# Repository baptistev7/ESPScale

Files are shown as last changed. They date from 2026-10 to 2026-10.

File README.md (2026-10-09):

# ESP Scale — balance connectée pour silo à granulés

Une balance sur batterie qui pèse un **silo à granulés** posé sur 4 pieds, affiche
le stock sur un **écran e-paper** et le publie en **MQTT** pour **Home
Assistant** (stock, consommation, coût des remplissages). Elle dort presque tout
le temps : deux mesures par jour, calées sur l'aspiration de la chaudière.

| Écran principal | Hors de sa base (recharge) | Portail de réglages |
|---|---|---|
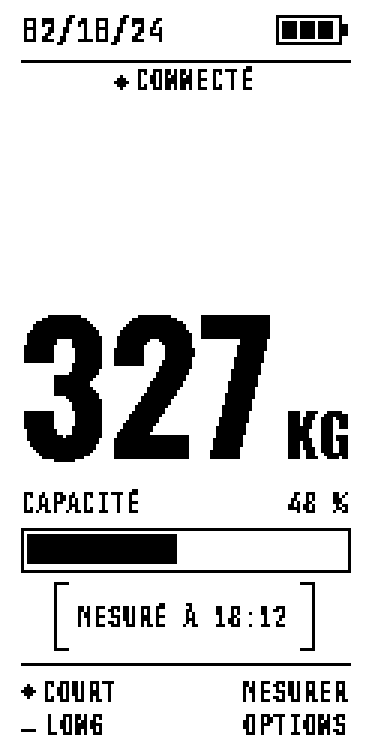
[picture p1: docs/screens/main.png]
Écran principal
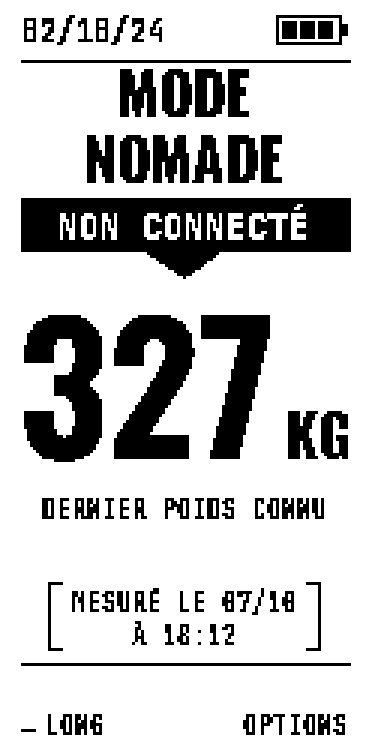
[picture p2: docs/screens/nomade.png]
Mode nomade
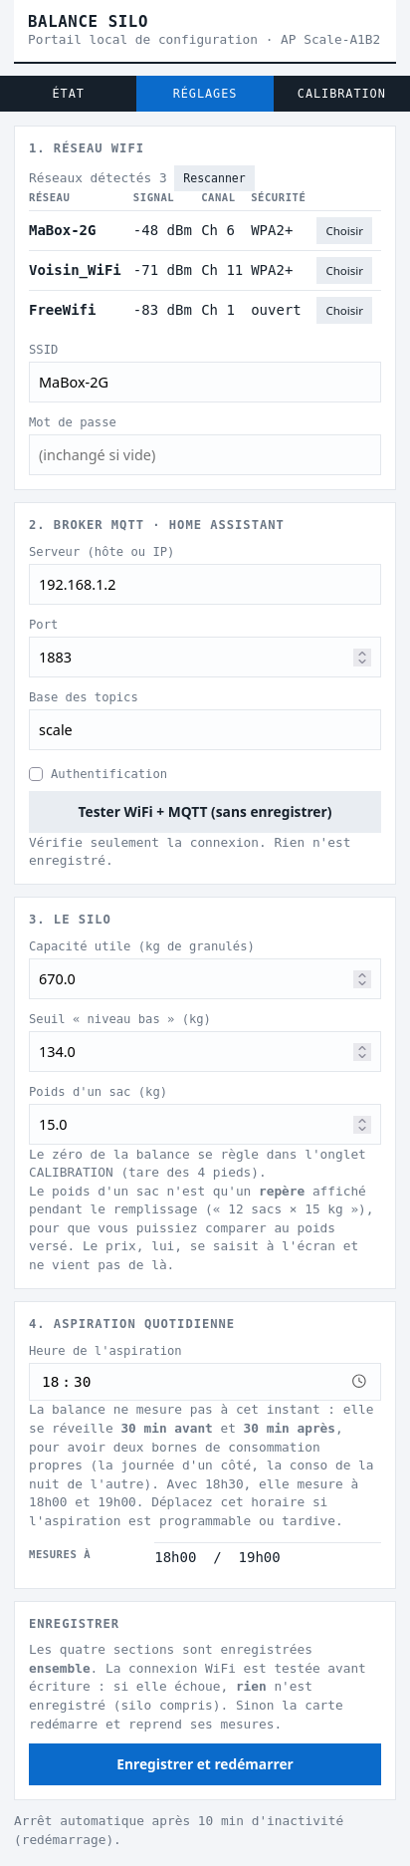
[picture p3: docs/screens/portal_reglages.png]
Portail web, onglet RÉGLAGES
|  |  |  |

**Version 1.0.1** — documentation en ligne : **<https://baptistev7.github.io/ESPScale/>**

## Ce qu'elle fait

- **Pèse le silo** avec 4 pieds (16 cellules de 50 kg, un HX711 par pied) et
  n'accepte une mesure que si **les 4 pieds répondent**.
- **Mesure 30 min avant et 30 min après l'aspiration** quotidienne (horaire
  réglable) pour séparer la consommation de la nuit des remplissages de la
  journée.
- **Publie en MQTT** seulement ce qui compte : les **baisses** (consommation) et
  les **remplissages** — jamais une dérive de capteur.
- **Guide le remplissage** sur place : nombre de sacs, prix, confirmation par
  appui maintenu ; Home Assistant valorise le stock en €.
- **Se recharge hors de sa base** : on retire le boîtier, on le branche en USB ;
  il le détecte, affiche la charge et revient tout seul à la normale une fois
  reposé.
- **Se règle sans recompiler** depuis un portail web embarqué (WiFi, MQTT,
  silo, calibration).

## Ce qu'il faut

- une carte **LilyGO T5 V2.4** 2.13" (ESP32 + écran e-paper intégré) ;
- **16 cellules de charge 50 kg** et **4 modules HX711** ;
- une **batterie LiPo** 1S, un connecteur **pogo**, deux résistances (1 MΩ et
  10 kΩ) ;
- le boîtier et la base imprimés en 3D (`case/v1/`) ;
- un broker **MQTT** et, idéalement, **Home Assistant**.

Détail : **[docs/MATERIEL.md](docs/MATERIEL.md)**.

## Démarrage

1. **Assembler et câbler** — pieds, base, boîtier, et les trois petites
   modifications de la carte : [MATERIEL.md](docs/MATERIEL.md).
2. **Flasher le firmware** (USB) avec [PlatformIO](https://platformio.org/) :

   ```bash
   ~/.platformio/penv/bin/pio run --target upload
   ```

   Pour une autre carte que celle du projet, mettre son identifiant de port dans
   `platformio.ini` (voir [CONFIGURATION.md](docs/CONFIGURATION.md#compiler-et-flasher)).
3. **Régler WiFi, MQTT et silo** — au premier démarrage, la balance ouvre un
   **portail web** : rejoindre le WiFi `Scale-XXXX` avec le mot de passe affiché
   à l'écran, puis `http://192.168.4.1` : [CONFIGURATION.md](docs/CONFIGURATION.md#le-portail-web).
4. **Calibrer les pieds** — onglet CALIBRATION du portail :
   [CALIBRATION.md](docs/CALIBRATION.md).
5. **Brancher Home Assistant** — packages prêts à l'emploi dans `ha/` :
   [MQTT-HOME-ASSISTANT.md](docs/MQTT-HOME-ASSISTANT.md).

Ensuite, au quotidien : **[le guide utilisateur](docs/GUIDE-UTILISATEUR.md)**.

## Documentation

Toute la documentation est publiée sur **<https://baptistev7.github.io/ESPScale/>**
(sources dans `docs/`).

| Document | Pour qui / pour quoi |
|---|---|
| [GUIDE-UTILISATEUR.md](docs/GUIDE-UTILISATEUR.md) | **Utiliser la balance** : écrans, bouton, remplissage, recharge |
| [MATERIEL.md](docs/MATERIEL.md) | Matériel, câblage, modifications de la carte, boîtier |
| [CONFIGURATION.md](docs/CONFIGURATION.md) | Flasher, portail web, réglages compilés (`config.hpp`) |
| [CALIBRATION.md](docs/CALIBRATION.md) | Calibrer les pieds, limites de la mesure, batterie |
| [MQTT-HOME-ASSISTANT.md](docs/MQTT-HOME-ASSISTANT.md) | Sujets MQTT, règles de publication, intégration Home Assistant |
| [FONCTIONNEMENT.md](docs/FONCTIONNEMENT.md) | Ce que fait le firmware : cycle, bouton, remplissage, mode nomade, écrans |
| [CONSOMMATION.md](docs/CONSOMMATION.md) | Mesures de consommation (PPK2), autonomie estimée, graphiques, diagnostics de veille |
| [DEPANNAGE.md](docs/DEPANNAGE.md) | Problèmes connus et leurs correctifs |
| [SPEC-ecrans.md](docs/SPEC-ecrans.md) | Spécification détaillée des écrans et transitions (développeurs) |
| [CHANGELOG.md](CHANGELOG.md) | Historique des versions |

## État du projet

- ✅ Firmware complet : mesure, publication, remplissage, mode nomade, portail,
  écrans (rafraîchissement partiel quand rien d'important ne change).
- ✅ Consommation mesurée au PPK2 : veille **33 µA** sur la base, **29 µA** hors
  base ; cycle de mesure **0,03 à 0,12 mAh**. Autonomie estimée **10 à 26 mois**
  sur une LiPo de 2000 mAh (autodécharge comprise) :
  [CONSOMMATION.md](docs/CONSOMMATION.md#autonomie).

## Structure du projet

```
ESPScale/
├── src/, include/        # Firmware (PlatformIO, Arduino ESP32)
│   ├── app.cpp           #   cycle de mesure, bouton, remplissage, mode nomade
│   ├── display.cpp       #   tous les écrans e-paper
│   ├── power.cpp         #   sommeil, réveils (ext0/ext1/ULP), batterie
│   ├── sensors.cpp       #   HX711
│   ├── mqtt.cpp, wifi.cpp, time.cpp
│   ├── webconfig.cpp     #   portail web
│   ├── settings.cpp      #   réglages en NVS
│   ├── scheduler.cpp     #   heures de réveil
│   ├── config.hpp        #   réglages compilés
│   └── pins.hpp          #   broches (source de vérité)
├── ha/                   # Packages Home Assistant + dashboard (voir ha/README_install.md)
├── case/v1/              # CAO du boîtier et de la base (PrusaSlicer)
├── docs/                 # Documentation (site GitHub Pages), captures, maquettes UI
├── tools/
│   ├── preview_charte.py # rendu pixel des écrans → docs/screens/
│   ├── portal_preview/   # captures du portail web → docs/screens/
│   ├── render_screens.py # primitives de rendu (fontes de la carte)
│   ├── consommation_graphs.py # graphiques de docs/CONSOMMATION.md
│   └── sleep_floor/      # diagnostic du plancher de veille
├── platformio.ini
├── AGENTS.md             # notes pour les outils de développement
└── CHANGELOG.md
```

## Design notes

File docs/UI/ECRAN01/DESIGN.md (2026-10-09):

---
name: Électronique Métrologique 122x250
colors:
  surface: '#faf9f5'
  surface-dim: '#dadad6'
  surface-bright: '#faf9f5'
  surface-container-lowest: '#ffffff'
  surface-container-low: '#f4f4f0'
  surface-container: '#eeeeea'
  surface-container-high: '#e8e8e4'
  surface-container-highest: '#e2e3df'
  on-surface: '#1a1c1a'
  on-surface-variant: '#4c4546'
  inverse-surface: '#2f312e'
  inverse-on-surface: '#f1f1ed'
  outline: '#7e7576'
  outline-variant: '#cfc4c5'
  surface-tint: '#5e5e5e'
  primary: '#000000'
  on-primary: '#ffffff'
  primary-container: '#1b1b1b'
  on-primary-container: '#848484'
  inverse-primary: '#c6c6c6'
  secondary: '#5e5e5e'
  on-secondary: '#ffffff'
  secondary-container: '#e2e2e2'
  on-secondary-container: '#646464'
  tertiary: '#000000'
  on-tertiary: '#ffffff'
  tertiary-container: '#1b1b1b'
  on-tertiary-container: '#848484'
  error: '#ba1a1a'
  on-error: '#ffffff'
  error-container: '#ffdad6'
  on-error-container: '#93000a'
  primary-fixed: '#e2e2e2'
  primary-fixed-dim: '#c6c6c6'
  on-primary-fixed: '#1b1b1b'
  on-primary-fixed-variant: '#474747'
  secondary-fixed: '#e2e2e2'
  secondary-fixed-dim: '#c6c6c6'
  on-secondary-fixed: '#1b1b1b'
  on-secondary-fixed-variant: '#474747'
  tertiary-fixed: '#e2e2e2'
  tertiary-fixed-dim: '#c6c6c6'
  on-tertiary-fixed: '#1b1b1b'
  on-tertiary-fixed-variant: '#474747'
  background: '#faf9f5'
  on-background: '#1a1c1a'
  surface-variant: '#e2e3df'
typography:
  headline-lg:
    fontFamily: JetBrains Mono
    fontSize: 28px
    fontWeight: '800'
    lineHeight: 28px
    letterSpacing: -0.5px
  headline-md:
    fontFamily: JetBrains Mono
    fontSize: 18px
    fontWeight: '700'
    lineHeight: 20px
    letterSpacing: 0px
  headline-sm:
    fontFamily: JetBrains Mono
    fontSize: 13px
    fontWeight: '700'
    lineHeight: 14px
    letterSpacing: 0.5px
  body-lg:
    fontFamily: JetBrains Mono
    fontSize: 11px
    fontWeight: '600'
    lineHeight: 13px
    letterSpacing: 0px
  body-md:
    fontFamily: JetBrains Mono
    fontSize: 10px
    fontWeight: '500'
    lineHeight: 12px
    letterSpacing: 0px
  body-sm:
    fontFamily: JetBrains Mono
    fontSize: 9px
    fontWeight: '500'
    lineHeight: 11px
    letterSpacing: 0px
  label-lg:
    fontFamily: JetBrains Mono
    fontSize: 9px
    fontWeight: '700'
    lineHeight: 10px
    letterSpacing: 0.75px
  label-md:
    fontFamily: JetBrains Mono
    fontSize: 8px
    fontWeight: '700'
    lineHeight: 9px
    letterSpacing: 0.5px
  label-sm:
    fontFamily: JetBrains Mono
    fontSize: 7px
    fontWeight: '700'
    lineHeight: 8px
    letterSpacing: 0.5px
spacing:
  gutter: 4px
  margin: 2px
  space-xs: 2px
  space-sm: 4px
  space-md: 6px
  space-lg: 8px
  space-xl: 12px
---

## Brand & Style

This design system defines an ultra-specialized, mission-critical interface engineered for the TTGO T5 ESP32 2.13-inch vertical electronic paper display (native resolution: 122 × 250 pixels). The system adopts an unyielding Industrial-Brutalist & Metrological aesthetic rooted in precision European instrumentation, rugged laboratory apparatus, and specialized field diagnostics.

The target audience comprises technical field operators, metrology technicians, and environmental monitoring specialists working in outdoor or harsh indoor environments where ambient glare, low refresh cycles, and zero-power bistable rendering dictate UI rules. The emotional response is one of total operational certainty: raw, calculated, indestructible, and unmistakably functional.

All visual grammar prioritizes 1-bit raster legibility. Anti-aliasing, intermediate greys, dropshadows, blurs, and soft radius curves are strictly forbidden within the digital viewport. Hierarchy is established exclusively through black-and-white field inversion, solid 1px and 2px dividing rules, high-density typographic weight shifts, and rigid coordinate plotting. Surrounding the display, the hardware casing balances this severe 1-bit digital viewport with a purposeful, matte industrial enclosure featuring softly radiused mechanical tooling.

## Colors

The system uses an uncompromising two-state color architecture formulated specifically for micro-encapsulated electrophoretic displays (e-ink / e-paper):

- **Display Field (Papier)**: `#f4f4f0` — Off-white, slightly warm electrophoretic substrate base. Simulates natural uncharged particle states while reducing harsh full-spectrum glare.
- **Active Ink (Encre)**: `#000000` — Deep, pure carbon black. Used for all glyphs, vector lines, borders, active bitmap glyphs, and inverted selection regions.
- **Hardware Enclosure (Boîtier)**: `#e2e3de` — Structural ABS matte chassis framing the active panel.
- **Hardware Highlight**: `#f9f9f7` — Beveled bezel boundary and tactile surface sheen.

Color variations, simulated half-tones, and CSS opacity filters below 100% are banned. To express hierarchy or active states, surfaces invert completely: `#000000` becomes the background slab and `#f4f4f0` becomes the cutout glyph/icon color. Dithering (Bayer 2×2 or checkerboard 1-bit stippling) is permitted solely for passive progress bars or inactive scale registers.

## Typography

Typography is locked to `JetBrains Mono` to guarantee monospaced predictability, tight horizontal metrics, wide apertures, and unmistakable glyph distinction on low-pixel budgets. 

Rules of composition:
- **Language**: French technical nomenclature. Headers and status designations are displayed in full uppercase (`ÉTAT`, `MESURE`, `RÉSEAU`, `BATTERIE`, `HISTORIQUE`). Diacritical marks must remain crisp; where vertical clearance is limited to 8px, abbreviated upper-case tokens may be used (`CONF.`, `PARAM.`, `TEMP.`).
- **Numerical Dominance**: The primary readout (`headline-lg`, 28px/800 weight) dominates the viewport center, allowing immediate glanceability from a 1.5-meter distance.
- **Labels & Micro-data**: Fixed-pitch mono labels enforce strict vertical alignment of decimals and units (`V`, `mA`, `hPa`, `°C`, `ppm`).
- **Rendering fidelity**: Always render with font-smoothing disabled or crisp pixel hinting to avoid partial-alpha grey fringing along curved stems.

## Layout & Spacing

The canvas is rigidly locked to an exact physical frame of **122 pixels wide by 250 pixels tall**. No responsive resizing or dynamic reflow is allowed. Every interface element is positioned using integer coordinates on this pixel grid.

### Vertical Zoning (250px Total Budget)
1. **Header Zone (`Y: 0 → 15`, height: 16px)**:
   - Full-bleed inverted solid black banner (`#000000`).
   - Displays station identifier, connection icon/status, and battery voltage indicator in `#f4f4f0`.
2. **Subheader / Mode Strip (`Y: 16 → 27`, height: 12px)**:
   - Categorical label and measurement mode in uppercase (`label-md`). Bottom border: 1px solid black.
3. **Primary Metric Hero (`Y: 28 → 95`, height: 68px)**:
   - Dedicated readout chamber. Hosts large values (28px weight), units of measure, and delta variance indicator.
4. **Secondary Data Matrix (`Y: 96 → 165`, height: 70px)**:
   - Two-column or three-row grid partitioned by 1px solid horizontal and vertical rules. Displays auxiliary telemetry (e.g., `MIN`, `MAX`, `MOY`).
5. **Graphic Register / Sparkline (`Y: 166 → 217`, height: 52px)**:
   - 1-bit point or stepped bar array representing historical metrics or status checklists.
6. **Interaction Bar / Footer (`Y: 218 → 249`, height: 32px)**:
   - Fixed tactile prompt zone. Top border: 2px solid black. Instructs the user on single-button navigation.

Margins are set strictly to 2px inner padding to avoid active e-paper gate lines at the physical panel edge. Gutters between dual data columns are fixed at 4px.

## Elevation & Depth

True physical depth does not exist on a bistable 1-bit display. Elevation and visual prominence are achieved exclusively through structural zoning, high-contrast borders, and polarity inversion:

- **Surface Level 0 (Base Display Surface)**: Raw electrophoretic paper `#f4f4f0`. All default metrics and data grids sit directly on this level.
- **Surface Level 1 (Framed Containers)**: Bounded regions enclosed with a continuous 1px solid `#000000` rule. Used for secondary cells and data grouping.
- **Surface Level 2 (Selected / Inverted Blocks)**: Full solid `#000000` background fill with cut-out `#f4f4f0` text and icons. Used for active modal focus, urgent warnings, or currently targeted menu rows.
- **No Drop Shadows, No Blurs, No Gradients**: Any gradient results in uncontrolled physical e-ink ghosting and edge flutter. Transitions between states must be binary and abrupt.

## Shapes

The digital coordinate space enforces absolute zero-radius geometry (`roundedness: 0`). 
- Every screen-drawn box, tag, progress track, list container, and inverted field terminates in strict 90-degree squared corners.
- Circular or diagonal geometries are accepted solely for native measurement glyphs (such as degree signs `°`, battery tip caps, or circular target indicators).

### Physical Enclosure Harmony
While the digital screen is relentlessly sharp and unyielding, the enclosing plastic chassis uses subtle mechanical radii (`3mm` to `4mm` on exterior casing corners) to provide pocketability and structural impact resistance. This juxtaposition emphasizes the precision glass instrument framed safely within a durable protective tool.

## Components

### 1. Navigation & Interaction Footer (Single-Button Grammar)
Because the TTGO T5 features only one physical hardware button, all interactions are mapped to two fundamental inputs:
- **Court (`●`)**: Short press (< 400ms). Used for cycle, increment, step forward (`SUIVANT`).
- **Long (`—`)**: Long press / hold (> 1000ms). Used for confirmation, entry, reset (`VALIDER` / `ENTRER`).

The footer component is a permanent 32px-high block anchored at the bottom edge (`Y: 218–249`):
- **Divider**: Top edge bounded by a solid 2px black stroke.
- **Content**: Split horizontally or vertically into clear command directives:
  - Top row: `[●] DÉFILER`
  - Bottom row: `[—] CONFIRMER`
- **Active execution**: During long press detection, a 2px horizontal solid black line fills from left to right across the bottom 3px of the screen to provide physical hold feedback.

### 2. Header Status Strip
- **Height**: 16px. Solid `#000000` fill.
- **Left**: Device state identifier (e.g., `TTGO-METR01` or `CH01`).
- **Center**: Acquisition status (`ACQ`, `PAUSE`, `ERREUR`).
- **Right**: 1-bit battery glyph (12×7px outline with interior segmented charge fill) accompanied by percentage text in 8px bold mono (`94%`).

### 3. Metric Value Display (Hero Unit)
- **Container**: 118px wide × 48px high.
- **Primary Value**: Large numerals (28px) aligned left or center-left.
- **Unit Badge**: Affixed to the upper-right of the integer (`V`, `hPa`, `PPM`, `°C`) in 10px bold text.
- **Trend Indicator**: Compact 7×7px 1-bit direction arrows (`▲`, `▼`, `■`) marking delta relative to preceding cycle.

### 4. Menus & Selection Lists
- **Row Height**: 16px per option.
- **Standard Row**: `#f4f4f0` background, `#000000` text, prefixed with empty bracket marker `[ ]`.
- **Selected Row**: Inverted `#000000` background slab extending full width (118px), text knocked out in `#f4f4f0`, prefixed with solid bracket marker `[X]` or filled square `[■]`.

### 5. Progress & Level Gauges
- **Dimensions**: 118px wide × 8px high.
- **Frame**: 1px solid black bounding rectangle.
- **Fill**: Solid black fill for linear progress. Segmented scales use 2px vertical dividers every 10% increment.
- **Dither Variant**: A 50% 1-bit checkerboard fill designates safe operating threshold limits or non-critical zones.

### 6. Hardware Enclosure Frame & Physical Button Indicator
- **Enclosure Dimension**: Visual representation of the hardware frame around the 122×250 viewport.
- **Frame Width**: Minimum 8px border on sides, 12px at top, 24px at bottom.
- **Material Tone**: Matte industrial pale gray/beige (`#e2e3de`).
- **Tactile Switch Cue**: Centered 6px below the display's bottom edge sits an engraved circular button icon (`Ø 10px`) debossed with an etched concentric circle and labeled `FUNC` or `SÉLEC`.

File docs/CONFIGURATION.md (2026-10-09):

---
title: Configuration
nav_order: 4
---

# Configuration

Comment compiler et flasher le firmware, puis tout régler **sans recompiler**
depuis le portail web embarqué. Les réglages « de développeur » restent dans
[`include/config.hpp`](https://github.com/baptistev7/ESPScale/blob/main/include/config.hpp).

## Sommaire

1. [Compiler et flasher](#compiler-et-flasher)
2. [Le portail web](#le-portail-web)
3. [`config.hpp` — réglages compilés](#confighpp--réglages-compilés)

## Compiler et flasher

Prérequis : [PlatformIO](https://platformio.org/) (extension VS Code ou CLI).

```bash
~/.platformio/penv/bin/pio run                    # compiler
~/.platformio/penv/bin/pio run --target upload    # flasher (carte en USB)
~/.platformio/penv/bin/pio device monitor         # logs série (115200 bauds)
```

> Utiliser le `pio` de l'environnement PlatformIO (`~/.platformio/penv/bin/`) :
> celui de certaines distributions est cassé.

**Port série** : [`platformio.ini`](https://github.com/baptistev7/ESPScale/blob/main/platformio.ini) désigne la carte par son
**identifiant stable** (`/dev/serial/by-id/usb-1a86_USB_Single_Serial_…`), pas
par `/dev/ttyACM0` — le numéro change selon l'ordre de branchement (un PPK2 de
mesure, par exemple, prend `ACM0`). **Pour une autre carte**, remplacer cet
identifiant par le sien :

```bash
ls /dev/serial/by-id/
```

Aucun réglage réseau n'est dans le code : une carte fraîchement flashée démarre
dans le portail.

## Le portail web

### Y entrer

- **Carte neuve / sans configuration** : elle démarre **directement dans le
  portail** (elle n'aurait aucun réseau où publier). Si on le ferme sans
  enregistrer, elle **se met en veille** (écran « CARTE EN VEILLE ») ; un appui
  sur le bouton rouvre le portail.
- **Sur demande** : **appui long** sur l'écran principal → menu `OPTIONS` →
  `PORTAIL RÉGLAGES` → **maintenir le bouton 2,5 s** sur l'écran de
  confirmation.

L'écran affiche alors **« PORTAIL ACTIF »** avec tout ce qu'il faut pour s'y
connecter :

| Carte configurée | Carte sans configuration |
|---|---|
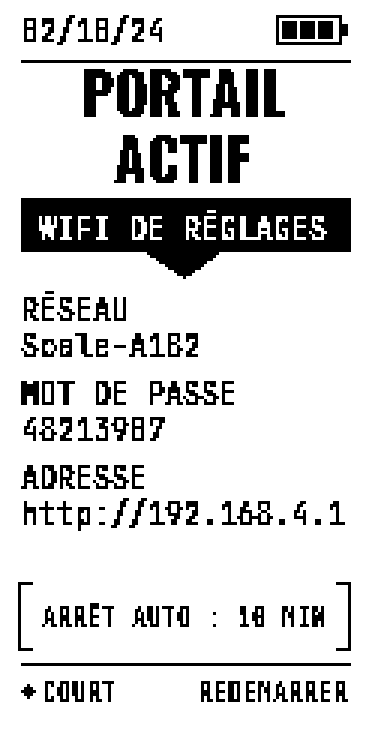
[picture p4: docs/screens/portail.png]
Écran PORTAIL ACTIF
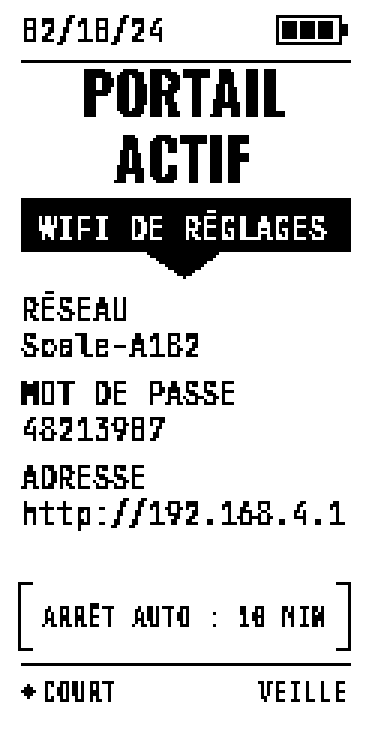
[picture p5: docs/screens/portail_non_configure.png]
Écran PORTAIL ACTIF, pied VEILLE
|  |  |

1. Rejoindre le WiFi **`Scale-XXXX`** avec le **mot de passe à 8 chiffres**
   affiché (tiré à chaque ouverture : il faut être devant la balance).
2. Ouvrir **`http://192.168.4.1`**.

Le portail **se ferme seul après 10 min** sans activité (`PORTAL_TIMEOUT_MIN`),
ou par un **appui court** (`● COURT REDEMARRER`) : la carte redémarre. Sans
configuration enregistrée, elle se met en veille à la place.

### Les 3 onglets

| ÉTAT | RÉGLAGES | CALIBRATION |
|---|---|---|
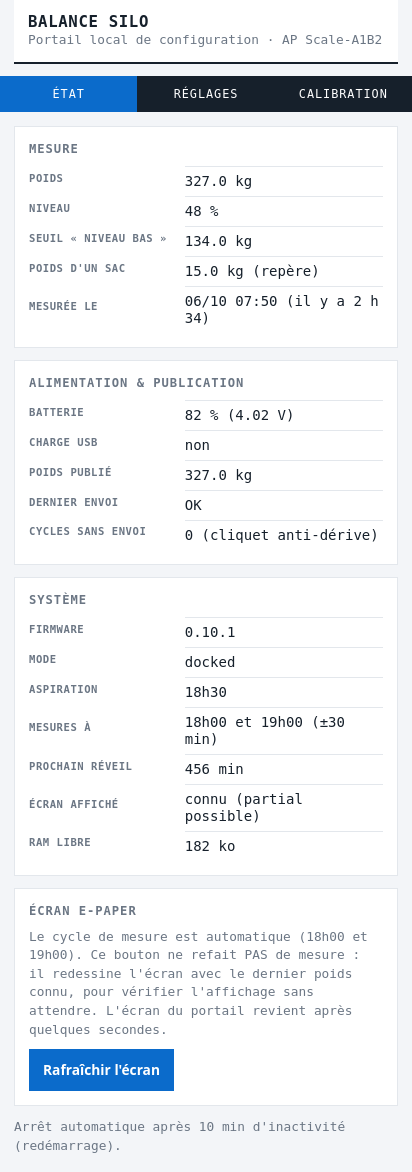
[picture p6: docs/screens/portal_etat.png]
Portail, onglet ÉTAT
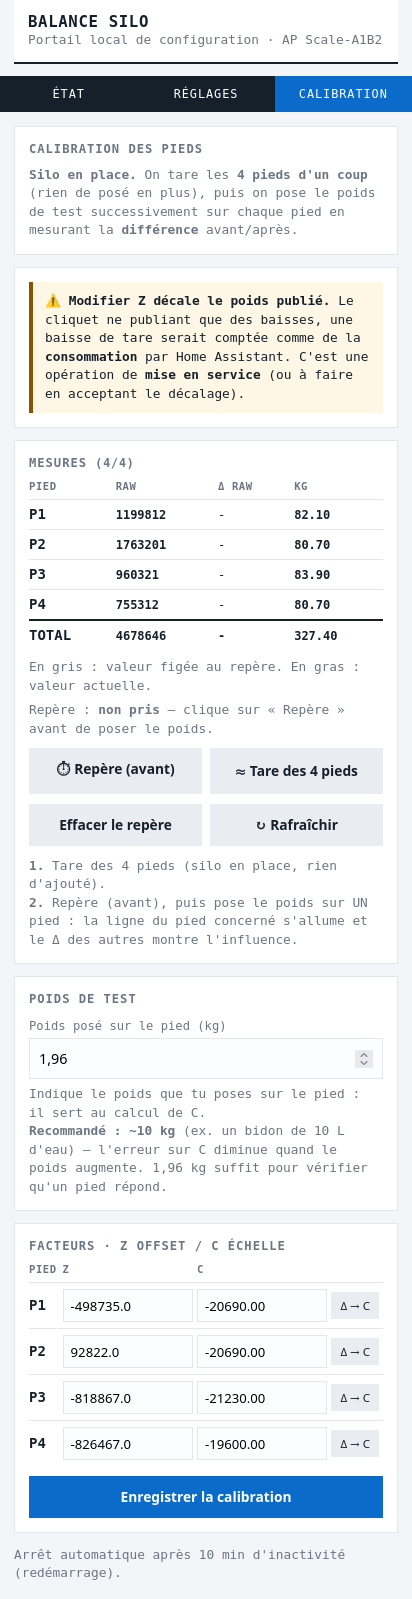
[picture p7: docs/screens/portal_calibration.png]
Portail, onglet CALIBRATION
|  | Portail, onglet RÉGLAGES |  |

**1. ÉTAT** — ce que la carte sait maintenant : poids, niveau en %, seuil
« niveau bas », dernière mesure, batterie, dernier envoi MQTT, mode, prochain
réveil, RAM libre. Une valeur inconnue s'affiche `--`. Le bouton **Rafraîchir
l'écran** redessine l'e-paper avec le dernier poids mesuré (ce n'est **pas** une
nouvelle mesure) ; l'écran du portail revient seul après ~8 s.

**2. RÉGLAGES** — un seul formulaire, un seul bouton **« Enregistrer et
redémarrer »** :

- **Réseau WiFi** : liste des réseaux visibles (« Choisir » recopie le SSID),
  ou saisie manuelle pour un réseau masqué. La connexion est **testée avant
  d'écrire** : si elle échoue, rien n'est enregistré.
- **Broker MQTT** : serveur (**hôte seul**, ex. `192.168.1.2`), port, base des
  topics, authentification optionnelle. Le tableau des sujets publiés est
  affiché. **« Tester WiFi + MQTT »** vérifie le réseau et le broker sans rien
  enregistrer.
- **Aspiration quotidienne** : l'heure à laquelle la chaudière aspire. La
  balance mesure **30 min avant et 30 min après** (défaut 18h30 → mesures à
  18h00 et 19h00) pour séparer la conso de la nuit des remplissages de la
  journée.
- **Le silo** : capacité utile, seuil « niveau bas » et poids d'un sac, en kg.

Les mots de passe enregistrés ne sont **jamais** renvoyés dans la page : un
champ laissé vide veut dire « inchangé ». Les actions destructrices demandent
confirmation.

**3. CALIBRATION** — calibration des 4 pieds, voir
[CALIBRATION.md](CALIBRATION.md).

> Les captures sont générées depuis le vrai code du portail :
> `tools/portal_preview/render.sh` compile `src/webconfig.cpp` sur PC et capture
> chaque onglet (à relancer après toute modification du portail).

### Détails techniques

- Tout est stocké en **NVS** (`settings.cpp`) ; la calibration a ses propres
  clés, indépendantes du WiFi.
- Le geste qui ouvre le portail est absorbé avant d'écouter le bouton (sinon le
  relâchement fermerait aussitôt le portail).
- `webConfigRun()` ne rend jamais la main : « sortir » du portail, c'est
  redémarrer — d'où le libellé `REDEMARRER`.

## `config.hpp` — réglages compilés

Ce qui n'est pas dans le portail. Les valeurs à jour font foi dans
[`include/config.hpp`](https://github.com/baptistev7/ESPScale/blob/main/include/config.hpp).

### Réseau et MQTT

```cpp
#define FW_VERSION "…"                    // publié sur <base>/version
constexpr uint16_t MQTT_PORT = 1883;      // défaut du formulaire
#define MQTT_TOPIC_BASE_DEFAULT "scale"   // défaut du formulaire
#define MQTT_SEND_DELTA_KG 1.0f           // publie si baisse >= 1 kg
#define MQTT_BATTERY_DELTA_PCT 5          // ... ou si |Δbatterie| >= 5 %
#define MQTT_HEARTBEAT_CYCLES 8           // ... ou tous les 8 cycles
#define WIFI_CONNECT_TIMEOUT_SEC 15
```

### Matériel

```cpp
#define USE_DOCK_WAKE_DOUT 1    // réveil dédock/redock par DOUT — exige la 1 MΩ
#define USE_CHRG_ULP 1          // réveil de charge par l'ULP en mode nomade
#define USE_EPD_PWR_CUTOFF 1    // coupure écran par GPIO 12 (V2.4)
#define BATTERY_VOLTAGE_RATIO 2.0833f
#define BATTERY_SHUTDOWN_THRESHOLD_V 3.3f
#define BATTERY_EMERGENCY_THRESHOLD_V 3.2f
#define TANK_FULL_KG 670.0
#define BAG_KG 15               // défaut du poids d'un sac
```

`USE_CHRG_ULP` se surcharge à la compilation pour une mesure comparative :
`PLATFORMIO_BUILD_FLAGS="-DUSE_CHRG_ULP=0" pio run`.

### Capteurs

Facteurs d'étalonnage par défaut (`Z_FACTOR_1..4`, `C_FACTOR_1..4`) — remplacés
par ceux du portail dès qu'une calibration est enregistrée. Lecture :
`SENSOR_READ_ATTEMPTS`, `SENSOR_READ_DELAY_MS`, `SENSOR_READY_TIMEOUT_MS`.

### Réveils (`scheduler.hpp`)

| Constante | Rôle |
|---|---|
| `kWakeOffsetMin = 30` | mesures 30 min avant / après l'aspiration |
| `kNomadeDayStartMin = 2` | mode nomade : réveil à 00:02 (nouvelle date) |
| `kNomadeChargePollSec = 300` | mode nomade en charge : réveil toutes les 5 min |
| `kBatteryUsableMah`, `kNomadeSleepCurrentUa` | estimation du « quart de batterie » (réveil de secours) |

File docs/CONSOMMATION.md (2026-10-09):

---
title: Consommation
nav_order: 7
---

# Consommation — T5 V2.4

Ce document rassemble **les mesures de consommation** de la balance, **la
méthode** pour les refaire, et **ce qu'elles ont appris** sur la carte LilyGO
T5 V2.4. Tout ce qui est écrit « mesuré » l'a été au PPK2 ; tout le reste est
marqué comme estimation ou « à mesurer ».

## Sommaire

1. [En bref](#en-bref)
2. [Banc de mesure](#banc-de-mesure)
3. [Mesures](#mesures)
4. [Ce que la carte consomme en sommeil — et pourquoi](#ce-que-la-carte-consomme-en-sommeil--et-pourquoi)
5. [Mesures sur la base (dock)](#mesures-sur-la-base-dock)
6. [Autonomie](#autonomie)

## En bref

- **Le plancher de la carte est de 27 µA**, pas 192 µA : les 192 µA mesurés
  jusqu'ici venaient de broches laissées dans leur état de démarrage
  (pull-ups internes actives), pas de la carte elle-même.
- **Une broche tenue haute vers le réseau `VCC_IO` coupé coûte des centaines
  de µA** : c'est le cas de **GPIO 14** (SCK du HX711 n°3, aussi CLK du lecteur
  SD avec sa pull-up 10 kΩ) — **+190 à +480 µA** selon le reste de la
  configuration.
- **GPIO 19 tenue basse** : +87 µA (cause non identifiée) ; haute : 0. Elle
  remplace GPIO 14 comme SCK du pied 3.
- **L'ULP, RTC_PERIPH, ext0** : aucun coût mesurable.
- **Firmware corrigé, veille nomade : 29,1 µA** (386 µA avant) — à 2 µA du
  plancher. La SCK du pied 3 passe de GPIO 14 à **GPIO 19** pour que la veille
  **sur la base** en profite aussi (à mesurer).

- **Sur la base (mesuré, 8 oct. 2026)** : veille **33 µA** ; cycle de mesure
  **120 à 140 mC** sans publication, **315 à 420 mC** avec ; démarrage à froid
  500 à 710 mC. Autonomie estimée : **~10 mois (pessimiste) à ~26 mois
  (optimiste)**, dominée par la veille et l'autodécharge de la LiPo.

## Banc de mesure

| Élément | Rôle |
|---|---|
| **Nordic PPK2** en **mode source, 4,0 V** | remplace la batterie (connecteur batterie de la carte) et mesure le courant à 100 kHz |
| **USB de la carte débranché** | sinon c'est l'USB qui alimente la carte, pas le PPK2 |
| Script Python ([`ppk2-api`](https://pypi.org/project/ppk2-api/)) | pilote le PPK2, découpe éveils / sommeil, écrit un CSV moyenné à la ms |

Le script de mesure (`ppk2-api`, boucle d'échantillonnage à 100 kHz, découpe des
éveils au-dessus de 5 mA) n'est **pas conservé dans ce dépôt**. Les phases
détaillées plus bas (capteurs, WiFi + NTP, affichage, MQTT) ont été découpées
avec un **firmware de banc** qui émettait des repères sur GPIO 13, lus par
l'entrée **D0** du PPK2, avec une veille raccourcie à 15 s. Déroulé : flasher le
firmware à mesurer (USB branché), **débrancher l'USB**, puis lancer la mesure
avec démarrage à froid (coupure puis remise sous tension du PPK2).

> Le PPK2 apparaît en `/dev/ttyACM0`/`ACM1` et décale la carte en `ACM2` :
> c'est pourquoi `platformio.ini` désigne la carte par son **identifiant
> stable** (`/dev/serial/by-id/…`), jamais par `ttyACMx`.

## Mesures

Conditions communes : PPK2 4,0 V, USB débranché, boîtier **hors de la base**
(aucun HX711 alimenté), fil CHRG sur GPIO 34 + pull-up 10 kΩ en place,
pull-down 1 MΩ sur le DOUT du pied 1 en place.

### Firmware 0.12.0 (veille nomade)

| Mesure | Résultat |
|---|---|
| Cycle de démarrage → mode nomade (capteurs 2,1 s, WiFi + NTP, WiFi + MQTT, écran complet) | **13,6 s**, 51 mA moyen, pic 617 mA, **694 mC ≈ 0,19 mAh** |
| Veille nomade, **ULP armé** (CHRG + DOUT) | **386,5 µA** |
| Veille nomade, **sans ULP** (ext0 sur DOUT) | **386,5 µA** — l'ULP ne coûte rien |
| **Veille nomade, firmware corrigé** (ULP armé, GPIO 14 relâchée, GPIO 19 sans pull) | **29,1 µA** |
| Cycle démarrage → nomade, firmware corrigé | 14,0 s, 703 mC (inchangé) |

### Sketch minimal (écran coupé, timer seul)

| Mesure | Résultat |
|---|---|
| Réveil (démarrage + mise en sommeil) | 73 ms, 48 mA moyen, 3,5 mC |
| Sommeil | **193 µA** |

Même matériel que ci-dessus : le fil CHRG, la pull-up de GPIO 34 et la
pull-down 1 MΩ ne coûtent rien hors USB. **L'écart 193 → 386 µA vient donc du
firmware.**

### Diagnostic n°1 — quelle broche du firmware coûte ?

Sommeil de 20 s par étape, chaque étape ajoute un réglage de la veille du
firmware au sketch minimal :

| Étape | Ajout | Sommeil |
|---|---|---|
| 0 | minimal | **193 µA** |
| 1 | + **GPIO 14 tenue haute** (SCK n°3) | **463 µA** (+270) |
| 2 | + SCK 32, 27, 21 tenues hautes | 463 µA |
| 3 | + RTC_PERIPH alimenté + ext0 sur DOUT | 463 µA |
| 4 | + pull-downs du balayage (2, 13, 15, 19) | 386 µA |
| 5 | + lignes de l'écran tenues basses (5, 16, 17, 18, 23) | 673 µA |

### Diagnostic n°2 — plancher de la carte

Projet [`tools/sleep_floor/`](https://github.com/baptistev7/ESPScale/tree/main/tools/sleep_floor/) (indépendant du firmware).
Sommeil de 20 s par étape :

| Étape | Configuration | Sommeil |
|---|---|---|
| 0 | minimal : écran coupé (GPIO 12 bas), timer seul | **192,8 µA** |
| 1 | + domaines optionnels forcés OFF (RTC_PERIPH, RTC_FAST_MEM, XTAL, RTC8M, VDD_SDIO) | 192,2 µA |
| 2 | + broches libres¹ reconfigurées en entrée **avec pull-down** | **27,1 µA** |
| 3 | + broches libres¹ reconfigurées en entrée **sans pull** | **27,1 µA** |
| 4 | + **GPIO 19 tenue basse** | 114 µA (+87) |
| 5 | + UART (1, 3) en entrée sans pull | 114 µA |
| 6 | + isolation des GPIO par l'IDF | 114 µA |

¹ 2, 4, 5, 13, 14, 15, 16, 17, 18, 21, 22, 23, 25, 26, 27, 32, 33 — ni 0 (BOOT),
ni 12 (coupure écran), ni 34-39 (entrées seules).

## Mesures sur la base (dock)

Conditions : PPK2 4,0 V, USB débranché, boîtier **posé sur la base** (4 HX711
alimentés puis en power-down), WiFi + broker joignables, firmware 0.12.1 (avant le partial de l'écran principal) +
repères de banc. Tous ces chiffres sont **mesurés** sauf mention.

### Veille

| Mesure | Résultat |
|---|---|
| Veille sur la base (3 runs de 60 s + 1 de 100 s) | **32,9 à 33,2 µA** |

L'estimation précédente était 31 µA + modules : les 4 HX711 en power-down
coûtent ~2 µA au total (écart de deux chiffres, non mesuré séparément).

### Démarrage à froid (heure invalide : NTP complet, affichage complet, MQTT)

3 runs, puis 1 run du second banc :

| Phase | Durée | Courant moyen | Charge |
|---|---|---|---|
| Capteurs | 0,71 s | 54,9 mA | 38,7 mC |
| WiFi + NTP | 3,5 à 7,6 s | 70 à 76 mA | 262 à 535 mC |
| Affichage complet | 1,52 s | 64 à 70 mA | 98 à 106 mC |
| MQTT | 0,06 à 0,08 s | 130 mA | 8 à 10 mC |
| Fin de cycle | 0,12 s | 39 mA | 4,5 mC |
| **Cycle complet** | 7,1 à 10,5 s | 67 à 70 mA | **499 / 523 / 583 / 707 mC** |

Le WiFi + NTP pèse 65 à 75 % de la charge et sa durée varie du simple au
double d'un essai à l'autre : c'est la source de dispersion.

Trace du courant sur 100 s

### Réveils timer (heure valide, cycle planifié)

Réveils toutes les 15 s sur le banc, un cycle sur deux avec publication :

| Cycle | Durée | Charge | Détail |
|---|---|---|---|
| Sans publication, affichage partiel | 2,16 s | **120 mC** | affichage 1,22 s / 71 mC |
| Sans publication, affichage 1,5 s | 2,46 s | **139 mC** | affichage 1,52 s / 89 mC |
| Sans publication, **affichage évité** (même minute) | 0,96 s | **50 mC** | cas du banc seulement, voir ci-dessous |
| Avec publication, affichage partiel | 5,89 s | **421 mC** | WiFi + NTP 3,65 s / 279 mC ; affichage 1,22 s / 82 mC |
| Avec publication, affichage évité | 4,47 s | **315 mC** | WiFi + NTP 3,55 s / 261 mC |

Charge par cycle

- Le partial coûte 1,2 s et 70 à 82 mC contre 1,5 s et ~100 mC en complet :
  **~20 à 25 mC gagnés par cycle**, soit moins de 0,01 mAh/jour.
- « Affichage évité » n'arrive sur le banc que parce que deux cycles tombent dans
  la même minute. En usage réel (cycles espacés de ~12 h), l'heure de mesure
  change toujours : il y aura **toujours au moins un partial**.
- Le réveil de 00:02 en dock (partial de la date seule) est **validé sur la
  carte** (minuit simulé, partial de l'en-tête) mais sa **consommation n'est pas
  mesurée**. Estimation : ~80 à 100 mC (démarrage + partial, sans capteurs ni
  réseau).
- Non déterminé : l'affichage de 1,52 s du second cycle était-il un partial avec
  réécriture de l'ancienne image, ou un complet.

## Autonomie

Mode **sur la base** uniquement (2 réveils de mesure par jour, plus le réveil de
00:02 pour la date). Le nomade (29 µA, poll de charge) n'est pas compté. Les
boutons (mesure à la demande, menu, remplissage) ne le sont pas non plus.

### Hypothèses

| | Optimiste | Pessimiste | Origine |
|---|---|---|---|
| Veille | 33 µA | 40 µA (marge) | mesuré / marge |
| Cycle sans publication | 120 mC | 139 mC | mesuré |
| Cycle avec publication | 385 mC | 707 mC | 315 + partial 71 (calculé) / pire mesuré |
| Publications par jour | 0,25 (heartbeat tous les 4 jours) | 2 (chaque cycle, conso ≥ 1 kg) | hypothèse d'usage |
| Réveil de 00:02 | 80 mC | 100 mC | estimé, non mesuré |
| Capacité nominale | 2000 mAh | 2000 mAh | `MATERIEL.md` |
| Capacité utilisable | 90 % (1800 mAh) | 70 % (1400 mAh) | hypothèse : coupure à 3,3 V, vieillissement |
| Autodécharge LiPo | 2 %/mois (1,33 mAh/jour) | 5 %/mois (3,33 mAh/jour) | **valeurs génériques, non mesurées** |

### Consommation par jour

| | Optimiste | Pessimiste |
|---|---|---|
| Veille | 0,79 mAh | 0,96 mAh |
| Cycles de mesure + réveil de 00:02 | 0,11 mAh (386 mC) | 0,42 mAh (1 514 mC) |
| **Total (hors autodécharge)** | **0,90 mAh/jour** | **1,38 mAh/jour** |
| Autodécharge | 1,33 mAh/jour | 3,33 mAh/jour |
| **Total avec autodécharge** | **2,23 mAh/jour** | **4,71 mAh/jour** |

Consommation par jour

### Autonomie

Autonomie estimée

| | Optimiste | Pessimiste |
|---|---|---|
| Sans autodécharge | 2 000 jours (~5,5 ans) | 1 014 jours (~2,8 ans) |
| **Avec autodécharge** | **~806 jours (~26 mois)** | **~297 jours (~10 mois)** |

- **La veille domine** (60 à 70 % de la consommation de la carte) et
  l'**autodécharge de la batterie est supérieure à tout le reste**. Les
  économies de cycle (partial d'affichage : <0,01 mAh/jour) ne changent presque
  rien à l'autonomie.
- Le levier qui compte : la **veille** (33 µA = 0,79 mAh/jour), puis le nombre de
  publications avec WiFi (2 à 5 fois le coût d'un cycle sans publication).
- Le chiffre pessimiste dépend surtout de deux hypothèses **non mesurées** :
  l'autodécharge et la capacité utilisable. Les deux se mesurent avec une batterie
  réelle laissée au repos.

## Ce que la carte consomme en sommeil — et pourquoi

### Le réseau `VCC_IO`

Sur la T5 V2.4, le régulateur **U6** (rail `VCC_IO`) est coupé par **GPIO 12**
pour éteindre l'écran. D'après le schéma (V2.3, partie alimentation identique
hors GPIO 12), ce rail alimente aussi :

- l'**écran** e-paper ;
- les **pull-ups 10 kΩ du lecteur micro-SD**, sur GPIO **2, 13, 14, 15**.

Rail coupé, ces résistances deviennent des **pull-downs 10 kΩ vers un rail à
0 V**. Deux conséquences mesurées :

- **une broche tenue HAUTE** sur ce réseau réalimente le rail à travers la
  10 kΩ, et le rail à demi alimenté débite à son tour dans tout ce qui y est
  relié : **GPIO 14 haute = +190 à +480 µA** ;
- **une pull-up interne active** sur ces broches (état de démarrage de
  certaines pads) débite de la même façon — c'est l'essentiel des
  **193 → 27 µA** gagnés en reconfigurant les broches libres. *Les broches
  précises n'ont pas été isolées une à une.*

C'est aussi pourquoi **CHRG ne fonctionne pas sur GPIO 13 ou 15** (ligne lue
basse en permanence) et a été placé sur **GPIO 34** avec une pull-up externe
vers **+3V3** (le 3,3 V de l'ESP, pas `VCC_IO`).

### GPIO 19

Diagnostic n°3, au plancher (broches libres sans pull), GPIO 19 seule modifiée :

| GPIO 19 en sommeil | Sommeil |
|---|---|
| non touchée | 27,6 µA |
| **tenue haute** | **27,6 µA** |
| tenue basse | 114,7 µA (+87) |
| pull-down | 27,6 µA |
| pull-up | 27,6 µA |

Seul l'état bas coûte (cause non identifiée : aucune LED visible sur la carte).
Une SCK de HX711 est haute pendant tout le sommeil : GPIO 19 accueille donc la
SCK du pied 3 à la place de GPIO 14.

### Ce qui ne coûte rien (mesuré)

- le coprocesseur **ULP** (lit CHRG + DOUT toutes les ~400 ms) ;
- **RTC_PERIPH** maintenu (ext0 ou ULP) ;
- les domaines optionnels (`esp_sleep_pd_config`) ;
- les SCK **32, 27, 21** tenues hautes (hors base) ;
- le fil **CHRG** + pull-up 10 kΩ sur GPIO 34, et la pull-down **1 MΩ** du
  DOUT (hors USB, boîtier hors base).

## Estimation sur la base

Veille **sur la base** (état le plus courant), à partir des mesures ci-dessus :

| Poste | Valeur | Source |
|---|---|---|
| Carte, broches bien configurées | 27 µA | mesuré |
| Pull-down 1 MΩ, DOUT haute (boîtier posé) | 3,3 µA | calculé |
| ext0 / RTC_PERIPH | ~0 | mesuré |
| 4 HX711 en power-down | < 1 µA chacun (fiche technique) ; **modules non mesurés** | à mesurer |
| SCK du pied 3 tenue haute, **sur GPIO 19** | 0 (sur GPIO 14 : +190 à +480 µA) | mesuré |

**Estimation : ~31 µA + modules HX711** — **mesuré ensuite : 33 µA** (voir
[Mesures sur la base](#mesures-sur-la-base-dock)).

## Historique

### T5 V2.3.1 (mesures périmées)

Conservées pour comparaison ; **ne s'appliquent plus** à la carte actuelle.

| Phase (V2.3.1) | Durée | Courant moyen | Charge |
|---|---|---|---|
| Capteurs (init + lecture 4×HX711) | 1,152 s | 59,2 mA | 68,2 mC |
| Affichage (un rendu e-paper) † | ~1,40 s | ~52 mA | ~73 mC |
| WiFi/MQTT (connexion + NTP + publication) † | 1,732 s | ~94 mA | 163,2 mC |
| Cycle sans changement | 2,549 s | 55,4 mA | 141,2 mC |
| Cycle complet | 4,281 s | 71,1 mA | 304,5 mC |
| Deep sleep (base branchée) | 5,196 s | 231,4 µA | 1,20 mC |

† Déduits des deux cycles. Autonomie V2.3.1 calculée : ~5,7 mAh/jour, ~10 mois.

### Notes

- **T5 V2.3.1** (carte précédente) : mesures périmées pour la V2.4.
- **V2.4, avant ce document** : « 192 µA, plancher de la carte » — **faux** :
  c'était le plancher d'un firmware qui laissait les broches dans leur état de
  démarrage.

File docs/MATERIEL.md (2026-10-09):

---
title: Matériel
nav_order: 3
---

# Matériel

Ce qu'il faut, comment le câbler, et les quelques modifications à faire sur la
carte. Les broches font foi dans [`include/pins.hpp`](https://github.com/baptistev7/ESPScale/blob/main/include/pins.hpp).

## Sommaire

1. [Vue d'ensemble](#vue-densemble)
2. [Liste du matériel](#liste-du-matériel)
3. [La carte LilyGO T5 V2.4](#la-carte-lilygo-t5-v24)
4. [Câblage](#câblage)
5. [Modifications de la carte](#modifications-de-la-carte)
6. [Boîtier et base](#boîtier-et-base)
7. [Historique — T5 V2.3.1](#historique--t5-v231)

## Vue d'ensemble

```
            ┌──────────── silo à granulés (ne bouge jamais) ────────────┐
            │                                                            │
   pied 1 ──┤ 4 cellules 50 kg → HX711 ┐                                 │
   pied 2 ──┤ 4 cellules 50 kg → HX711 ├── BASE ── pogo ══ pogo ── BOÎTIER (ESP32 + écran + batterie)
   pied 3 ──┤ 4 cellules 50 kg → HX711 │                 ↑
   pied 4 ──┤ 4 cellules 50 kg → HX711 ┘                 └ « dédock » = retirer le boîtier
```

- **La base** porte les 4 pieds (cellules + HX711) et une moitié du connecteur
  **pogo**. Elle reste sous le silo.
- **Le boîtier** contient la carte, l'écran, la batterie et l'autre moitié du
  pogo. On le **retire de sa base** pour le recharger en USB ou intervenir : c'est
  le **dédock**, un geste normal et récurrent (le firmware passe alors en **mode
  nomade**, voir [FONCTIONNEMENT.md](FONCTIONNEMENT.md#mode-nomade-hors-de-la-base)).

## Liste du matériel

| Élément | Quantité | Remarque |
|---|---|---|
| LilyGO **T5 V2.4** 2.13" (ESP32 + e-paper DEPG0213BN) | 1 | la V2.3.1 marche mais demande d'autres modifs (voir [Historique](#historique--t5-v231)) |
| Cellules de charge **50 kg** | 16 | 4 par pied |
| Module **HX711** | 4 | un par pied |
| Batterie LiPo 1S (connecteur 2 broches 1,25 mm) | 1 | 2000 mAh utilisés pour les calculs |
| Connecteur **pogo** (paire) | 1 | relie boîtier et base |
| Résistance **1 MΩ** | 1 | réveil au retrait / à la remise sur la base |
| Résistance **10 kΩ** | 1 | pull-up de la détection de charge |
| Fil fin | — | ligne CHRG |
| Boîtier + base imprimés | 1 | [`case/v1/`](https://github.com/baptistev7/ESPScale/tree/main/case/v1/) |

## La carte LilyGO T5 V2.4

- **ESP32-D0WDQ6**, micro-USB, puce USB-série **CH9102** : la carte apparaît en
  `/dev/ttyACM*` (pas `ttyUSB*`).
- **Écran** DEPG0213BN (contrôleur SSD1680, 122 × 250 utiles), piloté par le
  driver `EpdPanel` (GDEY0213B74 + LUT partielle du 213_BN).
- **Charge batterie** : TP4054 + régulateur, pas d'IP5306 (aucun registre I2C
  d'état de charge).
- **Nouveauté de la V2.4** : **GPIO 12 coupe l'alimentation de l'écran**
  (régulateur U6, rail `VCC_IO`). LilyGO ne publie que le schéma de la V2.3 ; la
  V2.4 n'en diffère que par cette coupure (et le correctif de reset qui va avec).

### Le piège du rail `VCC_IO`

Le rail `VCC_IO`, coupé avec l'écran, alimente **aussi les pull-ups 10 kΩ du
lecteur micro-SD** (inutilisé), sur **GPIO 2, 13, 14, 15**. Rail coupé, ces
résistances tirent ces broches **vers 0 V** :

- une broche **tenue haute** sur ce réseau le réalimente et consomme
  (**GPIO 14 = +190 à +480 µA**, mesuré) ;
- une entrée sur ce réseau **lit 0** quand l'écran est éteint — ces broches ne
  conviennent pas pour lire un signal (c'est pour ça que CHRG est sur GPIO 34).

Détail et mesures : [CONSOMMATION.md](CONSOMMATION.md#le-réseau-vcc_io).

**GPIO 19** consomme +87 µA si elle est tenue **basse** en sommeil (cause non
identifiée, aucune LED visible) ; haute, en pull-up ou en pull-down : rien
(mesuré). Elle porte la SCK du pied 3, haute pendant tout le sommeil.

### Broches utilisées

| Fonction | GPIO |
|---|---|
| Écran : CS / DC / RST / BUSY / SCK / MOSI | 5 / 17 / 16 / 4 / 18 / 23 |
| Écran : coupure d'alimentation (`EPD_PWR_EN`, haut = alimenté) | 12 |
| Bouton (Button 1, entrée seule, pull-up de la carte) | 39 |
| Batterie (pont diviseur de la carte) | 35 |
| **CHRG** du TP4054 (+ pull-up externe 10 kΩ) | **34** |
| HX711 pied 1 : DOUT / SCK | 25 / 32 |
| HX711 pied 2 : DOUT / SCK | 22 / 21 |
| HX711 pied 3 : DOUT / SCK | 33 / **19** (pas 14, voir plus haut) |
| HX711 pied 4 : DOUT / SCK | 26 / 27 |
| À ne pas utiliser | 0 (BOOT), 2/13/14/15 (réseau `VCC_IO`) |

## Câblage

### HX711 → carte (à travers le pogo)

| HX711 | Carte |
|---|---|
| VCC | 3,3 V (fil **rouge**, commun aux 4 modules) |
| GND | GND (fil **noir**, commun) |
| DOUT | GPIO DOUT du pied (tableau ci-dessus) |
| SCK | GPIO SCK du pied |

Le numéro de pied est celui de `pins.hpp` / `config.hpp` (`Z_FACTOR_1`…) et de
l'écran INFORMATIONS (`Pied 1` … `Pied 4`). Pour savoir quel pied est où :
appuyer sur un coin du silo et regarder quelle ligne monte (OPTIONS →
INFORMATIONS, page 2).

> ⏳ Mapping repris de la V2.3.1, **à revalider sur la base** avec la V2.4.

### Écran

Intégré à la carte (connecteur FPC), rien à câbler.

### Batterie

Connecteur batterie de la carte. Le pont diviseur intégré (GPIO 35) mesure la
tension ; son ratio (`BATTERY_VOLTAGE_RATIO`) se calibre au multimètre (voir
[CALIBRATION.md](CALIBRATION.md#batterie)).

## Modifications de la carte

Trois petites modifications, toutes **côté boîtier** :

### 1. Détection de charge — fil CHRG → GPIO 34 + pull-up 10 kΩ

- Souder un fil sur la broche **CHRG du TP4054** (U11, patte 1 ; drain ouvert,
  tirée à 0 V pendant la charge) et le relier à **GPIO 34**.
- Souder une **10 kΩ entre GPIO 34 et +3V3** (le 3,3 V de l'ESP, **pas**
  `VCC_IO`).
- Coût : ~0 sur batterie (CHRG est ouverte hors charge), 0,33 mA pendant la
  charge, payés par l'USB.
- Sert à afficher l'**éclair** de charge et à **réveiller la carte** quand on
  branche / débranche l'USB en mode nomade (coprocesseur ULP).

> Pas GPIO 13 / 15 (réseau `VCC_IO`, lues à 0 écran éteint), ni GPIO 19 (ne peut
> pas réveiller la carte).

### 2. Réveil au dédock / redock — 1 MΩ sur le DOUT du pied 1

- Souder une **1 MΩ entre GPIO 25 (DOUT du pied 1) et GND**, **côté boîtier**
  (avant le pogo, sinon elle part avec la base).
- Principe : un HX711 alimenté et en veille (SCK tenue haute) **tient DOUT à 1**.
  Boîtier retiré, plus rien ne pilote la ligne : la 1 MΩ la ramène à **0**. La
  carte se réveille sur ce changement — dans un sens comme dans l'autre.
- Coût : 3,3 µA boîtier posé, 0 retiré.
- Activé par `USE_DOCK_WAKE_DOUT = 1` (`config.hpp`). **Sans la résistance, le
  laisser à 0** : une ligne flottante réveillerait la carte en boucle.

### 3. SCK du pied 3 sur GPIO 19 (pas 14)

La SCK d'un HX711 reste **haute pendant tout le sommeil** (c'est ce qui le garde
éteint). Sur GPIO 14, elle réalimentait `VCC_IO` par la pull-up 10 kΩ du lecteur
SD : **+190 à +480 µA**. Sur **GPIO 19**, tenue haute ne coûte rien (mesuré).
Déplacer le fil SCK du pied 3 de GPIO 14 vers GPIO 19, côté boîtier.

> Alternative non retenue : garder GPIO 14 et dessouder sa pull-up 10 kΩ du
> lecteur SD.

## Boîtier et base

Fichiers CAO dans [`case/v1/`](https://github.com/baptistev7/ESPScale/tree/main/case/v1/) : boîtier vertical + base (dock),
connexion pogo, fixation du connecteur, ailettes.

| Fichier | Contenu |
|---|---|
| `PelletScale.3mf` | projet PrusaSlicer complet (objets `Main`, `BackMain`, `Support`, `BackSupport`) |
| `Main.3mf` / `BackMain.3mf` | boîtier, face avant / dos |
| `Support.3mf` / `BackSupport.3mf` | base, dessus / dos |

Les maillages se modifient par script Python (`trimesh` + `manifold3d`).

## Historique — T5 V2.3.1

Carte précédente ; ces modifications **ne sont pas** à refaire sur la V2.4.

1. **Pull-ups 100 kΩ RST/CS → 3V3** (pattes 10 et 12 du FPC) : sans coupure
   d'alimentation de l'écran, CS/RST flottaient en sommeil et le SSD1680 sortait
   d'hibernation (veille 750 → 250 µA). Inutile sur la V2.4.
2. **Fil CHRG → GPIO 19** : fonctionnait, mais GPIO 19 ne peut pas réveiller la
   carte (broche non RTC).
3. Couper l'alimentation de l'écran demandait de souder sous l'écran collé :
   c'est ce que la V2.4 apporte d'origine (GPIO 12).

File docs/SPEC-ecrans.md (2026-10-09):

---
title: Spécification des écrans
nav_order: 10
---

# SPEC — Écrans e-paper et transitions

**Statut** : spécification de l'interface embarquée (dalle 122 × 250, 1 bit).
**Périmètre** : quels écrans existent, ce qui les déclenche, quels gestes ils
acceptent, comment ils se rafraîchissent. **Sources de vérité** : `src/app.cpp`
(déclencheurs, FSM de remplissage, menu `OPTIONS`, confirmation du portail),
`src/display.cpp` (rendu), `src/scheduler.cpp` (sommeils), `src/power.cpp`
(reveils armés), `src/webconfig.cpp` (portail), `src/settings.cpp` (droit d'accès
au portail), `enum DisplayScreen` (`include/state.hpp`).

**Aucun écran n'est plus rendu dans l'ancien style** (polices Adafruit
FreeMono, silo ÖkoFEN vectoriel) : tout passe par les composants de la charte
(`docs/UI/BASE-DESIGN.md`). L'écran « capteurs KO » et l'écran texte « TEST »
ont été supprimés.

**Registre** : les énoncés en **DOIT** sont des règles ; **DEVRAIT** une
recommandation admettant une exception ; **PEUT** une option. Chaque énoncé
non normatif décrit le firmware **tel qu'il est** — ce qui n'est pas câblé est
signalé 🔜, ce qui est câblé autrement que l'écran ne l'annonce est signalé ⚠️.

**Charte UI** : ✅ migré (`docs/UI/ECRANnn`) · 🎨 ancien style · 🔜 à faire.
**Charte de rendu** : `docs/UI/BASE-DESIGN.md` (grille, polices, composants).

| Écran (`DisplayScreen`) | Rendu | Charte |
|---|---|---|
| `MAIN` | principal (poids + jauge) ; variante `CAPTEUR(S) HS` (dernier poids stable) | ✅ `ECRAN01`/`02` |
| `DEDOCK` | MODE NOMADE (dernier poids connu) | ✅ `ECRAN17` |
| `OPTIONS` | menu 4 entrées (dont `FERMER`) — **3 entrées hors base** | ✅ `ECRAN03` / `ECRAN22` |
| `INFORMATIONS` | 2 pages : état général / répartition | ✅ `ECRAN18`/`19` |
| `PORTAL_CONFIRM` | confirmation de démarrage du portail | ✅ `ECRAN07` |
| `CONFIG` | portail actif | ✅ `ECRAN04` |
| `UNCONFIGURED` | « CARTE EN VEILLE » — carte sans configuration, en veille | ✅ (pas de maquette) |
| `REFILL_LIVE` | parcours — étape 1/3, poids versé en direct | ✅ `ECRAN11` |
| `REFILL_BAGS` | parcours — étape 2/3, nombre de sacs | ✅ `ECRAN12` |
| `REFILL_PRICE` | parcours — étape 3/3, prix du sac par digits | ✅ `ECRAN13` |
| `REFILL_CONFIRM` | parcours — « TERMINER ? », le maintien enregistre | ✅ `ECRAN14` |
| `REFILL_FIX` | parcours — « CORRIGER ? » (court sur `REFILL_CONFIRM`) | ✅ (pas de maquette) |
| `REFILL_SAVED` | parcours — « ENREGISTRÉ » (récap, 1 min) | ✅ `ECRAN15` |

---

## 0. Carte des transitions

```
   ┌─────────┐  court : mesure à la demande      ┌───────────────┐
   │  MAIN   │──────────────────────────────────▶│ cycle de mesure│──▶ MAIN / DEDOCK /
   │ poids + │  long : ouvre le menu              │  (pub MQTT si Δ)│
   │ jauge   │──────────────┐                     └───────────────┘
   └────▲────┘              ▼                            ▲
        │            ┌───────────────┐                   │
        │            │   OPTIONS     │ 4 entrées :        │
        │            │ REMPLISSAGE   │                    │
        │            │ PORTAIL RÉGL. │──▶ PORTAL_CONFIRM ──maintien 2,5 s──▶ CONFIG
        │            │ INFORMATIONS  │──▶ INFORMATIONS p1 → p2              (redémarre)
        │            │ FERMER        │──▶ MAIN (dernier poids connu, sans remesure)
        │            └───────┬───────┘        puis deep sleep
        │                    │ court = ligne suivante (partial) · long = choisir
        │
        │   REMPLISSAGE (choix dans le menu) — le prix se saisit APRÈS le versement :
        │
        │   ┌─────────────────┐   ● court   ┌──────────────┐   long VALIDER  ┌──────────────┐
        └──▶│ REFILL_LIVE     │────────────▶│ REFILL_BAGS  │───────────────▶│ REFILL_PRICE │
            │ poids en direct │             │ ● +1 sac     │                │ ● +1 digit   │
            │ (sonde 3 s)     │             └──────────────┘                └──────┬───────┘
            └─────────────────┘                                                  │ mesuré « après »
                                                                                  ▼
                            ┌──────────────────────┐   maintien 2,5 s   ┌────────────────────┐
                            │ REFILL_CONFIRM       │───────────────────▶│ REFILL_SAVED       │
                            │ « TERMINER ? »       │◀───────────────────│ « ENREGISTRÉ »     │
                            │ barre de maintien     │                    │ récap, 1 min       │
                            └──┬───────────▲───────┘                    └─────────┬──────────┘
                     ● court   │           │ RETOUR / correction faite          │ ● court
                               ▼           │ (re-mesure « après »)              │ (ou long)
                            ┌──────────────┴───────┐                            ▼
                            │ REFILL_FIX           │ NOMBRE DE SACS ─▶ REFILL_BAGS (depuis 0)
                            │ « CORRIGER ? »       │ PRIX DU SAC ───▶ REFILL_PRICE
                            │ ● suivant · — choisir│ ANNULER ───────▶ abandon
                            └──────────────────────┘
                     tenue interrompue sur REFILL_CONFIRM : la barre se vide, rien d'autre
                     timeout 10 min (CONFIRM ou FIX) ─▶ abandon (DOCKED + cycle normal)
                     fin de REFILL_SAVED ─▶ MAIN (poids déjà mesuré) puis deep sleep

   Déplacement du boîtier (0/4) pendant le parcours :
     mesure « avant » faite ─▶ DEDOCK + refill_pending = BEFORE_MEASURE ─▶ (redock) ▶ REFILL_LIVE
     mesure « après » faite ─▶ DEDOCK + refill_pending = AFTER_MEASURE  ─▶ (redock) ▶ REFILL_CONFIRM
     (timeout 1 h sans redock → abandon, retour DOCKED)

   DEDOCK (nomade) : court = inerte (le redock se voit par DOUT ou au poll complet)
                     long  = OPTIONS

   Carte SANS configuration :
     démarrage / bouton ─▶ CONFIG ─(court, ou arrêt auto sans enregistrement)─▶
     UNCONFIGURED « CARTE EN VEILLE » + deep sleep 24 h (contrôle batterie seul,
     sans redessin) ; ● court (réveil) ─▶ CONFIG

   ------- hors cycle de publication -------
   CONFIG ──« Tester WiFi + MQTT »──▶ le verdict revient dans la PAGE WEB
           (l'e-paper n'affiche rien pendant le test, ~15-20 s)
```

## 1. Entrées — ce qui décide de l'écran au réveil

**Règle** — un réveil MUST produire exactement un écran, choisi par la cause de
réveil puis par le mode courant. `appRun()` (`src/app.cpp`) :

```
appRun()
 ├─ réseau OU broker non enregistré :
 │    ├─ TIMER ───────────────────────────────────▶ veille (UNCONFIGURED déjà affiché, rien n'est redessiné)
 │    └─ autre réveil ────────────────────────────▶ CONFIG (portail)
 │           └─ sortie sans enregistrement ─────────▶ UNCONFIGURED « CARTE EN VEILLE » + veille 24 h
 ├─ TIMER (créneaux ±30 min autour de l'aspiration, nomade 00:02 / 5 min en charge) ┐
 ├─ COLD_BOOT (reset / power-on) ─────────────────┼──▶ appRunScheduledCycle()
 ├─ GPIO ext0 (ligne DOUT = dédock/redock) ────────┘
 └─ GPIO bouton ───────────────────────────────────▶ appHandleExternalWake()
```

**Règle** — le portail de configuration **DOIT** être atteignable par **deux et
seules** entrées :
1. **au démarrage**, si le réseau **ou** le broker MQTT n'est pas enregistré en
   NVS (`settingsHasStored()` — les deux clés sont exigées). Tout autre réglage
   absent (calibration des pieds, base des topics, identifiants) **DOIT** rester
   à sa valeur par défaut et **NE DOIT PAS** déclencher le portail : une carte
   calibrée pour rien mais connectée est opérationnelle ;
2. **sur demande**, depuis `OPTIONS` → « PORTAIL RÉGLAGES », après la page de
   confirmation (cf. §5).

Le bouton GPIO 39 maintenu au cold boot **NE DOIT PAS** ouvrir le portail : cet
accès était une troisième entrée, non annoncée à l'écran, qui levait un point
d'accès sans le dire.

**Règle** — `MAIN` **NE DOIT PAS** être une session interactive : l'écran
principal **DOIT** toujours finir en deep sleep. Un réveil au bouton donne donc
exactement deux lectures, et **elles sont celles que le pied annonce** :

| Appui au réveil | Effet |
|---|---|
| **court** | mesure à la demande → `appRunScheduledCycle()` (mesure + `MAIN` + publication si Δ) puis sommeil |
| **long** (≥ 1 s) | ouvre `OPTIONS` (`appOptionsMenu`) |

**Règle** — le lancement d'un remplissage **NE DOIT PAS** être attaché à un appui
long sur `MAIN` : il part de l'entrée `REMPLISSAGE` du menu. Un geste unique ne
doit pas enchaîner une saisie de prix puis un enregistrement ; le menu rend chaque
étape explicite et réversible.

`appHandleExternalWake()` selon le **mode courant** (`ScaleMode`) :

| Mode | Appui **court** (●) | Appui **long** (—) |
|---|---|---|
| `DOCKED` / `DEGRADED` | mesure à la demande → `appRunScheduledCycle` | `OPTIONS` (`appOptionsMenu`) |
| `REFILL_POURING` | reprise : on rejoue la phase « versement » depuis le début (`refillPourAndSave`) — c'est l'endroit où l'utilisateur se trouve | idem |
| `REFILL_PRICING` | reprise de la saisie du prix (`refillStepPrice` → mesure « après » → E14) | idem |
| `DEDOCKED` | — (inerte : le redock se voit par la ligne DOUT ou au poll complet) | **`OPTIONS`** : le menu |

La reprise par le bouton n'existe que par sécurité (reset / watchdog au milieu du
parcours) : la granularité de reprise est le **mode**, donc `REFILL_POURING`
reprend au début du versement (étapes 1 et 2 partagent ce mode) et
`REFILL_PRICING` reprend exactement sur la saisie du prix (chiffres et nombre de
sacs sont en RAM RTC).

**Règle** — `DEDOCKED` couvre les deux cas 0/4 (dédock confirmé *et* panne
capteur) : les deux affichent l'écran nomade. Une panne partielle (1-3/4) est `DEGRADED` →
`MAIN` en variante `CAPTEUR(S) HS`.

---

## 2. Sorties — sommeil et réveils armés

**Règle** — toute session interactive **DOIT** se terminer par `goToSleep()`,
qui arme le(s) réveil(s) correspondant(s) au mode courant. `goToSleepFor(sec)`
est la même chose avec une durée imposée.

**Règle** — en veille nomade, le redock réveille la carte par la ligne DOUT :
le timer ne sert qu'à tenir l'écran à jour. Hors charge, elle dort jusqu'à
**00:02** (ou le quart de batterie estimé, `kNomadeQuarterSec` ≈ 94 j, s'il
tombe avant) ; **en charge**, toutes les **5 min** (`kNomadeChargePollSec`) ;
horloge invalide, toutes les heures. Tant que la date affichée est celle du
jour, un réveil est un poll **léger** (la charge seule) ; quand elle a changé
(réveil de 00:02), c'est le poll **complet** (capteurs, garde batterie, synchro
NTP si > 24 h, écran redessiné). Un réveil qui **DOIT** mesurer — redock,
démarrage — **NE DOIT PAS** être traité comme un poll léger
(`appRunScheduledCycle(force_full)`).

| Mode | Sommeil | Réveil(s) armé(s) | Timer |
|---|---|---|---|
| `DOCKED` | prochain créneau = **aspiration ±30 min** (aspiration réglable dans le portail, défaut 18h30 → 18h00 et 19h00 ; +15 s de compensation de dérive RTC ; 12 h si l'heure RTC est invalide) | ext1 bouton + **ext0 DOUT sur LOW** (dédock) | oui |
| `DEGRADED` | idem `DOCKED` | ext1 bouton **seul** | oui |
| `DEDOCKED` — **poll léger** | en charge **5 min**, sinon jusqu'à **00:02** — CHARGE seule (ADC + partial de la zone d'en-tête si les segments ou l'éclair ont changé). Ni HX711, ni publication. Aussi sur appui court | ext1 bouton + **ULP** (`USE_CHRG_ULP`) : DOUT haute = redock, CHRG ≠ éclair affiché pendant 1 s = charge (sans ULP : ext0 DOUT sur HIGH) | oui |
| `DEDOCKED` — **poll complet** | le réveil de **00:02** (date changée) — capteurs, garde batterie, NTP si > 24 h, écran redessiné | idem | oui |
| carte **non configurée** | **24 h** (`kUnconfiguredSleepSec`, 1 semaine sous 3,3 V) — contrôle batterie seul. Écran `UNCONFIGURED` dessiné **une fois** à l'entrée en veille (`appUnconfiguredSleep`), jamais redessiné par les réveils timer | ext1 bouton (→ portail) | oui |
| `REFILL_POURING` / `REFILL_PRICING` | — : le parcours se fait carte **éveillée**, il ne dort jamais dans ce mode | — | — |

Contraintes :
- `DEGRADED` **NE DOIT PAS** armer ext0 : un pied HS peut tenir la ligne DOUT
  basse → réveil en boucle garanti. Le dédock sera vu au cycle suivant.
- Le timer de secours **DOIT** toujours être armé : une carte qui ne dort que sur
  le bouton peut rester muette indéfiniment.
- ext0 **DOIT** être armé sur le niveau **opposé** à l'état courant, sinon le
  niveau déjà actif provoquerait un réveil immédiat en boucle.
- En veille nomade, l'ULP **remplace** ext0 (l'IDF refuse les deux ensemble) et
  attend pour CHRG l'**éclair affiché** : un écart au moment du sommeil réveille
  la carte, qui se corrige. Hors nomade, l'ULP **DOIT** être arrêté (il l'est à
  chaque réveil, `disarmNomadeUlpWakeup()`).
- Urgences batterie, mesurées au réveil avant toute mesure : `< 3,3 V` → cycle
  **sauté** (aucun écran, l'image précédente reste), sommeil = prochain
  créneau ; `< 3,2 V` → **24 h** ; 3ᵉ réveil consécutif en urgence → **1 semaine**
  (`kCriticalSleepSec`).

---

## 3. Cycle planifié — `appRunScheduledCycle()`

**Règles**, dans cet ordre :

1. **Remplissage interrompu** — trouver le mode `REFILL_POURING` /
   `REFILL_PRICING` au réveil veut dire qu'un reset (watchdog, chute de tension)
   a coupé le parcours, puisqu'il ne dort jamais dans ce mode. Le cycle **DOIT**
   le traiter en **abandon** (`refillAbandon()`) : rien n'est publié par le
   parcours, retour `DOCKED`, cycle normal (refill sauvage si versement).
2. **Batterie** — sous `BATTERY_SHUTDOWN_THRESHOLD_V` (3,3 V) le cycle **DOIT**
   être sauté **sans redessiner d'écran** ; l'image précédente reste.
3. **Mesure 4/4** — l'écran est **DOIT** être :
   - `DEDOCK` (MODE NOMADE) si 0/4 : « 0 capteur » veut dire « hors base » ;
   - `MAIN` avec `-1` si 1-3/4 (dégradé) : bandeau `CAPTEUR(S) HS` (gabarit du
     niveau bas, le bandeau HS prime sur `NIVEAU BAS`), état `● KO`, **dernier
     poids stable** (`last_measure_kg`, RAM RTC) avec sa jauge, daté en zone
     secondaire (`DERNIÈRE MESURE` / `STABLE À hh:mm` si du jour, sinon
     `STABLE LE jj/mm`, `STABLE (SANS HEURE)` sans horodatage) — jamais une
     mesure actuelle ; sans aucune mesure : héros `--` et `AUCUNE MESURE` ;
   - `MAIN` (poids + jauge) si la mesure est valide, zone secondaire
     `MESURÉ À hh:mm` (`MESURE STABLE` sans heure valide). Si poids arrondi,
     jauge, bandeau, batterie et éclair sont ceux déjà affichés, l'écran **NE
     DOIT PAS** faire de full : partial plein cadre (date de l'en-tête et heure de
     mesure), ou rien si elles n'ont pas changé non plus. Un retour d'erreur
     annoncée (`announced_error != DOCKED`, ex. redock) **DOIT** publier l'état
     (`error=off`, `quality`) même si le poids n'a pas bougé.
4. **Reprise** — un `refill_pending` (refill interrompu par un dédock) **DOIT**
   reprendre au bon endroit : `BEFORE_MEASURE` → re-mesure « avant » puis
   `REFILL_LIVE` ; `AFTER_MEASURE` → re-mesure « après » puis `REFILL_CONFIRM`
   (rien n'ayant encore été publié). Au-delà de **1 h** sans redock, le flag
   **DOIT** être effacé (abandon propre).
5. **Deep sleep** — durée et réveils selon §2.

**Règle** — l'en-tête **DOIT** porter une date **valide** sur tous les écrans. Le
RTC interne dérive de plusieurs % (oscillateur RC, pas de quartz 32 kHz) et il est
**perdu à chaque coupure d'alimentation** : sans synchro NTP on afficherait
`--/--/--` (arrêt à froid) ou une date fausse de plusieurs dizaines de minutes par
jour. L'heure **DOIT** donc être récupérée sur TOUS les chemins qui dessinent un
écran, y compris ceux qui n'ouvrent pas de session réseau pour publier :

| Chemin | Récupération de l'horloge |
|---|---|
| session réseau déjà ouverte (publication) | `publishBegin()` → `timeInit()` (inchangé) |
| **veille nomade** (transition) | `appSyncClockIfStale()` avant de dessiner l'écran nomade |
| **veille nomade** (poll léger, toutes les heures si l'heure est invalide) | réessai si l'heure est encore invalide, puis **redessin** de l'écran |
| **veille nomade** (poll complet de 00:02) | `appSyncClockIfStale()` (recale la dérive RTC), puis **redessin** : nouvelle date |
| cycle **sans** publication (palier gelé) | `appSyncClockIfStale()` avant `displayShowMain` |

`appSyncClockIfStale()` n'ouvre une session **que** si l'heure est invalide ou
vieille de plus de **24 h** (drapeau `g_ntp_last_sync` en RAM RTC) : le cas
courant ne coûte donc aucun réveil réseau, y compris sur les polls de charge.

**Règle** — l'en-tête **DOIT** montrer l'état de **charge** (éclair à gauche du
bloc batterie) sur **tous** les écrans : c'est le seul signe qui distingue « sur
USB » d'une simple batterie descendante, et l'en-tête est le seul composant
partagé par tous les écrans. Tout ce que l'en-tête dessine à droite du `x = 72`
**DOIT** tenir dans la fenêtre de partial 48 × 19 (éclair 78..87, batterie
92..115) : c'est la seule zone d'en-tête qui bouge, partagée par `MAIN` et par
l'écran nomade. Maquette de référence : `ECRAN21` (variante en charge de
l'écran principal), rendu pixel dans `docs/screens/main_charge.png` (`tools/preview_charte.py --docs`).

**Règle** — un état d'erreur **déjà annoncé** (`announced_error`) **NE DOIT PAS**
redessiner l'écran : en `DEDOCKED` le cycle **PEUT** ne rafraîchir que l'icône
batterie (`displayShowNomadeBattery`, partial zoné) si le % ou la charge a
changé ; en `DEGRADED` il **NE DOIT** rien redessiner du tout.

---

## 4. Parcours de remplissage (6 écrans)

```
   OPTIONS ── REMPLISSAGE ──▶ refillStart
        ├─ garde batterie (3,3 V) ─────────────────────────▶ abandon
        └─ refillPourAndSave()
             ├─ mesure « avant »  ─▶ REFILL_LIVE   (sonde 3 s, partial si ≥ 0,5 kg)
             │      dédock ─▶ DEDOCK + refill_pending = BEFORE_MEASURE (reprise au redock)
             │      ● court ─▶ REFILL_BAGS
             │      long ─ inerte (rien à faire d'autre)
             ├─ REFILL_BAGS    ● court = +1 sac (partial) · long = valider
             │      dédock ─▶ DEDOCK + refill_pending = BEFORE_MEASURE
             ├─ REFILL_PRICE   ● court = +1 digit (partial) · long = digit suivant
             │      long sur le dernier = valider
             │      timeout 10 min ─▶ abandon
             ├─ refillMeasureAfterAndConfirm()   mesure « après », delta
             │      dédock ─▶ DEDOCK + refill_pending = AFTER_MEASURE
             │      delta < 0 ─▶ abandon · capteurs 1-3/4 ─▶ dégradé
             └─ REFILL_CONFIRM  maintien 2,5 s (récap recalculé à chaque passage)
                    ├─ complet ─▶ publication (poids + palier + event) ─▶ REFILL_SAVED
                    │                 └─ ● court (ou long, alias) / 1 min ─▶ MAIN + sommeil
                    ├─ tenue interrompue ─▶ la barre se vide, REFILL_CONFIRM reste
                    ├─ ● court ─▶ REFILL_FIX « CORRIGER ? » (rien n'est publié)
                    │     ├─ NOMBRE DE SACS ─▶ REFILL_BAGS (depuis 0) ─┐
                    │     ├─ PRIX DU SAC ─▶ REFILL_PRICE (1er chiffre) ─┤
                    │     │       mesure « après » ─▶ REFILL_CONFIRM ◀──┘ (nouveau maintien)
                    │     ├─ ANNULER ─▶ abandon (refill sauvage s'il y a eu versement)
                    │     ├─ RETOUR ─▶ REFILL_CONFIRM
                    │     └─ timeout 10 min ─▶ abandon
                    └─ timeout 10 min ─▶ abandon

  abandon = refillAbandon() : rien n'est publié par le parcours, retour DOCKED
            puis cycle de mesure normal → refill sauvage si hausse ≥ ~1 sac
```

**Règle** — les six écrans **DOIVENT** être enchaînés sans deep sleep (une seule
session interactive) ; les gestes sont captés par l'ISR timer, donc rien n'est
perdu pendant un refresh ou le WiFi.

**Règle** — le prix **DOIT** être saisi **après** le versement, pas avant : le
prix se retient mieux que le poids, mais exiger un bouton tenu pendant tout le
versement n'est pas acceptable. Le parcours est donc `poids → sacs → prix →
validation`.

### 4.1 Les 3 étapes ✅

Les étapes partagent le **même squelette** (`drawRefillStepBody()` =
`drawRefillHero()` + `drawProgressBar()`), seule la donnée change :

| # | Héros | Contexte (sous le héros) | Bandeau | Pied |
|---|---|---|---|---|
| 1/3 | poids ajouté + `KG` | `Total : … kg` / `Niveau : … %` | `EN COURS` | `● COURT SUIVANT` (seule action) |
| 2/3 | nombre de sacs | `Théorie : N kg` (nb × `BAG_KG`) | `NOMBRE DE SACS` | `● COURT + 1 SAC` / `— LONG VALIDER` |
| 3/3 | prix saisi **par digits**, une case sur le digit courant | `Total : … €` (sacs × prix) | `PRIX PAR SAC` | `● COURT PLUS` / `— LONG SUIVANT` (`VALIDER` sur le dernier) |

**Règles** communes aux 3 étapes :
- le squelette **DOIT** être celui de `drawRefillStepBody()` : titre `REMPLISSAGE`
  (45), bandeau + pointe (66 → 92), héros (152), contexte (176 / 190), barre
  d'avancement en zone secondaire (10 cases, `(step × 10) / 3` pleines → 3 / 6 /
  10) avec le compteur `n/3`, pied. **Ni sous-titre d'étape, ni étiquette au-dessus
  du héros** : le bandeau nomme l'étape et le héros se lit avec son contexte ;
- la barre d'avancement **DOIT** être identique sur les 3 écrans (mêmes 10 cases,
  même cadre, même position, même compteur `n/3`) : elle est le **seul**
  indicateur d'étape, donc seul le nombre de cases pleines change ;
- toute modification d'une étape **DOIT** passer par le corps commun, sinon les
  trois écrans dérivent l'un de l'autre ;
- les gestes **DOIVENT** être rafraîchis en partial zoné sur la fenêtre
  120 × 122 px (y 94 → 215) : le poids, le nombre de sacs et le prix changent
  pendant la saisie, un full par pas serait inutilisable ;
- le signe `€` **DOIT** être rendu par les polices : il est stocké dans le slot
  `0x100` (juste au-dessus de Latin-1) et `U+20AC` est replié sur ce slot par le
  décodeur UTF-8 (`utf8Next`). Un `last` à `0x20AC` aurait exigé 8237 entrées de
  glyphe (49 ko de flash) pour un seul caractère.

**Règles** de l'étape 1 :
- le poids ajouté **DOIT** être l'élément le plus gros et le plus noir de l'écran ;
- le suivi **DOIT** être un partial zoné (`displayShowRefillLiveUpdate`, zone
  120 × 122 px, y 94 → 215) : le poids revient en vingtaines de kilos, un full par
  lecture (~1,3 s) serait inutilisable ;
- l'app **DOIT** sonder le capteur **toutes les 3 s** et ne rafraîchir que si le
  poids a bougé d'au moins **0,5 kg** (`kLiveEpsKg`) : le poids n'a aucun geste
  pour se rafraîchir (le court avance, le long est inerte), donc sans sondage un
  écran « en direct » ne bougerait pas ; à l'inverse un partial par lecture serait
  du gaspillage (un partial coûte ~856 ms) ;
- le héros reste sans « + » : `+185` ferait 110 px en `OswaldBold30` pour 110 px
  utiles — l'unité ne tiendrait plus à côté, alors que `185 KG` (109 px) garde le
  format de héros commun à tous les écrans. Le « + » se lit dans le contexte
  (`Total : … kg` juste en dessous) ;
- `Total` et `Niveau` **DOIVENT** être empilés sous le héros, comme le contexte des
  étapes 2 et 3.

**Règles** propres :
- étape 2 — le poids **théorique** (`nb × BAG_KG`) **DOIT** suivre sous le héros :
  c'est le repère que le poids réellement versé viendra confirmer ;
- étape 3 — le prix est saisi **par digits** comme sur l'ancien écran de prix :
  `● COURT` = +1 sur le digit courant, `— LONG` = digit suivant, et validation sur
  le dernier (le helper affiche alors `VALIDER`). Une **case entoure le digit en
  cours** ; les trois cases ne tiennent pas à la taille du héros (3 × 34 px +
  virgule + 2 px de cadre de chaque côté = 122 px, la largeur de la dalle), donc
  une seule case, comme sur l'ancien écran ;
- étape 3 — le coût total (`sacs × prix`) **DOIT** être affiché sous le héros, avec
  le signe `€`.

### 4.2 « TERMINER ? » — `REFILL_CONFIRM` ✅

Dernier écran **avant** l'enregistrement. Il met en regard ce qui va être sauvé :
le poids **réellement** ajouté, le nombre de sacs, le coût.

| Élément | Contenu |
|---|---|
| titre | `TERMINER ?` |
| bandeau | `VÉRIFIER` |
| étiquette | `Ajout réel` (`JbmXb4`, y 101 — l'encre 95..103 laisse 2 px sous la pointe du bandeau et 1 px au-dessus du héros) |
| héros | `185 KG` (comme les étapes, sans `+`) |
| contexte | `15 sacs × 15 kg` puis `Coût : 103,50 €` |
| zone secondaire | **barre de maintien** (10 cases, 1 case / 10 %, partial zoné) |
| pied | `● COURT CORRIGER` / `— LONG SAUVER` |

**Règles** :
- l'enregistrement **DOIT** exiger une **tenue** (`kHoldConfirmMs`, 2,5 s, la même
  durée que la confirmation du portail) : une déclaration ne doit pas se perdre sur
  un appui appuyé par erreur ;
- un appui court (relâché avant `kHoldTapMaxMs`, 0,4 s) **DOIT** ouvrir
  « CORRIGER ? » (`REFILL_FIX`) **sans rien publier** ; une tenue interrompue
  **NE DOIT RIEN** faire d'autre que vider la barre (l'écran reste) ; le timeout
  (10 min) **DOIT** abandonner. Règle commune à toutes les barres de maintien
  (`waitHoldGesture()`), portail compris : la barre ne se dessine qu'après 0,4 s,
  ce qui sépare le tap de la tenue sans ambiguïté ;
- la barre de maintien **DOIT** être la même que celle du portail (même dessin,
  même fenêtre 104 × 22) : `drawHoldProgress()` est le helper commun.

### 4.3 « CORRIGER ? » — `REFILL_FIX` ✅

Ouvert par un **appui court** sur `REFILL_CONFIRM`. Rien n'est publié.

| Élément | Contenu |
|---|---|
| titre | `CORRIGER ?` (`OswaldBold10`, y 45, comme `OPTIONS`) |
| lignes | `NOMBRE DE SACS` · `PRIX DU SAC` · `ANNULER` · `RETOUR` — géométrie du menu `OPTIONS` (`menuRowY`), `RETOUR` décalé de 8 px comme `FERMER` |
| sélection | barre noire pleine largeur, texte blanc ; curseur initial sur `NOMBRE DE SACS` |
| zone secondaire | `ANNULER : ENVOI` / `SAUVAGE, SANS PRIX` |
| pied | `● COURT SUIVANT` / `— LONG CHOISIR` |

**Règles** :
- `NOMBRE DE SACS` **DOIT** remettre le compte à **0** (le bouton ne sait que
  +1 : un compte trop haut ne se corrigerait pas autrement), garder le prix,
  publier `refill/state = pouring`, puis enchaîner mesure « après » → E14 ;
- `PRIX DU SAC` **DOIT** reprendre la saisie au 1ᵉʳ chiffre, puis mesure
  « après » → E14 ;
- `ANNULER` **DOIT** abandonner (`refillAbandon`) : le parcours ne publie rien,
  le cycle normal publie le versement en refill sauvage ;
- `RETOUR` **DOIT** réafficher E14 sans rien changer ;
- 10 min sans geste → abandon ;
- le geste qui a quitté E14 **NE DOIT PAS** déplacer ni choisir (file vidée).

### 4.4 « ENREGISTRÉ » — `REFILL_SAVED` ✅

| Élément | Contenu |
|---|---|
| titre | `ENREGISTRÉ` |
| bandeau | `REMPLISSAGE SAUVÉ` (en `JbmXb5` : 102 px ; en `JbmXb6` il ferait 119 px et déborderait du bandeau de 110 px) |
| étiquette | `Ajout réel` |
| héros | `185 KG` |
| zone secondaire | `15 sacs · 103,50 €` puis `0,56 €/kg · 462 kg` (`JbmXb4` : en `JbmXb5` les crochets sortiraient des marges) |
| pied | `● COURT PRINCIPAL` (une seule ligne) |

**Règles** :
- l'écran **DOIT** rester **1 minute** (`kSavedDwellMs`) puis rejoindre `MAIN`
  avec le poids **déjà mesuré** — **sans remesure ni publication** : le poids vient
  d'être mesuré et publié ;
- le retour anticipé **DOIT** être possible par `● COURT` ; l'appui long **PEUT**
  en être un alias (annoncé une seule fois pour ne pas surcharger le pied) ;
- le récap **NE DOIT PAS** comporter plus de deux lignes : la zone secondaire ne
  permet pas davantage, et 4 lignes ne tiendraient pas non plus sous le héros ;
- le prix au kilo affiché est `coût total / poids ajouté` (le coût par kilo
  **versé**, pas celui du stock).

### 4.5 Règles du parcours (dédock, timeouts, publication)

- Un dédock pendant le parcours **DOIT** mettre la FSM en attente
  (`refill_pending`), afficher le MODE NOMADE et reprendre au redock ; timeout
  d'attente **1 h**.
- Saisie, versement et validation : **10 min** d'inactivité (`kRefillSessionTimeoutMs`)
  → abandon : retour `DOCKED` et cycle de mesure normal (refill sauvage si une
  hausse ≥ ~1 sac est mesurée). Un prix saisi mais non confirmé **NE DOIT
  JAMAIS** être publié.
- Le coût affiché est `nb de sacs × prix du sac` ; le poids mesuré n'est qu'une
  vérification (un sac peut peser plus ou moins que `BAG_KG`).

---

## 5. Portail de configuration

### 5.1 Confirmation de démarrage — `PORTAL_CONFIRM`

**Règle** — une action lançant le point d'accès du portail **NE DOIT PAS** être
validée par un appui court : elle **DOIT** exiger un appui **maintenu**, et
l'écran **DOIT** le dire (`MAINTENIR`) et le **montrer** (barre de maintien).

| Geste / état | Effet |
|---|---|
| appui **court** | **quitte** — aucun lancement, l'appelant redessine son écran |
| **tenue 2,5 s** (`kHoldConfirmMs`) | la barre se remplit (10 cases, 1 case / 10 %, partial zoné) puis `webConfigRun()` — la page suivante est le portail |
| relâché avant la fin (après 0,4 s) | **rien** : la barre se vide, l'écran reste (on peut retenter) |
| 30 s sans appui (`kPortalConfirmTimeoutMs`) | abandon |

Rendu : titre `PORTAIL WIFI`, bandeau `RÉGLAGES LOCAUX`, question centrée sur
4 lignes, mot `MAINTENIR`, barre de maintien en zone secondaire, pied
`● COURT QUITTER` / `— LONG LANCER`. Le pied **NE DOIT PAS** porter
`MAINTENIR` (55 px en `JbmXb4` pour 116 px utiles) : l'instruction est portée
par le mot centré.

`kHoldConfirmMs` est **partagé** avec `REFILL_CONFIRM` (§4.2) : les deux écrans
sont des « je valide en tenant », la durée doit donc être la même des deux côtés.

### 5.2 Le portail — `webConfigRun()` (`CONFIG`)

- **Règle** — le portail **NE DOIT PAS** revenir à la normale sans
  **redémarrage** : « Enregistrer » (test WiFi réussi → `settingsSave`) et
  l'arrêt auto (10 min d'inactivité) **DOIVENT** tous deux finir par
  `ESP.restart()`.
- **Règle** — « Tester WiFi + MQTT » **NE DOIT PAS** redessiner l'e-paper : le
  verdict est renvoyé dans la page web, que l'utilisateur est en train de lire
  (le portail est figé ~15-20 s, l'écran ne changerait rien pour lui). L'ancien
  écran texte `TEST` (FreeMono, 10 car./ligne, sans en-tête ni pied) est
  **supprimé**.
- Si le test WiFi d'enregistrement échoue : rien n'est enregistré, le portail reste
  joignable et **l'e-paper ne doit pas être redessiné** (seule la page web est
  renvoyée).
- Le pied est **câblé** : `● COURT REDEMARRER` sur une carte configurée,
  `● COURT VEILLE` sans configuration (l'appui long est accepté, non annoncé).
- **Règle** — sans configuration enregistrée, la sortie (appui ou arrêt auto)
  **NE DOIT PAS** redémarrer (le portail se relancerait indéfiniment, AP
  allumé) : la carte **DOIT** afficher `UNCONFIGURED` puis dormir (§5.3).

### 5.3 Carte en veille sans configuration — `UNCONFIGURED`

| Élément | Contenu |
|---|---|
| titre | `CARTE` / `EN VEILLE` (`OswaldBold10`, y 38 / 60) |
| bandeau | `NON CONFIGURÉ` (`JbmXb6`, position sous titre) |
| corps | `AUCUN WI-FI` / `NI BROKER MQTT` / `ENREGISTRÉ` (`JbmXb5`, centré) |
| zone secondaire | `LE RÉVEIL OUVRE` / `LE PORTAIL WEB` |
| pied | `● COURT RÉVEIL` (une ligne) |

**Règles** : dessiné **une seule fois** (FULL) à l'entrée en veille ; un réveil
timer (contrôle batterie) **NE DOIT PAS** le redessiner (l'e-paper le garde) ;
tout appui réveille la carte et rouvre le portail.

---

## 6. Rafraîchissement (full / partial)

**Règles** :
- Le rafraîchissement **DOIT** être FULL par défaut ; le partial **DOIT** rester
  réservé au retour visuel d'un geste (une zone change, le reste est déjà juste).
- Un FULL forcé **DOIT** tous les 20 partials consécutifs (`kFullRefreshEveryN`,
  anti-ghosting) ; `canPartial()` **DOIT** être faux si l'écran affiché n'est pas
  celui attendu, si le cache est perdu, ou si la dalle n'a pas été réinitialisée
  depuis le réveil.
- Toute zone partial **DOIT** être effacée avant redessin (une barre qui se vide,
  une inversion de texte ou une case qui disparaît laisserait du noir fantôme),
  et ses **x / w DOIVENT** être des multiples de 8 (adressage du SSD1680).

| Écran | Rafraîchissement |
|---|---|
| `MAIN` | **FULL** systématique · partial zoné jauge (120 × 31, y 162) et zone d'en-tête (32 × 19, éclair + batterie) — banc 🔜 |
| `DEDOCK` (nomade) | FULL ; partial zoné de la **zone d'en-tête** (32 × 19, x 88 → 119 : éclair de charge + batterie 3 segments) si le même écran est affiché — c'est la seule zone qui bouge en veille |
| `OPTIONS` | FULL au 1ᵉʳ affichage ; partial zoné (120 px, les 2 lignes concernées) au déplacement de la barre — banc 🔜 |
| `REFILL_LIVE` / `REFILL_BAGS` / `REFILL_PRICE` | FULL au 1ᵉʳ affichage ; **partial zoné du corps de l'étape** (120 × 122, y 94 → 215 : héros, contexte, barre) — chaque variation |
| `REFILL_CONFIRM` | FULL ; partial zoné de la barre de maintien (104 × 22, zone secondaire) à chaque case franchie |
| `PORTAL_CONFIRM` | FULL ; partial zoné de la barre (même fenêtre, helper commun `drawHoldProgress`) |
| `REFILL_FIX` | FULL au 1ᵉʳ affichage ; partial zoné (120 px, les 2 lignes concernées) au déplacement de la barre — même mécanique qu'`OPTIONS` |
| `REFILL_SAVED` / `CONFIG` / `INFORMATIONS` | FULL |
| `UNCONFIGURED` | FULL, une seule fois par entrée en veille |

⚠️ Sur T5 **V2.4** (`USE_EPD_PWR_CUTOFF = 1`) l'alimentation écran est coupée au
sommeil : la RAM de trame ne survit pas → le **premier draw de chaque réveil est
FULL**. Les partials ne s'appliquent donc qu'**au sein d'une même session**
(gestes rapprochés), jamais entre deux réveils.

---

## 7. Effets de bord par transition

**Règle** — toute transition **DOIT** être idempotente côté RAM RTC et ne
**DOIT** publier sur MQTT que ce qui est juste : le palier de poids est la
référence unique pour Home Assistant. Sujets : `scale/value`, `scale/battery`,
`scale/error/on-off`, `scale/quality` (retain) ; `scale/refill/state` (retain),
`scale/refill/event` (sans retain).

| Transition | MQTT | RAM RTC |
|---|---|---|
| → `MAIN` (4/4, palier déplacé) | `value`, `battery`, `error=off`, `quality` (`n/4 ok`) | `last_weight_kg`, `last_battery_pct`, `skip_count=0` |
| → `MAIN` (4/4, palier gelé : hausse < 1 sac) | **rien** | `skip_count++` |
| → `MAIN` `-1` (1-3/4, 1ʳᵉ fois) | `error=on`, `quality` (`n/4 degraded`) | `announced_error = DEGRADED` ; l'écran lit `last_measure_kg` / `last_measure_at` (non modifiés) |
| → `MAIN` `-1` (dégradé stationnaire) | rien | rien (l'image reste) |
| → `DEDOCK` (transition) | `error=on`, `quality` (`0/4`, mode `dedock`) | `announced_error = DEDOCKED` |
| → `DEDOCK` (stationnaire) | rien | partial de la zone d'en-tête si `%` ou charge changé |
| → `REFILL_LIVE` | `refill/state = pouring` | mode `REFILL_POURING`, `refill_before_kg`, `refill_pending = NONE`, `refill_started_at`, `price_digits = {4,0,5}` (défaut **4,05 €**), `refill_bag_count = 0` |
| → `REFILL_BAGS` / `REFILL_LIVE` (refresh) | rien | `refill_bag_count` |
| → `REFILL_PRICE` | `refill/state = pricing` | mode `REFILL_PRICING` |
| → `REFILL_CONFIRM` | **rien** (aucun publish avant le maintien) | `refill_delta_kg` |
| maintien complété → `REFILL_SAVED` | `value`+`battery`+`error=off`+`quality`, puis `refill/state = saved` et `refill/event` (`added_kg`, `bag_price_eur`, `bag_count`) | `commitRefillPalier` : le palier passe **immédiatement** au poids « après » (sinon le cycle suivant re-détecte la hausse → 2ᵉ event → double comptage €) |
| appui court → `REFILL_FIX` | **rien** | chiffres et nombre de sacs conservés |
| maintien relâché avant la fin | **rien** (la barre se vide) | — |
| `REFILL_FIX` → `NOMBRE DE SACS` | `refill/state = pouring` | `refill_bag_count = 0`, mode `REFILL_POURING` |
| `REFILL_FIX` → `ANNULER` | rien par le parcours (abandon : refill sauvage par le cycle normal) | retour `DOCKED` |
| abandon du parcours (timeouts, delta < 0) | rien par le parcours ; le cycle normal enchaîné publie une hausse ≥ ~1 sac en refill sauvage (`bag_count = 0`) | retour `DOCKED` |
| dédock pendant le parcours | **rien** : le chemin appelle `displayShowNomade` directement, sans publish offline | `refill_pending` + mode `DEDOCKED` |
| reprise au redock | rien | `refill_pending = NONE` |
| → `MAIN` en fin de parcours | rien (poids déjà publié, pas de remesure) | mode `DOCKED` |

**Règle** — `refill/state` décrit la **phase du parcours** (`pouring`, `pricing`,
`saved`), **pas** la position physique du boîtier : pendant tout le parcours le
silo est hors de sa base. L'état physique reste porté par `quality.mode`
(`docked` / `dedocked` / `pouring` / `pricing`), et c'est au cycle suivant qu'il
reprend sa valeur réelle. Un `refill/state = docked` **DOIT** être proscrit :
c'était un vestige de l'ancien parcours et cela annonçait un dépôt qui n'a pas eu
lieu.

**Règle** — la session réseau **DOIT** être ouverte **avant** le rendu des écrans
qui portent l'heure (`publishBegin`), et le MQTT **DOIT** être envoyé **après**
le dessin : l'écran ne doit pas attendre la publication. L'inverse vaut pour
`refill/state` : il **DOIT** être publié **avant** le rendu de l'étape concernée
(le bloc est bloquant : WiFi + MQTT, plusieurs secondes si le broker est
injoignable).

---

## 8. Transitions sans redessin (« impasses »)

Cas où le firmware **dort sans changer l'image** — utile pour savoir ce qui reste
affiché après un réveil.

| Cas | Écran qui reste | Effet |
|---|---|---|
| `vbat < 3,3 V` au réveil | image précédente | cycle sauté (ni Wi-Fi, ni publish) → prochain créneau |
| `vbat < 3,2 V` (urgence) | image précédente | 24 h ; 3ᵉ réveil → 1 semaine — un poll léger sous le seuil d'urgence bascule sur le cycle complet |
| veille nomade, segments ou USB changés (poll léger) | `DEDOCK` | partial de la zone d'en-tête (éclair + batterie) — RAM de trame reconstruite au réveil |
| `announced_error == DEGRADED` | `MAIN` `-1` | aucun redessin, **pas même la batterie** |
| `announced_error == DEDOCKED` | `DEDOCK` | partial de la zone d'en-tête (éclair + batterie) seulement si `%` ou charge a changé |
| réveil en mode remplissage (reset en plein parcours) | `REFILL_LIVE` / `REFILL_BAGS` / `REFILL_PRICE` | abandon : cycle normal → `MAIN` |
| refill refusé (batterie trop basse) | `MAIN` | rien de dessiné |
| timeout versement / comptage (10 min) | `REFILL_LIVE` / `REFILL_BAGS` | abandon : cycle normal → `MAIN` |
| timeout saisie du prix (10 min) | `REFILL_PRICE` | abandon : cycle normal → `MAIN` |
| delta < 0 à la validation | `REFILL_CONFIRM` | abandon : cycle normal → `MAIN` |
| appui court sur `REFILL_CONFIRM` | `REFILL_CONFIRM` | « CORRIGER ? », aucun refill publié |
| maintien relâché avant la fin (`REFILL_CONFIRM`, `PORTAL_CONFIRM`) | même écran | la barre se vide, rien d'autre |
| `ANNULER` ou timeout (10 min) sur `REFILL_FIX` | `REFILL_FIX` | abandon : cycle normal → `MAIN` |
| timeout sur `REFILL_CONFIRM` (10 min) | `REFILL_CONFIRM` | abandon : cycle normal → `MAIN` |
| dedock + `refill_pending` > 1 h | `DEDOCK` | flag effacé, abandon propre |
| `PORTAL_CONFIRM` : appui court / timeout | `PORTAL_CONFIRM` | abandon, l'appelant redessine |
| timeout d'inactivité du menu | `OPTIONS` | équivalent de `FERMER` : `MAIN` (dernier poids connu) puis sommeil |
| réveil timer d'une carte non configurée | `UNCONFIGURED` | contrôle batterie, aucun redessin, 24 h |

---

## 9. Gestes annoncés (pied) vs gestes câblés

**Règle** — le pied **DOIT** annoncer exactement les gestes que l'écran accepte,
et **NE DOIT** jamais annoncer un geste inerte. Un écart est un défaut, pas un
choix d'ergonomie.

**Règle** — le pied **NE DOIT PAS** porter de deux-points de séparation : le nom
du bouton reste à gauche (`● COURT` / `— LONG`, ancré sur `kMarginL`), la valeur —
l'action — est alignée à droite sur `kMarginR` (116). C'est cet alignement qui
fait la colonne, pas un séparateur.

**Règle** — un écran dont l'unique geste est un appui long **DOIT** réduire son
pied à la ligne unique du bas (`drawFooterLongOnly`), et un écran dont l'unique
geste est un appui court **DOIT** utiliser `drawFooterOne()`.

| Écran | Pied dessiné | ● Court | — Long |
|---|---|---|---|
| `MAIN` | `● COURT MESURER` / `— LONG OPTIONS` | ✅ cycle complet (+ publish si Δ) | ✅ ouvre `OPTIONS` |
| `DEDOCK` (nomade) | `— LONG OPTIONS` | ❌ inerte (non annoncé, se rendort) | ✅ ouvre `OPTIONS` |
| `OPTIONS` | `● COURT SUIVANT` / `— LONG CHOISIR` | ✅ ligne suivante (partial) | ✅ l'entrée est validée |
| `INFORMATIONS` p1 / p2 | `● COURT AUTRE PAGE` / `— LONG RETOUR` | ✅ bascule p1 ↔ p2 | ✅ retour au menu |
| `PORTAL_CONFIRM` | `● COURT QUITTER` / `— LONG LANCER` | ✅ abandon | ✅ **tenue 2,5 s** → portail |
| `CONFIG` (portail actif) | `● COURT REDEMARRER` (configurée) / `● COURT VEILLE` (sans configuration) | ✅ redémarrage / veille | — (accepté comme le court, non annoncé) |
| `UNCONFIGURED` (carte en veille, sans config) | `● COURT RÉVEIL` (1 ligne) | ✅ réveil → portail | ✅ idem (non annoncé) |
| `REFILL_LIVE` | `● COURT SUIVANT` (1 ligne) | ✅ étape 2/3 | — (inerte) |
| `REFILL_BAGS` | `● COURT + 1 SAC` / `— LONG VALIDER` | ✅ +1 sac (partial) | ✅ étape 3/3 |
| `REFILL_PRICE` | `● COURT PLUS` / `— LONG SUIVANT` (`VALIDER` sur le dernier) | ✅ +1 sur le digit (partial) | ✅ digit suivant / validation |
| `REFILL_CONFIRM` | `● COURT CORRIGER` / `— LONG SAUVER` | ✅ ouvre `REFILL_FIX` | ✅ **tenue 2,5 s** → enregistrement |
| `REFILL_FIX` | `● COURT SUIVANT` / `— LONG CHOISIR` | ✅ ligne suivante (partial) | ✅ sacs / prix / annuler / retour |
| `REFILL_SAVED` | `● COURT PRINCIPAL` (1 ligne) | ✅ écran principal (alias : le long aussi) | — (alias) |

---

## 10. Récapitulatif écran → déclencheur

| Vers l'écran | Depuis / déclencheur |
|---|---|
| `CONFIG` | démarrage sans réseau **ou** broker enregistré ; `PORTAL_CONFIRM` tenu 2,5 s ; appui bouton sur `UNCONFIGURED` |
| `UNCONFIGURED` | sortie du portail (appui ou arrêt auto) sans configuration enregistrée |
| `TEST` | `CONFIG` : « Tester WiFi + MQTT » |
| `MAIN` | cycle planifié (mesure OK, ou 1-3/4 → variante `CAPTEUR(S) HS`) ; fin de `REFILL_SAVED` ; `FERMER` du menu ; retour du re-test du dock |
| `DEDOCK` (nomade) | cycle/réveil : 0/4 **avec** signal de dédock ; dédock pendant le parcours |
| `OPTIONS` | appui long au réveil depuis `DOCKED`/`DEGRADED` |
| `REFILL_LIVE` | `OPTIONS` → `REMPLISSAGE` ; reprise après dédock (`BEFORE_MEASURE`) ; réveil en mode `REFILL_POURING` |
| `REFILL_BAGS` | `● COURT` sur l'étape 1 ; `NOMBRE DE SACS` sur `REFILL_FIX` |
| `REFILL_PRICE` | `— LONG` sur l'étape 2 ; `PRIX DU SAC` sur `REFILL_FIX` ; réveil en mode `REFILL_PRICING` |
| `REFILL_FIX` | appui court sur `REFILL_CONFIRM` |
| `REFILL_CONFIRM` | `— LONG` (validation) sur l'étape 3 ; reprise après dédock (`AFTER_MEASURE`) ; correction terminée ou `RETOUR` sur `REFILL_FIX` |
| `REFILL_SAVED` | maintien de 2,5 s sur `REFILL_CONFIRM` |
| `INFORMATIONS` | entrée `INFORMATIONS` du menu |
| `PORTAL_CONFIRM` | entrée `PORTAIL RÉGLAGES` du menu |

---

## 11. Menu `OPTIONS`

`displayShowOptions()` est câblé (`appOptionsMenu`) et **atteignable** : c'est la
seule voie vers le portail sur un appareil configuré (le cold boot + bouton
n'ouvre plus le portail, cf. §1).

### 11.1 Arbitrage d'entrée — tranché : (a)

Le pied de `MAIN` annonce `— LONG OPTIONS` ; l'appui long ouvre donc le menu, et
le remplissage ne se lance plus que par l'entrée `REMPLISSAGE`. Conséquence
assumée : le remplissage demande **deux gestes** au lieu d'un (menu → entrée 0),
ce qui est le prix de l'explicitation — un appui long unique ne doit plus
enchaîner une saisie de prix puis un enregistrement.

### 11.2 Entrées du menu

**Règle** — le menu fait **TOUJOURS 4 lignes** (base 96, pas 24, `FERMER` à +8),
quelle que soit la situation : l'espacement ne doit pas changer d'un écran à
l'autre, sinon « l'entrée manquante » se lit comme un oubli.

**Règle** — une entrée **impossible dans le mode courant** est **INACTIVE, pas
absente** : elle reste à sa place, sur un **contour 1 px tramé à 25 %** (le
tramage EST le gris sur une dalle 1 bit) au lieu de la barre pleine — le libellé
reste sur fond blanc, donc lisible. Et le **curseur la saute** : « choisir »
agit donc toujours, et l'utilisateur voit de quoi il a sauté. Un simple tramé
sans contour rendait les majuscules illisibles (vérifié au rendu hors matériel) ;
un contour sans tramage se confondait avec une simple sélection.

**Règle** — à l'ouverture, le curseur **DOIT** se poser sur la première ligne
**jouable** (`menuFirstEnabledRow()`) : hors base ce n'est pas `REMPLISSAGE`.
Sinon le menu s'ouvre sur une ligne qui n'est pas sélectionnable — donc sans
barre de sélection, et à deux appuis de la première entrée possible.

| Entrée | Posé sur la base | Hors base |
|---|---|---|
| `REMPLISSAGE` | ✅ sélectionnable → `REFILL_LIVE` | 🚫 **inactive** (tramée, curseur par-dessus) — le silo n'est pas sur sa balance et l'étape 1 commence par une mesure |
| `PORTAIL RÉGLAGES` | ✅ `PORTAL_CONFIRM` → `CONFIG` | ✅ idem |
| `INFORMATIONS` | ✅ les 2 pages | ✅ idem |
| `FERMER` | ✅ écran principal (dernier poids connu) | ✅ écran nomade |

`FERMER` **DOIT** rendre à l'écran du **mode courant**, pas toujours à l'écran
principal : hors base, afficher une jauge de silo et « CONNECTÉ » serait un
mensonge.

| Entrée | Cible | Détail |
|---|---|---|
| `REMPLISSAGE` | `REFILL_LIVE` | `refillStart()` : garde batterie, puis tout le parcours |
| `PORTAIL RÉGLAGES` | `PORTAL_CONFIRM` → `CONFIG` | `appPortalConfirm()` ; si l'utilisateur renonce, le menu est redessiné |
| `INFORMATIONS` | `INFORMATIONS` p1 → p2 | `appShowInformations()` : valeurs réelles (session réseau ouverte, 4 pieds lus), `● COURT AUTRE PAGE` = bascule p1 ↔ p2, `— LONG RETOUR` = menu |
| `FERMER` | écran du mode → deep sleep | **sans remesure** : `MAIN` avec le dernier poids connu si le boîtier est posé, sinon l'écran nomade (aucune mesure n'est possible hors base) |

`FERMER` est **séparé** des trois autres par 8 px (`kMenuLastDY`) : ce n'est pas
une 4ᵉ fonctionnalité, c'est la sortie du menu — et le menu **doit** avoir une
issue explicite, sinon on n'en sort qu'en choisissant une action.

**Règle** — `FERMER` et le timeout d'inactivité (1 min, non annoncé au pied :
le pied annonce les gestes, pas l'absence d'attention) **DOIVENT** produire le
même effet : `MAIN` avec le dernier poids connu, puis deep sleep.

### 11.3 Gestes

- `OPTIONS` : `● COURT` = ligne suivante (la barre bouge → partial zoné, une ligne
  par clic), `— LONG` = valider l'entrée sélectionnée.
- `INFORMATIONS` : `● COURT AUTRE PAGE` = bascule p1 ↔ p2 ; `— LONG RETOUR` = retour au menu
  (aucune confirmation à maintenir depuis les informations).

### 11.4 Points techniques

- L'index de sélection du menu **n'a pas besoin de survivre au sommeil** (on n'y
  dort pas) : une variable locale suffit.
- Le menu réutilise `enterInteractiveSession()` (capture des appuis + absorption
  de l'appui de réveil) : même mécanique que le parcours de remplissage.
- `MenuItem` est un contrat partagé (`display.hpp`) : l'écran définit les libellés
  et la géométrie, l'app dispatche le choix.
- `drawMenuRow()` passe par `menuRowY(i)` pour que la ligne `FERMER` soit
  décalée ; le partial de déplacement de la sélection l'utilise aussi (fenêtre
  entre les deux lignes concernées).

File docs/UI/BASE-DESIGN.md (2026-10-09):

# Base de design — écrans e-paper (TTGO T5, 122×250)

Référence commune à **tous** les écrans embarqués. Un nouvel écran doit réutiliser
cette grille, ces polices et ces composants — sans réinventer de coordonnées.

## Dalle & contraintes

- Écran **122 × 250 px, portrait**, **1 bit** (blanc pur / noir pur).
- Full refresh ~2,6 s (avec flash), partial zoné ~856 ms (sans flash).
- Après chaque deep sleep, le premier draw est **FULL** (la RAM de trame ne
  survit pas à la coupure d'alimentation écran).
- Marges : **gauche x = 7**, **droite x = 116** ; centrage horizontal **x = 61**.
- Inversé (fond noir + texte blanc) réservé aux **bandeaux d'alerte**.
- Aucun wrap : un libellé trop large est **raccourci** (mesurer avec `textWidthUtf8`).

### Polices

Bitmap dédiées, générées des TTF *JetBrains Mono ExtraBold* et *Oswald Bold* :
plage `0x20–0xFF` → **accents rendus**, et le **signe `€`** (U+20AC) ajouté dans
le slot `0x100` (juste au-dessus de Latin-1) — le décodeur UTF-8 de
`display.cpp` replie `U+20AC` sur ce slot, ce qui évite 8237 entrées de glyphe
(49 ko) pour un seul caractère. En revanche le **tiret cadratin** `—` (U+2014)
n'existe pas : l'écrire en ASCII `—`.

| Police | Hauteur | Usage |
|---|---|---|
| `JbmXb4` | ~7 px | état, libellés de jauge, zone secondaire, pied |
| `JbmXb5` | ~8 px | date de l'en-tête |
| `JbmXb6` | ~9 px | bandeau d'alerte, titre d'écran |
| `OswaldBold10` | ~16 px | unité (KG) |
| `OswaldBold30` | ~49 px | valeur principale (poids) |

## Grille (référence)

| Zone | y (px) | Contenu |
|---|---|---|
| **A — en-tête** | 0 → 20 | séparateur noir à **y = 20**. À gauche (x = 7) : **date** `jj/mm/aa` (`JbmXb5`). À droite : **éclair de charge** (x = 78, 10 × 12) si l'USB est présent, puis **batterie 3 segments** (x = 92, w = 22, h = 10 + ergot). Tout ce bloc (72 → 119) est la **zone de partial** de l'en-tête. |
| **B — contenu** | 20 → 194 | — |
| ↳ **état** | baseline **29** | pastille `●` (r = 2) + libellé, **centré** (`JbmXb4`) |
| ↳ **bandeau d'alerte** (option) | **36 → 56** (h = 20) + **pointe 56 → 63** | **inversé**, texte centré baseline **50** (`JbmXb6`), **pointe vers le bas** centrée (24 px de large, 8 px de profond) |
| ↳ **bandeau de titre** (option) | **66 → 84** (h = 18) + **pointe 84 → 92** | même motif, sous le **titre** (écrans nomade / portail / remplissage) ; texte centré baseline **79**. L'interligne 46 → 66 px peut porter une **légende de héros** (`Ajout réel`, `JbmXb4`, baseline **101**) — voir règle 7 |
| ↳ **zone messages (libre)** | ~57 → 103 | réservée aux messages, au-dessus du poids — hosting des deux bandeaux ci-dessus (avec leur pointe) |
| ↳ **valeur principale** | baseline **152** | poids `OswaldBold30` + unité `OswaldBold10`, **centré** — **position constante sur tous les écrans** |
| ↳ **jauge** | libellés baseline **170** ; barre **176 → 191** (h = 15) | libellé à gauche (`CAPACITÉ`), valeur à droite (`65 %`) ; barre : contour 1 px, remplissage intérieur |
| **C — secondaire (réservée)** | **194 → 216** (h = 22) | **crochets hauts `[ ]`** (barre verticale + ergots 4 px) + message **sur UNE ligne**, centré baseline **208** (`JbmXb4`) |
| **D — pied** | séparateur **y = 221** | l.1 baseline **233** : `● COURT` (gauche) / `MESURER` (droite). l.2 baseline **244** : `— LONG` / `OPTIONS`. **Aucun deux-points** : c'est l'alignement qui fait la colonne. |

## Composants

- `drawHeader(batt, charging)` — **en-tête commun** : date (`JbmXb5`) à gauche,
  éclair de charge + batterie 3 segments à droite, séparateur. Utilisé tel quel
  par tous les écrans — c'est donc **lui** qui porte l'état « sur USB », seul
  signe qui distingue une recharge d'une batterie qui descend. L'éclair est un
  polygone vectoriel 10 × 12 (`drawChargingBolt`) : à cette taille un bitmap
  serait illisible, et il est dans la zone de partial donc gratuit à
  rafraîchir.
- `drawHeaderBatteryZone(batt, charging)` — la **seule zone d'en-tête qui bouge**
  (48 × 19, x 72 → 119 ; le séparateur à y = 20 et la date restent hors fenêtre). Partagée par
  le rendu complet et par les deux partials d'en-tête (écran principal et écran
  nomade) : `x`/`w` multiples de 8, et **tout ce que l'en-tête dessine à droite
  du x = 88 doit y tenir**.
- `drawFooter(action_court, action_long)` — **pied commun** : `● COURT` à gauche,
  l'action alignée **à droite** sur `kMarginR`, puis `— LONG` et son action sur la
  même colonne. **Pas de deux-points** : le nom du bouton à gauche, la valeur à
  droite, et rien entre les deux.
- `drawFooterOne(action)` — pied **réduit à la ligne 1** (`● COURT`) : écran dont
  l'unique geste est un appui court.
- `drawFooterLongOnly(action)` — pied **réduit à la ligne 2** (`— LONG`) : écran
  dont l'unique geste est une **tenue** (ECRAN14). La ligne 2 est celle de la
  tenue, donc le tiret de gauche le dit ; un `● COURT` y serait un geste
  inexistant, donc un mensonge.
- Budget de l'action du pied : **77 px** (116 - 39, la pastille + `COURT` /
  `LONG` occupant 6 → 39). `INFORMATIONS` (66 px) est la plus longue action en
  usage.
- `drawUtf8 / drawUtf8Centered / drawUtf8Right / drawUtf8CenteredInv` — texte
  UTF-8 (accents). `textWidthUtf8(font, texte)` donne la largeur (contrôle
  anti-débordement **avant** validation).
- `drawBattery3Seg(x, y, w, h, pct)` — contour + ergot + 1 à 3 segments pleins.
- `drawDot(cx, cy, r)` — pastille `●` (appui court) ; `drawDash(x, y, w)` — tiret
  `—` (appui long).
- `drawSecondaryBox(msg)` — crochets hauts + message une ligne.
  `drawSecondaryFrame()` — le cadre **pleine largeur** seul (crochets hauts), à
  composer quand la zone accueille autre chose qu'un message (barre d'avancement).
- `drawDisabledRow(row)` — **entrée inactive** : même place et même hauteur de
  barre, mais **contour 1 px + tramé 25 %** (2 px pleins dans une cellule de 4 px)
  au lieu du noir plein — sur 1 bit, le tramage EST le gris. Le libellé reste sur
  fond blanc (donc lisible) et le **curseur saute la ligne**, pour que « choisir »
  n'agisse jamais pour rien. Réservé à une entrée impossible dans le mode
  courant (`REMPLISSAGE` hors base) : jamais pour une entrée absente.
- `drawProgressBar(step, steps)` — barre d'avancement dans la **zone
  secondaire** : 10 cases (5 px de large, pas de 7 px) à gauche, compteur
  `n/3` aligné à droite, le tout dans le cadre pleine largeur. Cases pleines
  selon `(step × 10) / 3`. ** identique sur les 3 étapes du remplissage : elle est
  le seul indicateur d'étape. L'avancement se lit sans lire un chiffre.
- `drawInvertedBanner(top, h, font, texte, text_y)` — **bandeau inversé commun** :
  barre noire pleine largeur (`kMarginL`→`kMarginR`) + texte blanc centré, **prolongée
  par une pointe pleine vers le bas** (base 24 px centrée sur `kCenterX`, 8 px de
  profond) qui désigne le contenu situé en dessous. Utilisé pour les **deux**
  positions de bandeau (alerte sous l'état, titre sous le titre) : ne pas
  redessiner un bandeau à la main.
- `drawHoldBar(remplies)` — **barre de maintien** : 10 cases entre crochets dans
  la zone secondaire (7 px de large, 8 px de pas, 12 px de haut, y = 200), les
  cases pleines en noir et les vides en contour 1 px (sinon elles disparaissent
  sur la dalle). Réservée aux **actions exigeant un appui long maintenu** :
  ne jamais valider une action sensible sur un appui court.
- `drawHoldProgress(écran, pct)` — **remplissage de la barre en partial zoné**
  (fenêtre 104 × 22 sur la zone secondaire), une case toutes les 10 %. Helper
  **commun** aux deux écrans à tenue — le portail (`displayShowPortalHoldProgress`)
  et ECRAN14 (`displayShowRefillConfirmHoldProgress`) — : même dessin, même
  fenêtre, seul l'écran de repli change. C'est ce retour visuel qui rend la tenue
  lisible.
- Barres d'avancement **vs** barres de maintien : la première **compte** des
  étapes (10 cases de 5 px, compteur `n/3` à droite), la seconde **chronomètre**
  une tenue (10 cases de 7 px, sans compteur). Ne pas les confondre.

## Règles

1. **Zone secondaire réservée** sur **tous** les écrans, **même vide**.
2. **Position du poids constante** (`kHeroY`) sur tous les écrans.
3. **Pied toujours en bas** (`● court` / `— long`) — un seul bouton physique. Le
   pied n'annonce **que** les gestes que l'écran accepte, et l'action est alignée
   à droite sans séparateur.
4. Bandeau d'alerte **uniquement** pour un état particulier (ex. `NIVEAU BAS`),
   toujours avec sa **pointe vers le bas** (jamais un rectangle nu).
5. Zones réservées en haut (messages) **au-dessus** du poids, jauge **sous** le poids.
   Exception : la **légende d'une valeur non live** (ex. `DERNIER POIDS CONNU` sur
   le mode nomade) est une contre-note du nombre → elle se place **sous** le poids
   (`kNomadeLabelY = 172`), pas dans la zone de messages.
6. ASCII/Latin-1 seulement ; pas de retour à la ligne.
9. **Une entrée impossible ne disparaît pas** : elle se garde sa place et son
   espacement, avec le traitement « inactive » (contour + tramé), et le curseur
   la saute. Un menu qui se recompose selon l'écran se lit comme un bug.
10. **Aucun écran dans l'ancien style** : ni polices Adafruit `FreeMono*`, ni silo
   ÖkoFEN vectoriel. Un écran qui n'a pas son rendu dans la charte n'est pas
   « presque fini », il est à faire.
7. **Légende de héros** — quand un héros pourrait être confondu avec une autre
   grandeur (ECRAN14/15 : `185 KG` est le poids *versé*, pas le poids du silo), la
   légende se place entre la pointe du bandeau (92) et l'encre du héros (105) :
   baseline **101** en `JbmXb4` (en `JbmXb5`, le jambage du « j » toucherait le
   héros). Le héros, lui, reste **sans `+`** : `+185` ferait 110 px pour 110 px
   utiles et l'unité ne tiendrait plus à côté.
8. **Pas de sous-titre d'étape** dans un parcours séquentiel : l'indicateur
   d'avancement (barre + `n/3`) en zone secondaire suffit, et il se compare d'un
   écran à l'autre. Exception : une **légende de héros** (règle 7), qui n'est pas
   un indicateur d'étape mais une contre-note de la valeur.

## Écrans de référence

- **E01** — mesure connectée : `docs/UI/ECRAN01/` (`[ MESURE STABLE ]`).
- **E02** — niveau bas : `docs/UI/ECRAN02/` (bandeau `NIVEAU BAS` +
  `[ REMPLISSAGE CONSEILLE ]`).
- **E07** — confirmation de portail : `docs/UI/ECRAN07/` (barre de maintien).
- **E11** — remplissage en cours : `docs/UI/ECRAN11/` (suivi en direct).
- **E12** — nombre de sacs : `docs/UI/ECRAN12/` (théorie + barre d'avancement).
- **E13** — prix par sac : `docs/UI/ECRAN13/` (saisie par digits avec case sur le
  digit courant, coût total en `€`, barre pleine).
- **E14** — « TERMINER ? » : `docs/UI/ECRAN14/` (légende `Ajout réel`, héros, deux
  lignes de contexte, barre de maintien, pied `● COURT CORRIGER` /
  `— LONG SAUVER`). L'écran « CORRIGER ? » qui suit l'appui court n'a pas de
  maquette : il reprend la géométrie du menu `OPTIONS` (rendu pixel :
  `docs/screens/refill_fix_0.png`).
- **E15** — « ENREGISTRÉ » : `docs/UI/ECRAN15/` (récap sur 2 lignes en zone
  secondaire, pied `● COURT PRINCIPAL`).
- **E18/E19** — informations : `docs/UI/ECRAN18/` et `docs/UI/ECRAN19/`.
- **E22** — menu `OPTIONS` **hors base** : 4 lignes comme sur la base, mais
  `REMPLISSAGE` est **inactive** (contour + tramé) et le curseur la saute ;
  `docs/UI/ECRAN22/`.
- **E21** — variante « en charge » de l'écran principal : l'en-tête porte
  l'**éclair** (x = 78, 10 × 12) à gauche du bloc batterie. C'est la seule
  différence avec E01 ; `docs/UI/ECRAN21/` (le rendu pixel est
  `tools/preview/main_charge.png`).
- Les **3 étapes du remplissage** (E11/E12/E13) partagent le même squelette :
  titre, bandeau + pointe, héros, contexte, barre d'avancement en zone
  secondaire (avec le compteur `n/3`), pied — **ni sous-titre d'étape, ni
  étiquette au-dessus du héros**. Toute évolution passe par le corps commun
  (`drawRefillStepBody` = `drawRefillHero` + `drawProgressBar`).

## Implémentation

- `src/display.cpp` : helpers + constantes de grille (`kMarginL/R`, `kCenterX`,
  `kHdrLineY`, `kStatusY`, `kTitleBannerTop/H/TextY`, `kBannerPtrHalfW/H`,
  `kHeroY`, `kGaugeLblY`, `kGaugeTop/H`, `kSecTop/Bot`, `kSecY`, `kFootLineY`,
  `kFootY1/2`, `kRefillCtx1Y/2Y`, `kRefillLabelY`, `kHoldCellW/DX`, `kHoldBarY/H`,
  `kMenuRowY0/DY/LastDY`).
- `include/display.hpp` : contrats partagés par l'app (`MenuItem`,
  `kHoldBarCells`) + documentation de chaque écran.
- `include/fonts/` : polices bitmap ; `include/config.hpp` : inclusions.

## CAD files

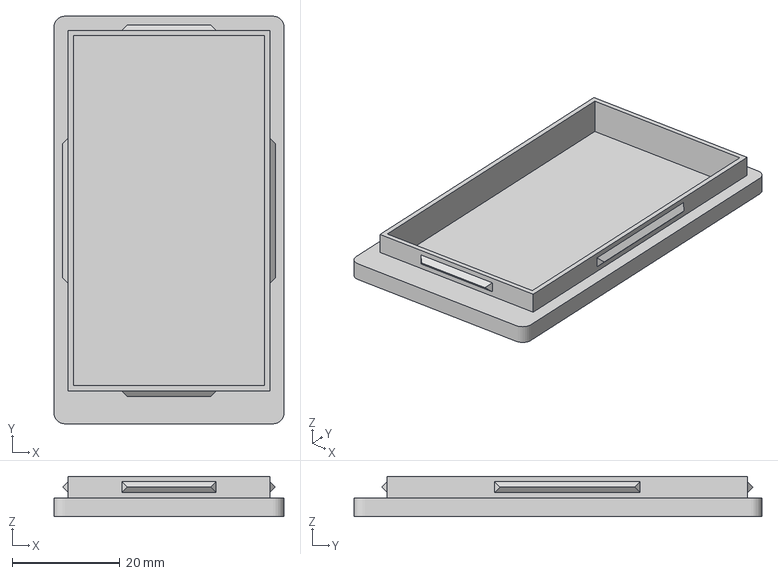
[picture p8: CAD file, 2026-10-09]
case/v1/BackMain.3mf
42.8 x 75.8 x 7.50 mm

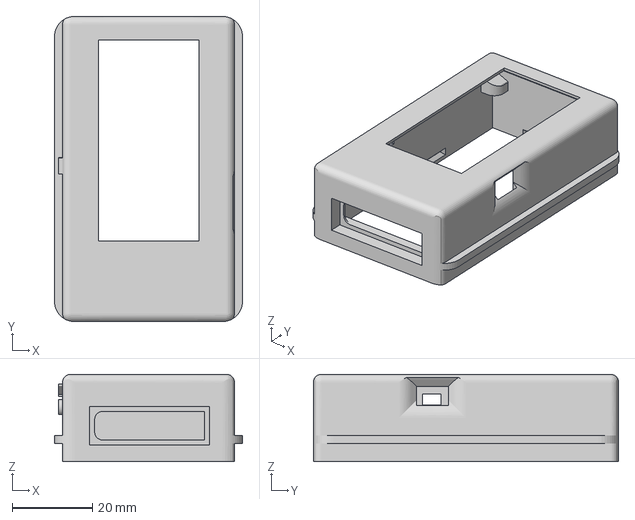
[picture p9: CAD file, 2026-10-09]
case/v1/Main.3mf
46.8 x 75.9 x 21.7 mm

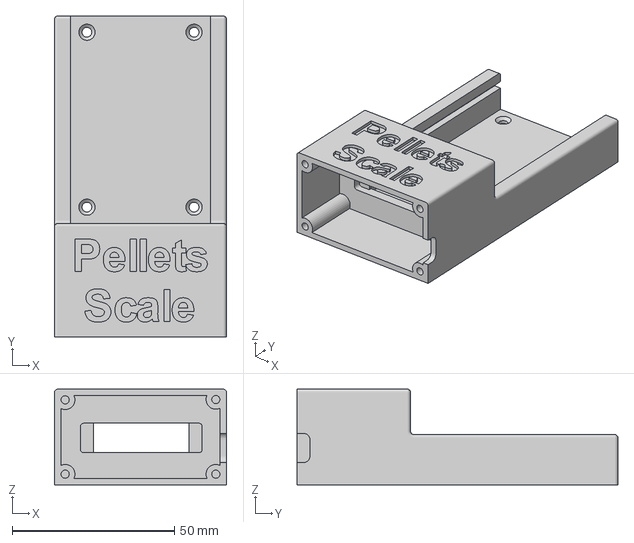
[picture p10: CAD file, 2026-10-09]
case/v1/Support.3mf
53.0 x 98.9 x 29.5 mm

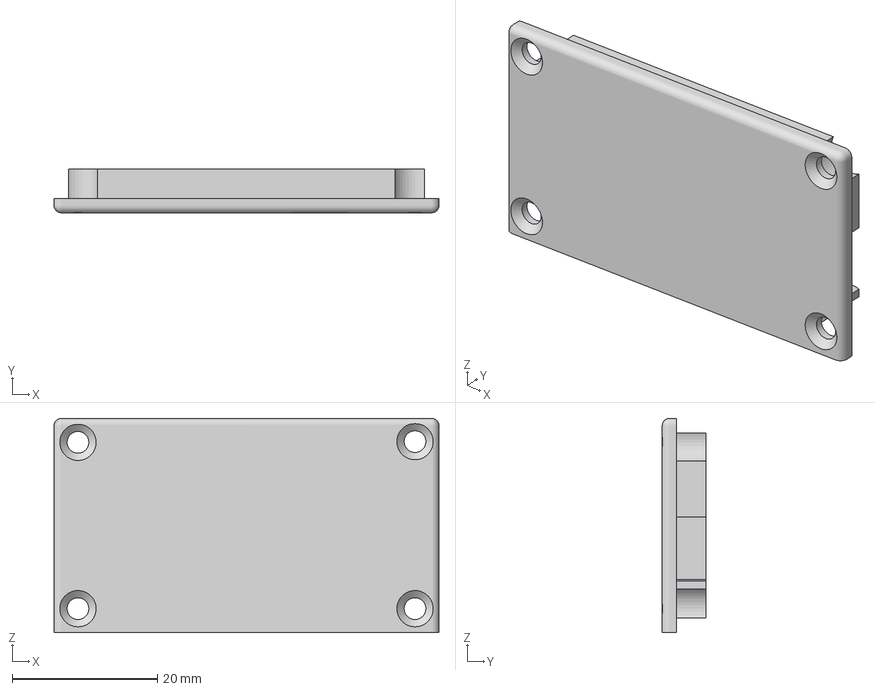
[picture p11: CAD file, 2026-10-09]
case/v1/BackSupport.3mf
53.0 x 6.00 x 29.5 mm

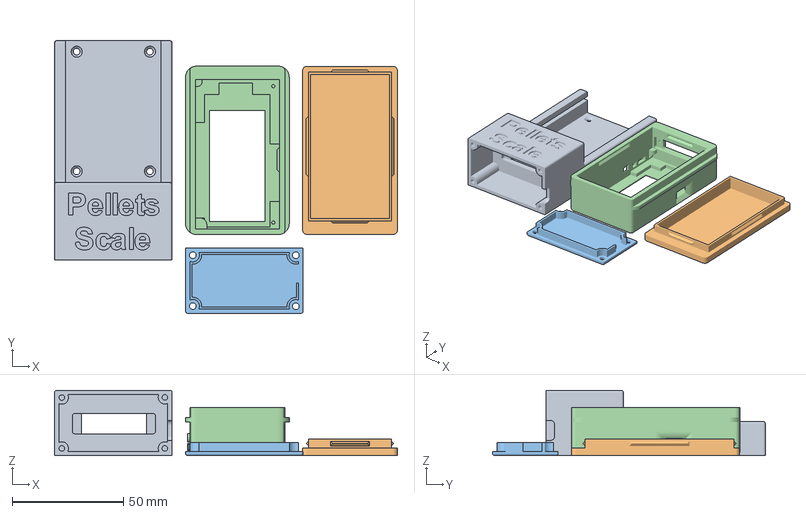
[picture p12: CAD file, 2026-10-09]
case/v1/PelletScale.3mf
154.5 x 122.9 x 29.5 mm
Support
BackMain
BackSupport
Main

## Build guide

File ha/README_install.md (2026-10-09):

# ESP Scale — Home Assistant : installation

Fichiers de configuration HA pour le suivi conso/coût du silo.
Chaque fichier a **une seule clé racine** → compatible avec le mode `packages`.

## Architecture : le poids publié EST le stock

La balance (firmware) est la **jauge de vérité**. Elle publie `scale/value`
avec un **cliquet « gel au mini »** : le palier publié ne remonte qu'à un refill.

- Toute **baisse ≥ 1 kg** → publiée (= consommation).
- Toute **hausse < 14 kg** (~1 sac) → **non publiée** (présumée bruit/dérive) :
  le palier reste **gelé à son minimum** — HA n'est donc jamais artificiellement
  gonflé, et une dérive réversible ne s'accumule pas en fausse conso. Le
  heartbeat, la batterie et le retry republient le palier **inchangé**.
- Toute **hausse ≥ 14 kg** hors FSM → « refill sauvage » : poids publié +
  event `scale/refill/event` avec `bag_count: 0`.

Côté HA, **aucun stock comptable** : le stock affiché = `sensor.scale_poids`.
Seule la **valeur €** est comptable (le prix ne se mesure pas).

## Déploiement (recommandé : packages)

1. Copier les fichiers de ce dossier (`ha/`) dans `<config>/packages/` de
   Home Assistant (renomme-les avec un préfixe `scale_` si tu veux les
   distinguer d'autres packages) :
   ```
   packages/
     sensors.yaml
     helpers.yaml
     templates.yaml
     utility_meter.yaml
     automations.yaml
     refill_journal.yaml
     statistics.yaml
     suivi.yaml
   ```
   ⚠️ **`sensors.yaml` n'est PAS un package** : l'intégration MQTT ne se
   configure pas via packages. Son contenu est à **fusionner dans le bloc
   `mqtt:` de `configuration.yaml`** (voir le fichier pour le copier-coller).
   `dashboard.yaml` non plus — c'est une vue à coller dans l'éditeur de
   dashboard (mode YAML), pas une config de packages.

2. Dans `configuration.yaml`, activer les packages :
   ```yaml
   homeassistant:
     packages: !include_dir_named packages
   ```
3. Redémarrer HA et vérifier (Paramètres → Système → Journaux, ou
   Paramètres → Appareils → vérifier les entités "Scale").

### Déploiement automatisé

`sync.sh` pousse les packages vers l'installation distante (SSH + Docker),
avec backup auto, check config et restart :
```bash
./ha/sync.sh            # backup + copie + check config + restart HA
./ha/sync.sh --no-restart
```
Après le premier déploiement de `statistics.yaml` / `suivi.yaml` : redémarrer HA,
puis régler **Début du suivi** (`input_datetime.scale_tracking_start`) à la date
du premier jour de suivi (et après chaque remise à zéro de l'historique) : la
moyenne glissante en dépend.

Configuration par variables d'environnement ou dans `ha/sync.local.env` (ignoré
par git) : `HA_HOST` (obligatoire, `user@hôte`), `HA_PACKAGES_DIR`,
`HA_CONTAINER`, `NOTIFY_SERVICE` (remplace le placeholder de notification) :
```bash
HA_HOST=user@192.168.1.10
NOTIFY_SERVICE=notify.mobile_app_mon_telephone
```

## Initialisation (une seule fois)

Régler manuellement les helpers suivants pour partir d'un état correct :
- `input_number.scale_stock_value_eur` : ce que le stock ACTUEL (poids
  affiché par `sensor.scale_poids`) a coûté (€).
- `input_number.scale_alert_days` : seuil d'alerte (défaut 10 jours).
Le prix unitaire (`scale_unit_price_eur_kg`) se recalcule automatiquement dès
le premier mouvement (automation D).

## Comportement

- **Les mesures arrivent deux fois par jour**, 30 min avant et 30 min après
  l'aspiration quotidienne (18h30 par défaut → 18h00 et 19h00). L'horaire se règle
  dans le **portail de la balance**, et **rien n'est publié sur MQTT** : si vous
  pilotez l'aspiration depuis HA, c'est à vous de la caler sur le même horaire.
  Concrètement, une aspiration déclenchée à 17h55 est vue comme de la
  consommation du jour par l'automatisation (la mesure de 18h00 est déjà passée),
  et une aspiration à 18h10 est vue comme un **appoint** (la hausse dépasse 14 kg
  entre 18h00 et 19h00).

- **Le poids est NET** : la balance soustrait la tare du silo avant de publier
  (`scale/value`). `sensor.scale_poids` est donc le stock de granulés, pas la
  masse totale. Une tare saisie dans le portail décale **tout** l'historique de
  consommation déjà cumulé côté HA : à refaire seulement en mise en service, pas
  en réajustant le stock (c'est aussi pourquoi l'onglet Calibration prévient
  avant de modifier Z : une baisse de tare serait comptée comme de la conso).
- **Baisse de `sensor.scale_poids`** (fiable, `scale_error=off`) → conso :
  ajoutée au compteur cumulé (→ utility_meter daily/monthly/yearly kg et €),
  valeur du stock décrémentée au prix moyen pondéré.
- **`scale/refill/event` déclaré** (`bag_count > 0`) → valeur +=
  `bag_count × bag_price_eur` (coût réel des sacs achetés). Le stock kg n'est
  pas touché par l'event : c'est le poids publié par la balance (`scale/value`,
  remonté au même moment) qui fait foi.
- **Refill sauvage** (`bag_count: 0`, appoint ≥ 14 kg détecté par la balance)
  → valeur += `added_kg × prix_moyen_courant`. Journal : « appoint détecté ».
- **Jours restants** = `scale_poids` / conso moyenne sur 14 jours glissants → alerte
  quand sous le seuil.
- **Les trois alertes** (silo faible, batterie faible, plus de nouvelles) envoient
  une notification sur le téléphone **et** une notification persistante dans la
  cloche de HA. Elle se ferme toute seule quand l'alerte s'annule (silo rempli,
  batterie au-dessus de 20 %, balance qui publie de nouveau).
- **Alerte batterie faible** : notification quand `scale_batterie` passe sous
  20 %. Sous ~3,3 V la balance ne publie plus, l'alerte doit donc la précéder.
- **Alerte « plus de nouvelles »** : notification si `scale_poids` n'a rien reçu
  depuis 6 jours. La balance ne publie que sur changement, batterie ou
  heartbeat (~4 jours) : un silence de 36 h est normal.
- **Le seuil « niveau bas » de l'écran est un AUTRE réglage**, en kg et non en
  jours : il se règle dans le **portail de la balance** (onglet `REGLAGES`,
  défaut 134 kg, soit 20 % d'une capacité de 670 kg). Il ne déclenche
  **aucune notification** — c'est le bandeau `REMPLISSAGE CONSEILLE` sur
  l'e-paper. Les deux seuils sont indépendants : l'un prévient (HA, en jours),
  l'autre signale sur place (l'écran, en kg).
- **Journal des remplissages** (`refill_journal.yaml`) : chaque refill ajoute
  une entrée datée sur 2 lignes (date, détail) dans `input_text` — affiché
  sur le dashboard (dernier + historique).

## Comment le prix du kg consommé est calculé

Méthode du **coût moyen pondéré** (pas FIFO) :

1. **Au refill** : la valeur € du stock augmente du coût réel du lot =
   `bag_count × bag_price_eur` (ou `added_kg × prix_moyen` si appoint sauvage).
   Le poids, lui, est déjà remonté par la balance.
2. Le **prix unitaire courant** = `valeur_stock ÷ scale_poids` (recalculé à
   chaque mouvement par l'automation D).
3. **À chaque baisse (conso)** : on retire `|Δ| × prix_courant` de la valeur du
   stock, et on ajoute la même somme au coût cumulé consommé.

Conséquence : le kg consommé est valorisé au prix **moyen** de tout le stock
présent au moment de la conso — pas au prix précis du lot qui est brûlé. Ex. :
300 kg à 2 €/kg + 300 kg à 1 €/kg → prix moyen 1,50 €/kg ; consommer 100 kg
compte 150 €, quel que soit le lot réellement aspiré. C'est une approximation
qui lisse les achats ; le coût « cash » exact (Σ des factures de refill) est
disponible dans le **journal des remplissages**.

## Dashboard

`dashboard.yaml` : vue **« Silo »** (mode sections) à coller dans l'éditeur brut
d'un dashboard — silo qui se remplit (niveau, jours restants), consommation
jour / mois / année en kg et en €, histogrammes, valeur du stock, prix au kg,
journal des remplissages.

**Prérequis** :

- les packages de ce dossier, y compris `statistics.yaml` et `suivi.yaml`
  (moyenne glissante, jours restants) ;
- les **cartes HACS** : [Mushroom](https://github.com/piitaya/lovelace-mushroom),
  [ApexCharts Card](https://github.com/RomRider/apexcharts-card) et
  [Button Card](https://github.com/custom-cards/button-card),
  [Fluid Level Background Card](https://github.com/gadgetchnnel/lovelace-fluid-level-background-card)
  (le silo qui se remplit) et [card-mod](https://github.com/thomasloven/lovelace-card-mod),
  chargées comme
  ressources du dashboard (HACS le fait à l'installation) ;
- le silo de 670 kg (`TANK_FULL_KG`) : adapter le maximum et les seuils (134 kg
  pour le niveau bas, 268 kg pour l'orange) dans la carte du silo et dans la
  courbe de poids si la capacité est réglée autrement dans le portail.

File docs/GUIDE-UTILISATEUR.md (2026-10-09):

---
title: Guide utilisateur
nav_order: 2
---

# Guide d'utilisation — Balance Silo

Ce document est pour **qui utilise la balance au quotidien** : ce qu'on voit sur
l'écran, ce qu'il faut faire, et ce qui se passe ensuite. Il ne parle ni de code,
ni de compilation, ni de câblage.

Pour le développement, voir [`SPEC-ecrans.md`](SPEC-ecrans.md) (machine à états,
effets de bord, rafraîchissements), [`FONCTIONNEMENT.md`](FONCTIONNEMENT.md) et le
[`README`](https://github.com/baptistev7/ESPScale/blob/main/README.md).

---

## 1. Le principe : un bouton, deux gestes

La balance a **un seul bouton**. Tout se joue sur la durée de l'appui :

| Geste | Durée | Comment il est écrit à l'écran |
|---|---|---|
| **appui court** | moins d'1 s | `● COURT` |
| **appui long** | plus d'1 s | `— LONG` |
| **maintien** | 2,5 s, une barre se remplit | `— LONG` seul, avec une barre |

**Le pied de chaque écran annonce exactement les gestes possibles.** C'est la
règle de l'interface : si un geste n'est pas écrit en bas de l'écran, il ne fait
rien de visible. Un appui court sur l'écran du mode nomade, par exemple, ne
change rien à l'écran — et il n'est donc **pas** annoncé non plus.

> ⚠️ Le libellé `● COURT` signifie « un appui **court** », pas « un second
> appui après un appui long ». Un appui long n'ouvre pas de menu caché.

---

## 2. L'écran principal

C'est l'écran que vous voyez au réveil, quand la balance est posée sur sa base.

| Niveau normal | Niveau bas | En charge (USB) |
|---|---|---|
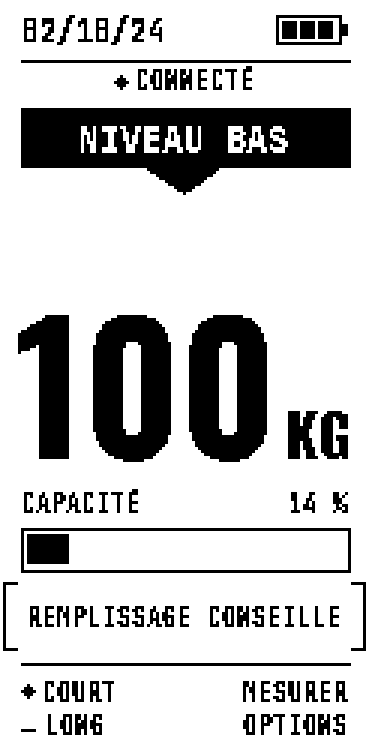
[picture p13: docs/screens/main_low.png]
Niveau bas
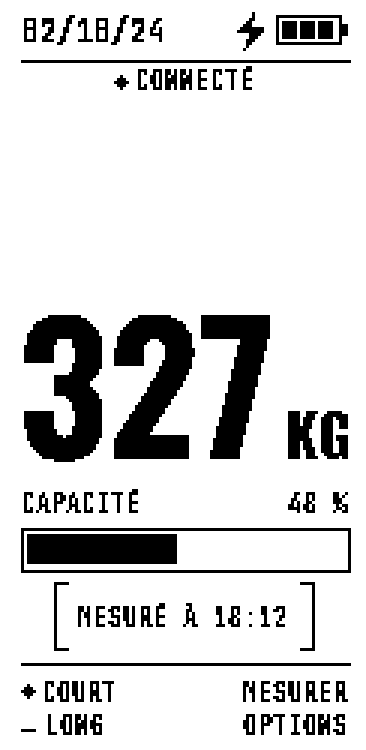
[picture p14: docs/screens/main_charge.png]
En charge
| Écran principal |  |  |

- **En-tête, sur tous les écrans** : la date à gauche, l'éclair si le câble USB
  est branché, la batterie à droite.
- **L'état** sous l'en-tête : `● CONNECTÉ` quand la mesure est bonne, `● KO`
  quand un ou plusieurs pieds ne répondent pas. Le bandeau noir dit alors
  `CAPTEUR(S) HS`, et le poids affiché est la **dernière mesure stable** — la
  zone du bas le rappelle, avec son heure (`DERNIÈRE MESURE` /
  `STABLE À 18:12`). Ce n'est pas le poids actuel.

| Capteur(s) HS |
|---|
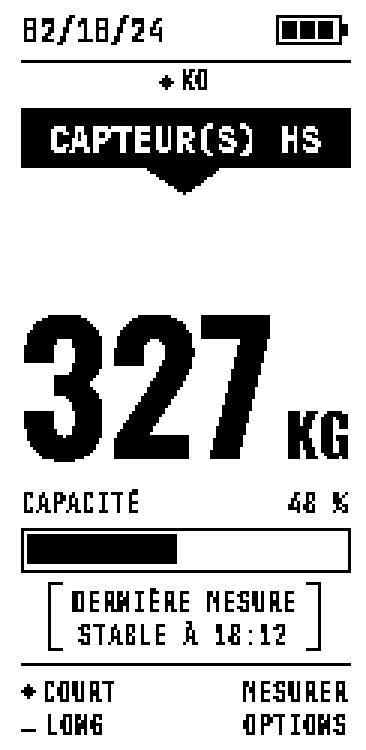
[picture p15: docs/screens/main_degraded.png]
Capteur(s) HS, dernière mesure stable
|  |
- **La zone du bas** dit l'état de la mesure :
  - `MESURÉ À 18:12` — la mesure est faite, rien à signaler ; l'heure est celle
    de la dernière mesure (`MESURE STABLE` si l'heure n'est pas encore connue) ;
  - `ENVOI EN ERREUR` — la mesure n'a **pas** pu être envoyée à Home
    Assistant. En haut de l'écran, `CONNECTÉ` devient `WIFI DÉCONNECTÉ` (WiFi
    absent) ou `MQTT DÉCONNECTÉ` (broker qui refuse). Le poids affiché est bon,
    mais HA ne l'a pas reçu ; l'envoi est retenté à la prochaine mesure, et le
    message disparaît dès qu'il réussit ;
  - `REMPLISSAGE CONSEILLE`, avec le bandeau `NIVEAU BAS` — le poids est passé
    **sous le seuil « niveau bas »** que vous avez défini dans le portail. Il ne
    reste plus grand-chose.
- **La jauge** donne le taux de remplissage du silo (en %), et le poids en
  gros. Le zéro est celui de la calibration des 4 pieds (portail, onglet
  CALIBRATION).

**Les deux gestes :**

| Geste | Effet |
|---|---|
| `● COURT MESURER` | refait une mesure **immédiatement**, et publie le poids à Home Assistant s'il a changé |
| `— LONG OPTIONS` | ouvre le menu (voir §4) |

> La mesure automatique a lieu deux fois par jour, **30 min avant et 30 min après
> l'aspiration quotidienne** (18h30 par défaut → mesures à 18h00 et 19h00).
> `MESURER` est là quand vous ne voulez pas attendre.

---

## 3. Le remplissage (ajouter des granulés)

C'est l'opération principale. Elle se déclenche **depuis la balance**, jamais
depuis Home Assistant : Home Assistant ne voit que le résultat.

Depuis l'écran principal : `— LONG OPTIONS`, puis choisissez `REMPLISSAGE`
(`● COURT` pour descendre, `— LONG` pour valider).

### Les écrans du parcours

```
  ┌──> 1/3 EN COURS  ──● court──>  2/3 NOMBRE DE SACS  ──long──>  3/3 PRIX
  │      le poids                  ● court = +1 sac        ● court = +1
  │      se voit en direct         long = valider           long = suivant
  │                                                             │
  │        ┌──────────────  maintien 2,5 s  ─────────────────┘
  │        ▼
  │   4/3 TERMINER ?  ──● court──> CORRIGER ? ──> sacs / prix ──> TERMINER ?
  │        │       (lâcher en cours = la barre       ANNULER ──> écran principal
  │        │        se vide, rien d'autre)           RETOUR  ──> TERMINER ?
  │        │
  └───────────┴── 5/3 ENREGISTRÉ (1 min) ──● court──> écran principal
```

| 1/3 En cours | 2/3 Sacs | 3/3 Prix | Terminer ? | Enregistré |
|---|---|---|---|---|
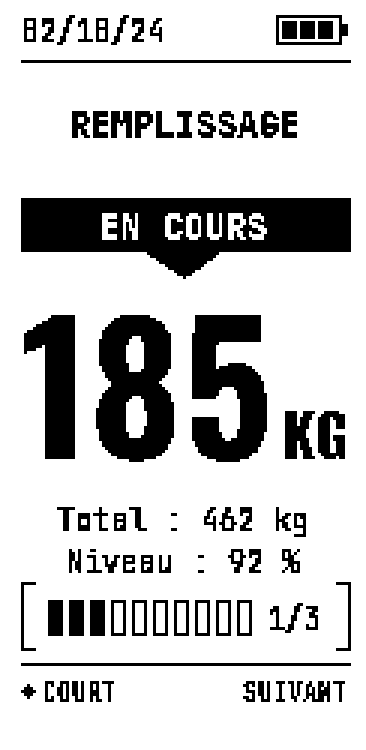
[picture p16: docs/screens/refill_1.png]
Remplissage, en cours
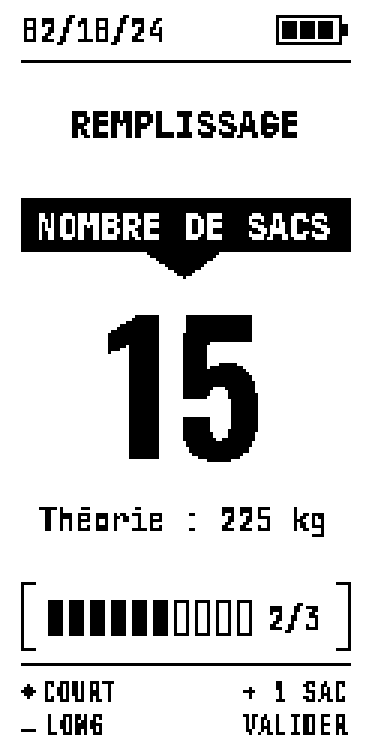
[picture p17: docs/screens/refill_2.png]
Nombre de sacs
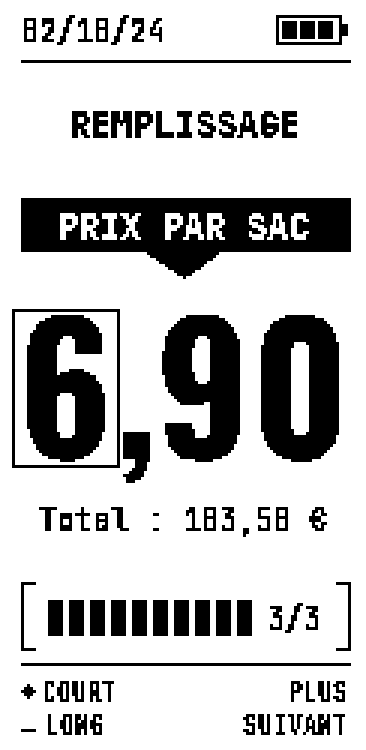
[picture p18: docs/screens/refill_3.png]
Prix par sac
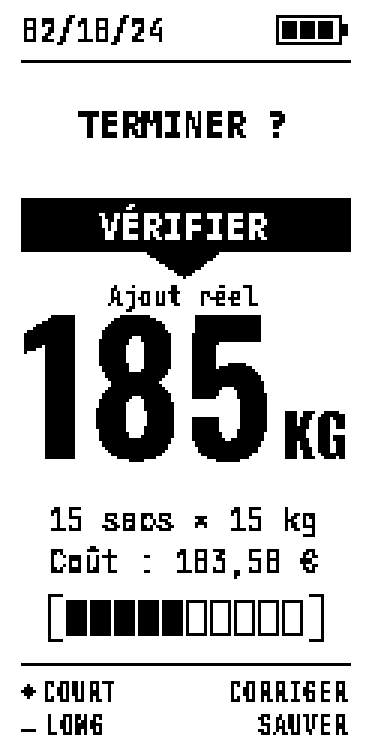
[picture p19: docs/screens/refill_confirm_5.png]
Terminer, maintien en cours
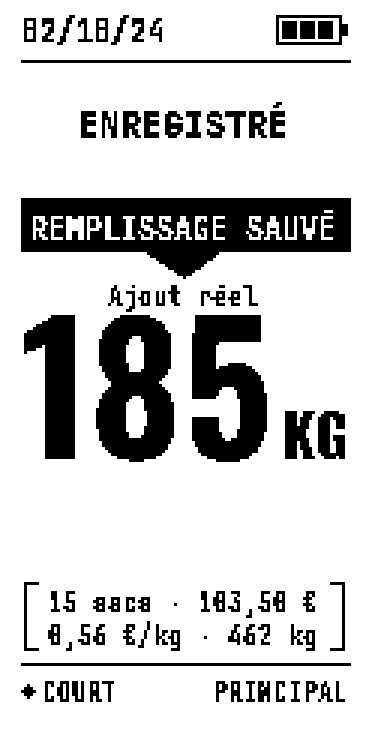
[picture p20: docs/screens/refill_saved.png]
Enregistré
|  |  |  |  |  |

**1/3 — EN COURS.** Le poids versé s'affiche pendant que vous versez : la balance
sonde toutes les 3 secondes et ne redessine qu'au-delà de 0,5 kg. Quand vous avez
versé, `● COURT` passe à la suite.

**2/3 — NOMBRE DE SACS.** `● COURT` ajoute un sac (aussi longtemps que vous
voulez, un sac par appui), `— LONG VALIDER` passe à la suite. La ligne
`Théorie : N kg` est calculée avec le **poids d'un sac** que vous avez défini dans
le portail (15 kg par défaut) : c'est un repère pour comparer au poids versé, pas
une mesure. Si vos sacs pèsent 12 kg, indiquez 12 là-bas.

**3/3 — PRIX PAR SAC.** Saisie **par chiffres** : le chiffre courant est entouré
d'un cadre. `● COURT PLUS` l'augmente de 1 (après 9, il revient à 0), `— LONG
SUIVANT` passe au chiffre suivant, et sur le dernier `— LONG VALIDER` valide le
prix. Le prix se saisit **après** le versement, quand vous savez ce que vous avez
payé.

**4/3 — TERMINER ?** L'écran récapitule ce qui va être enregistré : poids
réellement ajouté, nombre de sacs, coût. **Il faut TENIR 2,5 s** — une barre de
maintien se remplit. Si vous lâchez avant la fin, la barre se vide simplement :
rien n'est enregistré, vous pouvez recommencer. Un **appui court** ouvre
**« CORRIGER ? »** (rien n'est enregistré non plus) :

- `NOMBRE DE SACS` — on recompte les sacs depuis 0 (le prix est gardé) ;
- `PRIX DU SAC` — on ressaisit le prix (curseur sur le premier chiffre) ;
- `ANNULER` — on abandonne la déclaration : le versement est quand même vu par
  la mesure suivante et envoyé en **remplissage sauvage** (sans sacs ni prix) ;
- `RETOUR` — on revient au récap sans rien changer.

`● COURT` passe au choix suivant, `— LONG` le valide. Après une correction, le
récap se réaffiche avec les nouvelles valeurs — il faut à nouveau le tenir
2,5 s. Rien n'est jamais envoyé sans ce maintien.

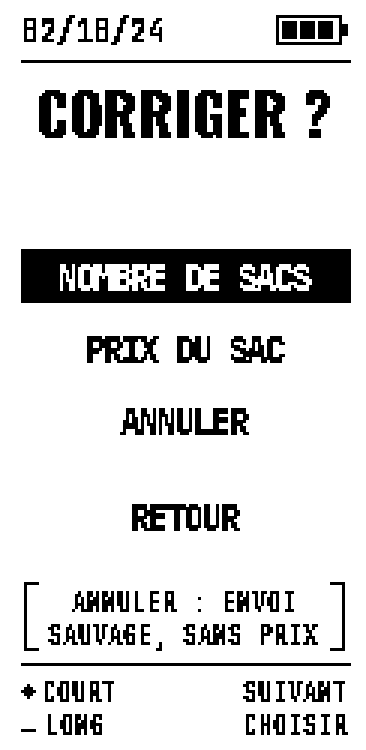
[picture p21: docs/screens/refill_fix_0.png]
Corriger ?


**5/3 — ENREGISTRÉ.** Le récap : sacs, coût, prix au kilo, poids total. Il
s'affiche **1 minute**, puis la balance revient à l'écran principal **sans
re-mesurer**.

> ℹ️ **Abandon.** Sans geste pendant 10 minutes à n'importe quelle étape (ou si
> le poids a **baissé** pendant le versement), le parcours est abandonné : aucun
> prix n'est envoyé. La balance refait aussitôt une mesure normale et revient à
> l'écran principal. Si vous aviez versé au moins ~1 sac (14 kg), cette hausse
> part à Home Assistant comme un **appoint non déclaré** (`bag_count` à 0,
> valorisé au prix moyen du stock).

### Si vous déplacez la balance pendant le remplissage

Pas de souci : elle s'arrête, note où elle en était, et reprend quand vous la
reposez. Si vous ne la reposez pas dans l'heure, le remplissage est **annulé**
et tout repart de zéro.

---

## 4. Le menu OPTIONS

`— LONG OPTIONS` sur l'écran principal (ou sur l'écran nomade). **4 entrées,
toujours les mêmes, toujours dans le même ordre** :

```
  REMPLISSAGE
  PORTAIL RÉGLAGES
  INFORMATIONS
  FERMER
```

| Sur la base | Hors de la base |
|---|---|
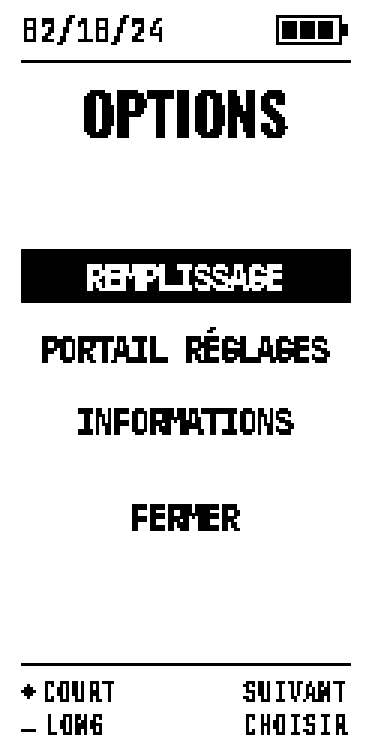
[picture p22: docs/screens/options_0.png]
Menu OPTIONS
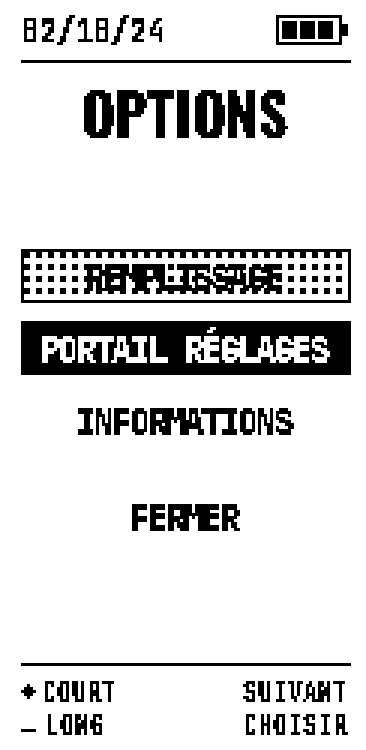
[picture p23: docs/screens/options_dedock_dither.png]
Menu hors base, REMPLISSAGE indisponible
|  |  |

- `● COURT SUIVANT` — une ligne par appui ; le curseur **saute** les lignes
  indisponibles.
- `— LONG CHOISIR` — ouvre la ligne sélectionnée.

`FERMER` vous ramène à l'écran du mode courant. **Sans geste pendant 1 minute**,
c'est pareil : la balance ne reste pas bloquée sur le menu.

---

## 5. L'écran INFORMATIONS (2 pages)

`OPTIONS → INFORMATIONS`.

- **Page 1 — état général** : batterie, Wi-Fi, MQTT, force du signal, état de la
  dernière mesure, nombre de capteurs qui répondent.
- **Page 2 — CAPTEURS** : le poids lu par **chacun des 4 pieds** et le total.

| Page 1 — état général | Page 2 — capteurs |
|---|---|
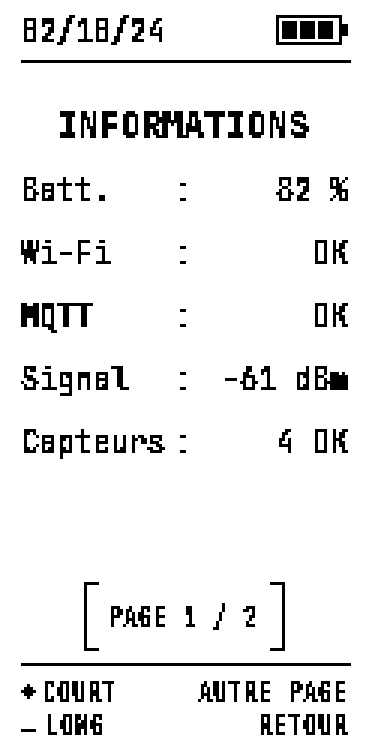
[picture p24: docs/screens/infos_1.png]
Informations, page 1
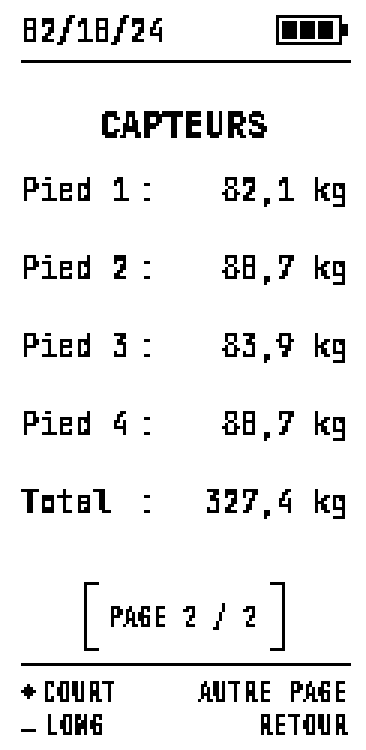
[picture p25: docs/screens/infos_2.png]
Informations, page 2
|  |  |

| Geste | Effet |
|---|---|
| `● COURT AUTRE PAGE` | page 1 ↔ page 2, autant de fois que voulu |
| `— LONG RETOUR` | **retour au menu OPTIONS** |

> Revenir des informations ne vous fait pas sortir du menu : c'est une
> consultation, on peut y aller et en revenir autant de fois qu'on veut. Sans
> geste pendant 1 minute, on revient aussi au menu.

---

## 6. Le mode nomade (balance hors de sa base)

Quand les 4 pieds ne répondent pas, la balance affiche **MODE NOMADE** : elle
sait qu'elle n'est plus sur sa base.

| Avec une mesure connue | Sans mesure |
|---|---|
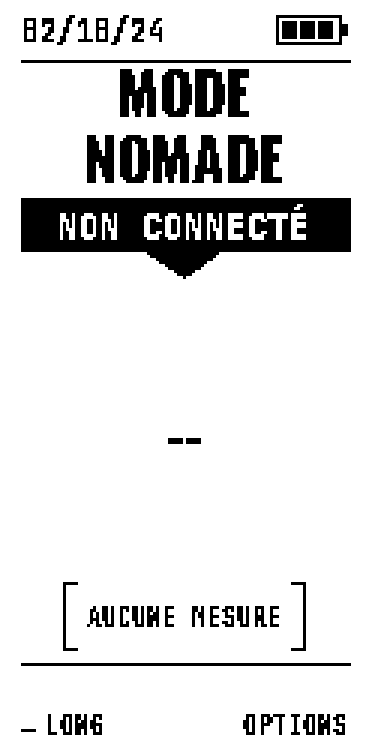
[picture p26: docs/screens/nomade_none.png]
Mode nomade, aucune mesure
| Mode nomade |  |

L'écran rappelle le **dernier poids connu**, l'heure de cette mesure et son
ancienneté : ce n'est **pas** une mesure actuelle (bandeau `NON CONNECTÉ`).

- **Un appui court ne fait rien de visible** — et il n'est donc pas annoncé.
  Il relit seulement l'état de charge.
- `— LONG OPTIONS` ouvre quand même le menu.
- La seule entrée qui change : `REMPLISSAGE` devient indisponible (elle est
  grisée et le curseur la saute). Inutile d'essayer d'y entrer, elle ne peut pas
  fonctionner sans les capteurs.
- En nomade, la balance dort jusqu'à **minuit** (la date de l'écran change,
  elle refait alors un contrôle complet). **En charge**, elle se réveille
  **toutes les 5 minutes** pour montrer la jauge qui monte. Brancher ou
  débrancher l'USB la réveille : l'éclair apparaît ou disparaît en quelques
  secondes.
- Remettez-la sur sa base : elle mesure, publie le retour sur la base (et le
  poids s'il a changé), puis repasse en veille normale. Voir §9 pour le délai.

---

## 7. Le portail de configuration

Pour changer le réseau, le broker MQTT, le silo, l'heure d'aspiration ou
calibrer les pieds : il faut un ordinateur ou un téléphone, pas l'écran de la
balance.

Deux situations :

- **La balance n'a aucune configuration** (neuve, ou remise à zéro) : elle
  démarre directement en portail, toute seule.
- **Elle est déjà configurée** : `OPTIONS → PORTAIL RÉGLAGES`, puis **tenir 2,5 s**
  sur l'écran de confirmation.

L'écran affiche alors `PORTAIL ACTIF` avec le nom du réseau à rejoindre
(`Scale-XXXX`), son **mot de passe** (8 chiffres, nouveau à chaque ouverture) et
l'adresse de la page. Il faut donc être devant la balance pour s'y connecter.
Les mots de passe déjà enregistrés (WiFi, MQTT) ne sont **jamais** réaffichés
dans la page : un champ laissé vide veut dire « inchangé ».

| Confirmation (tenir 2,5 s) | Portail actif | Sans configuration |
|---|---|---|
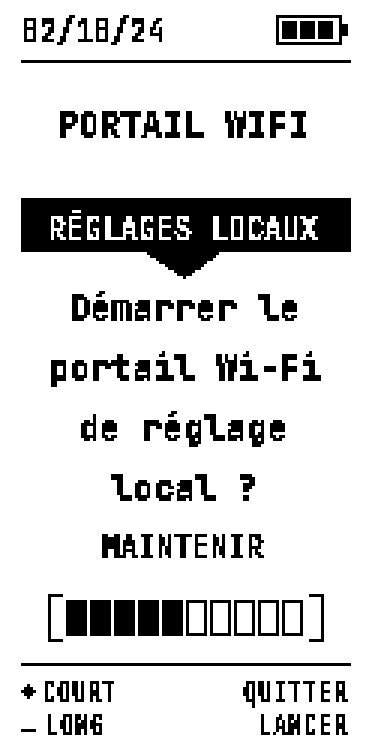
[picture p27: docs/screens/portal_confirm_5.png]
Confirmation du portail
|  | Portail actif | Portail actif, pied VEILLE |

La page a **3 onglets** :

- **ÉTAT** — ce que la balance sait maintenant : poids, niveau, batterie, dernier
  envoi, heure d'aspiration, heures des prochaines mesures. Les valeurs inconnues
  affichent `--` plutôt qu'un chiffre inventé.
- **RÉGLAGES** — WiFi, broker, silo (capacité, seuil « niveau bas », poids d'un
  sac) et horaire d'aspiration, **dans un seul formulaire** : un bouton
  **« Enregistrer et redémarrer »** suffit. La connexion WiFi est testée avant
  écriture : si elle échoue, **rien** n'est enregistré. Le bouton **« Tester
  WiFi + MQTT »**, dans la section du broker, vérifie seulement la connexion au
  réseau et au broker avec les valeurs saisies — il n'écrit rien.
- **CALIBRATION** — la calibration des 4 pieds.

| ÉTAT | RÉGLAGES | CALIBRATION |
|---|---|---|
| Portail, onglet ÉTAT | Portail, onglet RÉGLAGES | Portail, onglet CALIBRATION |

(Captures avec des valeurs d'exemple.)

Le portail se ferme de **deux** façons : **`● COURT REDEMARRER`** sur la balance,
ou tout seul après 10 minutes d'inactivité. Les deux font redémarrer la carte,
qui reprend ses mesures.

**Balance sans configuration** : le pied annonce alors `● COURT VEILLE`. À la
fermeture du portail, elle se met en veille (elle ne se réveille qu'une fois par
jour pour vérifier sa batterie) et l'écran l'indique : **« CARTE EN VEILLE »**,
bandeau `NON CONFIGURÉ`, pied `● COURT RÉVEIL`. Un appui sur le bouton la
réveille et rouvre le portail.

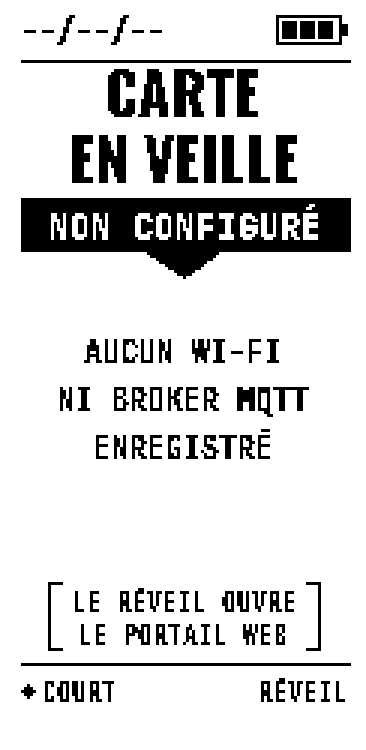
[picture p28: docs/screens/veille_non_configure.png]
Carte en veille, non configurée


---

## 8. Ce que reçoit Home Assistant

La balance **publie**, elle ne reçoit rien. Le poids publié suit un cliquet :

- une **baisse** d'au moins 1 kg est publiée (c'est la consommation) ;
- une **hausse** déclarée par le parcours de remplissage est publiée avec son
  prix ;
- une **hausse non déclarée** d'au moins ~1 sac (14 kg) est publiée comme
  appoint (`refill/event` avec `bag_count` à 0) ;
- une hausse plus petite (dérive, bruit) n'est jamais publiée ;
- le **retour sur la base** est publié (fin d'erreur), même si le poids n'a pas
  bougé.

| Sujet | Contenu |
|---|---|
| `scale/value` | poids net, en kg |
| `scale/battery` | batterie, en % |
| `scale/version` | version du firmware |
| `scale/error/on-off` | `on` = capteurs muets (hors base ou panne), `off` = mesure OK |
| `scale/quality` | `{"valid": n/4, "mode": "…"}` |
| `scale/refill/state` | `pouring` → `pricing` → `saved` |
| `scale/refill/event` | `{"added_kg", "bag_price_eur", "bag_count"}` |

> Le `refill/event` porte **la comptabilité** : coût = `bag_count` ×
> `bag_price_eur`. Un `bag_count` à 0 signale un appoint que vous n'avez pas
> déclaré (hausse d'au moins ~1 sac sans parcours, ou parcours abandonné) :
> Home Assistant le valorise au prix moyen du stock.

---

## 9. Cas rencontrés

**« L'écran affiche un poids qui ne change pas »**
Tant que le poids ne **baisse** pas (ou ne monte pas d'au moins ~1 sac), rien
n'est publié : c'est voulu, pour ne pas noyer Home Assistant de dérive.

**« Je l'ai remise sur sa base, elle ne s'est pas réveillée tout de suite »**
Le retour sur la base réveille la balance **instantanément** par la ligne `DOUT`.
Si ce n'est pas le cas, vérifiez le contact du connecteur pogo : à défaut, le
retour est vu au contrôle complet de **minuit**.

**« Elle affiche une date fausse »**
Le RTC interne est perdu à chaque coupure d'alimentation. La date se recale par
NTP **automatiquement** — mais seulement au réveil où la balance ouvre déjà le
réseau. Une measure à la demande (`● COURT MESURER`) force ce réveil : c'est le
moyen le plus simple de recaler l'heure tout de suite.

**« Les 4 pieds n'affichent pas le même poids »**
C'est normal : c'est pour ça que le silo est posé sur 4 pieds. La page 2 des
informations montre la répartition. Si **un** pied affiche `--`, il ne répond
plus.

**« Le poids affiché est trop élevé / trop bas d'un coup »**
Vérifiez la calibration des 4 pieds (portail, onglet CALIBRATION) : un pied qui
a bougé sur son support ou un zéro refait décale tout le poids. Attention, un
zéro refait décale aussi le poids publié : une baisse est comptée comme de la
consommation par Home Assistant.

**« Comment je reviens en arrière ? »**
Sur chaque écran, `— LONG RETOUR` (ou le maintien demandé) vous ramène. Dans le
remplissage, `● COURT CORRIGER` sur « TERMINER ? » permet de recompter les sacs,
de ressaisir le prix ou d'annuler. Après `ENREGISTRÉ`, on sort en `● COURT`.

**« Un maintien n'a rien fait »**
Lâcher le bouton avant que la barre soit pleine ne fait rien : la barre se vide
et vous pouvez recommencer. Seul un appui **bref** déclenche l'action `● COURT`.

**« L'écran affiche CAPTEUR(S) HS »**
Un ou plusieurs pieds ne répondent plus. Le poids affiché est la **dernière
mesure stable**, avec son heure — pas le poids actuel. Vérifiez les connexions,
puis `● COURT MESURER`.

---

## 10. Ce qui n'est pas fait (à savoir)

- **Pas d'écran miroir sur le portail.** Le portail ne rejoue pas la dalle ; il
  affiche l'état sous forme de valeurs. C'est plus lisible sur un téléphone, et
  cela coûte moins cher en flash.
- **Le portail ne se ferme pas « proprement »** : le bouton fait redémarrer la
  carte, il ne la rend pas au menu. C'est normal — le portail n'a pas de retour
  vers les écrans.
- **Le réveil au redock n'est pas câblé** (ligne `DOUT`). Voir §9.
- **Aucune commande distante.** Le portail ne pilote rien d'autre que le
  rafraîchissement de l'écran. Home Assistant ne peut pas non plus lancer un
  remplissage : le versement se fait à la main.

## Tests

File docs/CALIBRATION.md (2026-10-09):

---
title: Calibration
nav_order: 5
---

# Calibration

Régler les 4 pieds pour que la balance donne le bon poids, comprendre ce qui
compte vraiment dans la mesure, et calibrer la lecture de la batterie.

## Sommaire

1. [Calibrer les pieds (portail)](#calibrer-les-pieds-portail)
2. [Ce qui compte : l'échelle, pas le zéro](#ce-qui-compte--léchelle-pas-le-zéro)
3. [Contraintes du montage](#contraintes-du-montage)
4. [Limites connues](#limites-connues)
5. [Batterie](#batterie)

## Calibrer les pieds (portail)

Onglet **CALIBRATION** du portail (voir [CONFIGURATION.md](CONFIGURATION.md#le-portail-web)).
Chaque pied a deux facteurs : **Z** (le zéro) et **C** (l'échelle, en points
bruts par kg). Ils sont stockés en NVS et appliqués **immédiatement, sans
redémarrage**.

Le tableau compare, pour chaque pied, la valeur **figée au repère** (gris) et la
valeur **actuelle** (gras), en brut et en kg, avec une colonne `Δ raw` et une
ligne **TOTAL**. La ligne du pied le plus chargé s'allume.

**Le silo est fixe** : on ne peut ni le déposer pour tarer, ni charger un pied
seul. D'où la procédure :

1. **Tare des 4 pieds** — silo en place, rien de posé. Le bouton remplit les 4
   `Z` avec la valeur brute courante ; **Enregistrer** (les pieds lisent 0 kg).
2. **Échelle d'un pied** — cliquer **« Repère (avant) »**, poser le **poids de
   test** sur ce pied, saisir le poids réellement posé en haut de page (défaut
   1,96 kg ; **~10 kg recommandé**, ex. un bidon de 10 L), puis **« Δ → C »** sur
   la ligne du pied (`C = Δraw / poids`). **Enregistrer** : le pied doit afficher
   le poids posé.
3. **Répéter** pour les 3 autres pieds.

**Contrôle** : poser le poids n'importe où — la ligne **TOTAL** doit augmenter
exactement du poids posé (la somme ne dépend pas de la répartition).

**Précision** : l'erreur relative sur C vaut celle de `Δraw` divisée par le
poids ; avec 1,96 kg on ne sollicite qu'~1 % de la capacité d'un pied (200 kg) —
assez pour vérifier, mais ~10 kg donnent une échelle nettement plus fiable.

> ⚠️ **Modifier Z décale le poids publié.** La balance ne publie que des
> baisses (voir [MQTT-HOME-ASSISTANT.md](MQTT-HOME-ASSISTANT.md#le-cliquet-de-publication)) :
> une baisse de tare serait comptée comme de la **consommation** par Home
> Assistant. La tare est une opération de **mise en service**.

Tant que rien n'est enregistré, les valeurs par défaut sont les constantes
`Z_FACTOR_x` / `C_FACTOR_x` de `config.hpp`. La sauvegarde de la calibration ne
teste pas le WiFi (une calibration de banc marche sans routeur).

## Ce qui compte : l'échelle, pas le zéro

La consommation se calcule sur des **différences** de poids :

- une erreur de **zéro** constante s'annule dans chaque différence → aucun effet
  sur la conso, seulement sur le stock affiché ;
- une erreur d'**échelle** (C) se retrouve dans **chaque** différence → biais
  proportionnel sur toute la consommation. **C'est le paramètre critique.**

## Contraintes du montage

- **4 pieds**, chacun = **4 cellules de 50 kg** + **un HX711** → 200 kg par pied,
  **800 kg** au total, pour un silo plein à `TANK_FULL_KG` = 670 kg (~84 % de la
  capacité si la charge est bien répartie).
- **Le silo ne quitte jamais sa base** (remplissage par soufflerie) et **n'est
  jamais vide** : les cellules restent chargées en permanence, le poids propre du
  silo fait partie du zéro. **Aucune référence n'est jamais atteignable** : le
  zéro est posé une fois pour toutes à la mise en service.
- Certains pieds sont **quasi inaccessibles**.
- **Le dédock ne crée pas de fausse conso** : boîtier retiré → 0 capteur sur 4 →
  rien n'est publié ; au retour, la charge est inchangée. Seul reste possible un
  petit décalage dû à un ré-appui différent du pogo.

## Limites connues

- ✅ **Conso fantôme par dérive — traitée** par le cliquet de publication : une
  dérive réversible (température, fluage) ne s'accumule plus en fausse conso.
  Seule une excursion vers le bas ≥ 1 kg reste comptée une fois.
- ✅ **Saturation d'un pied — traitée** : une lecture au-delà de la capacité
  physique (`FOOT_CAPACITY_KG` = 200 kg) invalide le pied, la mesure 4/4 échoue
  et **rien n'est publié** (plutôt qu'un faux remplissage).
- **Total négatif ramené à 0** (`sensors.cpp`) : ne concerne qu'une mesure 4/4
  dont la somme serait négative (calibration ou câblage faux) — à garder en tête
  si un câblage bouge.
- **Strict 4/4** : si un seul pied manque, la mesure est ignorée. Aucune
  extrapolation — un poids faux est pire qu'une absence.

## Batterie

Le pourcentage affiché et les seuils de protection (3,3 / 3,2 V) dépendent du
ratio du pont diviseur, `BATTERY_VOLTAGE_RATIO` (`config.hpp`) :

1. Mesurer la tension réelle de la batterie au multimètre.
2. Lire la tension vue par la carte (`readBatteryVoltage()`, logs série).
3. `ratio = tension_réelle / tension_lue × ratio_actuel`, puis recompiler.

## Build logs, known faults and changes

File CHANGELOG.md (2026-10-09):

# Changelog - ESP Scale

## [Unreleased]

## [1.0.1] - 2026-10-09

Correctif : les mesures n'arrivaient pas toutes au broker, et rien ne le disait.

### Correctifs

- **Publications MQTT perdues** : la carte envoyait ses 5 messages en rafale puis
  coupait le WiFi aussitôt ; seul le premier (`scale/version`) arrivait au
  broker, le poids et la batterie restaient à leur ancienne valeur (mesuré en
  écoutant `scale/#` pendant un cycle). Nagle désactivé et envoi laissé partir
  (150 ms) avant la fermeture : les 5 messages arrivent.

### Écran principal

- **Envoi en échec visible** : quand la mesure n'a pas pu être envoyée, `CONNECTÉ`
  devient `WIFI DÉCONNECTÉ` ou `MQTT DÉCONNECTÉ` en haut et la zone du bas
  affiche `ENVOI EN ERREUR` (redessiné en partial, effacé dès qu'un envoi
  réussit). Limite : un broker qui refuse l'écriture en silence (ACL) n'est pas
  détecté, la carte n'ayant pas d'accusé de réception en QoS 0.

### Home Assistant

- **Jours restants sur une moyenne glissante de 14 jours** (au lieu de la
  consommation du jour, indisponible les jours sans consommation) :
  `statistics.yaml`, `suivi.yaml` (début du suivi), `templates.yaml`.
- **Alertes** : batterie faible (< 20 %) et « plus de nouvelles » (6 jours sans
  publication), en plus de silo faible ; notification sur le téléphone **et**
  dans la cloche de HA, fermée toute seule quand l'alerte s'annule.
- **Dashboard « Silo »** refait (cartes HACS : Mushroom, ApexCharts, Button Card,
  Fluid Level Background Card, card-mod) : niveau du silo qui se remplit,
  consommation, stock, historique.
- `ha/sync.sh` lit ses réglages dans `ha/sync.local.env` (ignoré par git).

## [1.0.0] - 2026-10-08

Première version complète : la balance est mesurée sur sa base (veille,
cycles, autonomie) et sa documentation est publiée en ligne.

### Écran principal

- **Rafraîchissement partiel** quand rien d'important ne change : si le poids
  arrondi, la jauge, le bandeau, la batterie et l'éclair sont ceux déjà
  affichés, plus de full (1,5 s, clignotement noir/blanc) mais un partial plein
  cadre (1,2 s, sans clignotement) — ou rien du tout si la date et l'heure de
  mesure n'ont pas changé non plus. Un full revient tous les 20 partials
  (anti-fantôme), à chaque changement d'écran et au démarrage à froid.
- **`MESURÉ À hh:mm`** remplace `MESURE STABLE` dans la zone du bas : l'heure de
  la dernière mesure (`MESURE STABLE` tant que l'heure n'est pas connue ; le
  niveau bas garde `REMPLISSAGE CONSEILLE`).
- **Réveil de 00:02 sur la base** : la date de l'en-tête passe au jour suivant
  par un partial, sans mesure ni réseau ; les mesures restent aux créneaux de
  l'aspiration.

### Batterie

- **Lecture de la tension corrigée** : elle était **0,25 V trop basse** sur la
  T5 V2.4 (ratio calibré sur la V2.3.1). Elle passe par la calibration de la
  puce (`analogReadMilliVolts`, moyenne de 8 lectures, ratio 2,0) : écart
  résiduel ~0,04 V au PPK2.
- ⚠️ **Le % batterie affiché et publié remonte** (batterie pleine : ~72 % →
  ~94 %) : saut visible dans l'historique Home Assistant à la mise à jour. Les
  seuils de protection (3,3 V / 3,2 V) correspondent maintenant à la tension
  réelle.

### Consommation (mesurée au PPK2)

- Veille sur la base **33 µA** (4 HX711 compris), hors base **29 µA**.
- Cycle de mesure **120 à 140 mC** sans publication, **315 à 420 mC** avec ;
  démarrage à froid 500 à 710 mC (le WiFi + NTP en fait 65 à 75 %).
- Autonomie estimée **~10 mois (pessimiste) à ~26 mois (optimiste)** sur
  2000 mAh, autodécharge de la LiPo comprise : la veille et l'autodécharge
  dominent. Détail, hypothèses et graphiques : `docs/CONSOMMATION.md`.

### Documentation

- **Site en ligne** (GitHub Pages, `docs/`) : accueil, menu, recherche, graphiques
  de consommation.
- README et captures d'écran à jour (`MESURÉ À`).

### Outils

- `tools/consommation_graphs.py` : graphiques de `docs/CONSOMMATION.md` (SVG,
  sans dépendance).

### Retiré

- Les bancs de test compilés dans le firmware : démo d'écrans
  `UI_TEST_DASHBOARD` (et ses partials de démonstration), repères de phase PPK2
  et réveils rapprochés ; le script `ppk2_measure.py`.

## [0.12.1] - 2026-10-08

### Écrans

- **INFORMATIONS : `Capteurs` affichait « 0 OK »** alors que les 4 pieds
  remontaient un poids (menu ouvert par un réveil bouton, sans mesure dans la
  session) : le nombre est maintenant compté sur les lectures de l'écran.
- **Ligne `Mesure` (stable / instable) supprimée** : elle ne disait que « 4
  capteurs sur 4 », doublon de `Capteurs`.

### Matériel

- **SCK du pied 3 : GPIO 14 → GPIO 19.** Sur GPIO 14 (CLK du lecteur SD), la
  SCK tenue haute en veille réalimentait `VCC_IO` par la pull-up SD : +190 à
  +480 µA. GPIO 19 tenue haute ne coûte rien (mesuré) : la veille sur la base
  doit tomber vers ~31 µA + HX711 (à mesurer). Le cas spécial « SCK 3 relâchée
  hors base » est supprimé. **Recâbler le fil SCK du pied 3.**
- Correction : GPIO 19 n'a pas de LED identifiée ; seul son état bas coûte
  (+87 µA). Les mentions « LED » sont retirées.

## [0.12.0] - 2026-10-08

### Documentation

- **README réécrit pour un nouvel utilisateur** : ce que fait la balance, ce
  qu'il faut, démarrage en 5 étapes, index de la documentation. Le détail est
  réparti dans `docs/` : `MATERIEL.md` (carte, câblage, modifications, boîtier),
  `CONFIGURATION.md` (flash, portail, `config.hpp`), `CALIBRATION.md`,
  `MQTT-HOME-ASSISTANT.md`, `FONCTIONNEMENT.md` (cycle, bouton, remplissage,
  mode nomade, écrans), `DEPANNAGE.md`, `TODO.md`. Historique des mesures V2.3.1
  déplacé dans `CONSOMMATION.md`.
- Guide utilisateur : le branchement de l'USB réveille la balance (ULP), plus
  besoin d'appui court.

### Consommation

- **Banc de mesure PPK2** : `tools/ppk2_measure.py` (pilote le PPK2 en source
  4,0 V, découpe éveils / sommeil, CSV) et `tools/sleep_floor/` (diagnostic du
  plancher de veille, une configuration par réveil). Résultats et méthode dans
  le nouveau **`docs/CONSOMMATION.md`**.
- **Le plancher de la carte est de 27 µA**, pas 192 µA : les 192 µA venaient
  de pull-ups internes restées actives sur des broches du réseau `VCC_IO`.
  Mesuré aussi : **GPIO 14 tenue haute = +190 à +480 µA** (pull-up SD vers
  `VCC_IO` coupé), **GPIO 19 tenue basse = +87 µA** (LED), ULP / RTC_PERIPH /
  ext0 = 0.
- **Veille nomade : 386 → 29,1 µA** (mesuré). Hors base, la SCK n°3
  (GPIO 14) n'est plus tenue haute — le HX711 est absent, et la broche
  réalimentait `VCC_IO` par la pull-up SD (`prepareDeepSleep(…,
  sensors_present)`). GPIO 19 (LED de la carte) passe en entrée sans pull au
  lieu d'une pull-down qui la faisait conduire.
- `platformio.ini` désigne la carte par son **identifiant stable**
  (`/dev/serial/by-id/…`) : un PPK2 branché prend `ttyACM0`, et flasher
  « ACM0 » écrivait sur lui.
- `USE_CHRG_ULP` surchargeable à la compilation (`-DUSE_CHRG_ULP=0`) pour les
  mesures comparatives.

### Veille nomade

- **Réveil au début et à la fin de charge** : CHRG passe sur **GPIO 34** (RTC) avec une
  **pull-up externe 10 kΩ vers +3V3**, et le **coprocesseur ULP** le lit toutes les ~200 ms pendant le deep sleep
  (`USE_CHRG_ULP`). Il réveille la carte quand le niveau diffère de l'éclair
  affiché sur 5 lectures consécutives (anti-rebond). Plus besoin d'appui court après avoir branché l'USB.
- **Pas GPIO 13 ni 15** (essayées d'abord) : sur la V2.4, leurs pull-ups 10 kΩ
  du lecteur SD sont sur `VCC_IO`, que GPIO 12 coupe avec l'écran. Coupées,
  elles tirent la ligne vers 0 V (~0,6 V mesurés) : « en charge » en
  permanence, et ~60 µA perdus dans la pull-up interne.
- **Le redock passe aussi par l'ULP** en veille nomade : l'IDF refuse ULP +
  ext0 (« Conflicting wake-up trigger »). L'ULP lit donc aussi la ligne DOUT
  (haute = redock → cycle complet), ext0 reste armé sur la base. L'ULP est
  arrêté à chaque réveil et ne tourne qu'en veille nomade.
- La durée du sommeil nomade suit l'**éclair affiché** (5 min s'il est là), plus
  une relecture de CHRG au dernier moment qui pouvait contredire l'écran.

## [0.11.0] - 2026-10-07

### Veille nomade

- **Plus de réveil toutes les minutes ni de cycle de 15 min.** Le redock
  réveille la carte par la ligne DOUT : le timer ne sert plus qu'à tenir l'écran
  à jour. Hors charge, la carte dort jusqu'à **00:02** (ou le quart de batterie
  estimé, `kNomadeQuarterSec` ≈ 94 j, s'il tombe avant ; réveillée avant minuit
  par la dérive RTC, elle se rerendort). Ce réveil fait le cycle complet :
  capteurs (filet du redock), garde batterie, synchro NTP si > 24 h, écran
  redessiné avec la nouvelle date. **En charge**, réveil toutes les **5 min**
  pour montrer la montée de la jauge ; horloge invalide, toutes les heures.
  Compteur `dedock_light_count` et constantes `kNomadeLightPollSec` /
  `kDedockPollSec` supprimés.
- **Appui court sur l'écran nomade : relit la charge** (il était ignoré). Le
  branchement de l'USB n'est vu qu'au réveil suivant — GPIO 19 n'est pas RTC —
  l'appui court fait apparaître l'éclair tout de suite.
- **Partiel de l'en-tête sans flash au réveil.** Avec la coupure écran de la
  V2.4, la RAM de trame est perdue au sommeil et chaque poll faisait un full.
  L'écran nomade est maintenant redessiné **à l'identique** dans les deux RAM du
  SSD1680 (même heure que son dernier full, nouveau champ RTC `disp_drawn_at`,
  layout `STAY`), puis seul l'en-tête change en partiel. Reset matériel de la
  dalle à chaque première init, partial compris.
- L'icône n'est rafraîchie que si ses **segments** ou l'éclair changent, plus à
  chaque point de % (`displayBatteryIconChanged()`).
- **« IL Y A 2 H 34 » devient « MESURÉ LE 07/10 / À 18:12 »** : l'écran n'étant
  plus redessiné qu'une fois par jour hors charge, une ancienneté resterait figée
  et fausse.

### Matériel

- **Pull-down 1 MΩ posée** sur le DOUT du pied 1 : `USE_DOCK_WAKE_DOUT = 1`
  (réveil immédiat au dédock et au redock). Vérifié sur banc : pas de réveil en
  boucle hors base.
- **Fil CHRG → GPIO 19 reposé** sur la V2.4 ; reste à valider avec une batterie
  (sans batterie, le TP4054 ne signale aucune charge).

### Écrans

- **Informations, page 2** : les pieds s'appellent `Pied 1` … `Pied 4` (la
  numérotation de `config.hpp` / `pins.hpp`) au lieu de `AVG` / `AVD` / `ARG` /
  `ARD`, qui supposaient une position physique jamais vérifiée.
- **Correction : poids par pied mal arrondi** — la partie entière était
  arrondie à part de la décimale (82,7 kg affichait « 83,7 kg »). Idem pour le
  total.
- **Nouvel écran « CARTE EN VEILLE »** (bandeau `NON CONFIGURÉ`, pied
  `● COURT RÉVEIL`) quand une carte sans configuration se met en veille à la
  fermeture du portail : la dalle gardait l'écran du portail, mot de passe d'un
  AP éteint compris. Dessiné une seule fois (les réveils de contrôle batterie ne
  le redessinent pas).
- **Capteur(s) KO** : l'écran principal reprend le gabarit du niveau bas —
  bandeau `CAPTEUR(S) HS`, **dernier poids stable** et sa jauge, daté en zone
  secondaire (`DERNIÈRE MESURE` / `STABLE À hh:mm`, ou `LE jj/mm`). Avant :
  ni poids ni jauge, seulement `CAPTEURS KO`.

### Remplissage

- **Lâcher pendant un maintien ne fait plus rien** : la barre se vide et l'écran
  reste, sur « TERMINER ? » comme sur la confirmation du portail (qui quittait).
  Seul un appui court (< 0,4 s, avant que la barre ne commence) déclenche le
  `● COURT`. Un seul helper pour les deux barres (`waitHoldGesture()`).

- **« TERMINER ? » : `● COURT CORRIGER`** ouvre un nouvel écran
  **« CORRIGER ? »** (menu façon OPTIONS) : `NOMBRE DE SACS` (recompte depuis 0,
  le bouton ne sait que +1), `PRIX DU SAC`, `ANNULER` (abandon → le versement
  part en refill sauvage, sans prix) ou `RETOUR`. Avant, tout relâché renvoyait
  au prix, sans moyen de corriger les sacs ni d'annuler.
- **Correction : l'étape « PRIX PAR SAC » était sautée.** Depuis la refonte,
  valider le nombre de sacs menait directement à « TERMINER ? » avec le prix par
  défaut (4,05 €) ; le prix ne se saisissait qu'en relâchant le maintien.

### Documentation

- **Captures à jour** dans `docs/screens/`, embarquées dans le README et le guide
  utilisateur :
  - écrans e-paper : rendu pixel de `tools/preview_charte.py` (nouvelle option
    `--docs`), 18 écrans dont les variantes ajoutées « capteurs KO » et
    « nomade sans mesure ». L'outil écrivait `REMPLISSAGE CONSEILLÉ` alors que la
    dalle affiche `CONSEILLE` : aligné sur le firmware ;
  - portail web : nouveau banc `tools/portal_preview/` qui compile le **vrai**
    `src/webconfig.cpp` sur PC contre des bouchons et capture les 3 onglets
    (Firefox headless, largeur téléphone).
- **Consommation réécrite pour la T5 V2.4** : seule la veille **à vide**
  (**192 µA**) est mesurée ; veille dockée, cycles et autonomie sont marqués
  « à revalider ». Les mesures V2.3.1 (231 µA, ~10 mois) passent en historique.
- **Matériel** : section réécrite pour la V2.4 (CH9102, coupure écran et ses deux
  pièges, modifs à reporter : fil CHRG, pull-down 1 MΩ, pont batterie) ;
  modifs V2.3.1 en historique. Câblage capteurs : mapping à revalider docké.

### Portail web

- **Tableaux lisibles sur téléphone** (vus sur les captures) : la règle
  `th{width:44%}`, faite pour les tableaux libellé/valeur, écrasait les tableaux
  en colonnes — colonne `C` tronquée et bouton `Δ → C` sur trois lignes en
  calibration, canal du scan WiFi coupé en deux. Classe `grid` pour ces tableaux.
- Onglet ÉTAT : « Poids net » devient « Poids » (il n'y a plus de tare silo).

- **« Rafraîchir l'écran » ne fait plus perdre l'écran du portail** : l'écran
  principal dessiné pour le test restait affiché, sans le pied (comment fermer le
  portail) ni le mot de passe de l'AP. L'écran du portail revient seul après
  ~8 s ; la page reste servie pendant ce temps.

## [0.10.1] - 2026-10-06

### Remplissage

- **Plus jamais d'envoi avec un prix non confirmé.** Sur « TERMINER ? », le
  relâché avant la fin ne faisait rien, et seul le délai de 10 min renvoyait à la
  saisie du prix ; après correction, l'enregistrement partait **sans nouveau
  maintien** et avec le prix, le poids et le nombre de sacs figés **avant** la
  correction. Désormais :
  - relâché avant la fin (anti-rebond 80 ms) → retour à la saisie du prix, curseur
    sur le **1er chiffre** (avant, seul le dernier restait corrigeable) ;
  - après correction, la mesure « après » est refaite et le récap se réaffiche
    **recalculé** : il faut le tenir à nouveau 2,5 s ;
  - délai de 10 min dépassé → **abandon**.
- **Abandon câblé vers le refill sauvage** (`refillAbandon()`) : délais du
  versement, du comptage, du prix ou du récap, et poids en baisse. Le parcours ne
  publie rien lui-même ; il repasse en `DOCKED` et enchaîne un **cycle de mesure
  normal** : une hausse ≥ ~1 sac part en refill sauvage (`bag_count = 0`,
  valorisé au prix moyen côté HA), une baisse en consommation. L'écran revient
  sur l'écran principal au lieu de rester sur l'écran du parcours en veille.
- **Remplissage coupé par un reset** (watchdog, chute de tension) : un réveil qui
  trouve encore le mode `REFILL_*` le traite en abandon (même chemin). Avant, la
  carte se rendormait « bouton seul », **sans timer** : plus aucune mesure tant
  que personne n'appuyait, et l'abandon prévu au bout de 2 h ne pouvait jamais se
  déclencher. Le parcours se faisant carte éveillée, le sommeil sans timer est
  supprimé (`prepareDeepSleep()` arme toujours le timer de secours ;
  `kRefillSleepSec` et `kRefillAbandonSec` retirés).

### Veille nomade et retour sur la base

- **Réveil toutes les minutes en veille nomade** : le code n'ajoutait qu'un poll
  léger 1 min après chaque poll complet (donc un suivi de charge à ~15 min). Un
  compteur RTC (`dedock_light_count`, layout d'état 5) fait maintenant 14 polls
  légers (charge seule) puis 1 complet, soit un réveil par minute et un cycle
  complet toutes les 15 min, comme documenté.
- **Le retour sur la base est toujours publié** : la mesure 4/4 qui suit une
  erreur annoncée (dédock, capteurs KO) publie `error/on-off = off` et `quality`
  même si le poids n'a pas bougé. Avant, HA gardait `error = on` (retain) jusqu'au
  heartbeat (~4 jours) ou à la prochaine baisse.
- **Écran nomade : l'appui court ne fait plus rien.** Il relançait une mesure
  alors que le pied n'annonce que `— LONG OPTIONS` (et qu'hors base, il n'y a
  rien à mesurer) ; la carte se rendort.
- **`USE_DOCK_WAKE_DOUT` repasse à 0** : la pull-down 1 MΩ n'est pas posée, et
  sans elle la ligne flotte hors base avec un réveil armé sur HIGH (risque de
  réveils en boucle). Le redock est vu au poll complet suivant (≤ 15 min).

### Portail web

- **Point d'accès protégé** : WPA2 avec un mot de passe de 8 chiffres tiré à
  chaque ouverture et affiché sur l'écran « PORTAIL ACTIF » (3 groupes : réseau,
  mot de passe, adresse). Il faut être devant la balance pour rejoindre le
  portail.
- **Les mots de passe enregistrés ne sont plus renvoyés dans la page** (WiFi et
  MQTT étaient lisibles dans le source par quiconque rejoignait l'AP). Champ vide
  = inchangé, tant que le réseau / l'utilisateur MQTT est le même.
- **« Tester » n'enregistre plus rien.** `parseForm()` écrivait les réglages du
  silo en NVS, y compris pendant le test et quand l'enregistrement était refusé
  (WiFi KO). Le bouton devient « Tester WiFi + MQTT (sans enregistrer) », placé
  dans la section du broker ; la page réaffiche les valeurs saisies (silo
  compris). Le silo n'est écrit qu'avec le reste, après un test WiFi réussi.
- **Texte de confirmation réparé** : `data-mm='… n'est …'` coupait l'attribut à
  l'apostrophe, la popup affichait un texte tronqué. Attributs passés entre
  guillemets doubles.
- **Tare « silo vide » supprimée** (champ, action `/tare`, récap « charge max »)
  : elle faisait doublon avec le zéro de la calibration, et l'installation ne
  permet pas de vider le silo — appuyée avec des granulés, elle mettait le net à
  ~0 et HA comptait tout le contenu en consommation. La clé NVS `silo_tare` est
  effacée au démarrage ; ⚠️ si elle valait > 0, le poids publié **remonte
  d'autant une fois** (refill sauvage si ≥ 14 kg).
- **Carte sans configuration : plus de portail relancé toutes les 10 min.** À la
  fermeture du portail sans enregistrement, la carte dort (réveil quotidien de
  contrôle batterie seul, 1 semaine sous 3,3 V) ; le bouton rouvre le portail.
  Avant, l'AP restait allumé en continu, sans garde batterie. Le pied de l'écran
  du portail le dit : `● COURT VEILLE` sur une carte sans configuration,
  `● COURT REDEMARRER` sinon.
- **`● COURT REDEMARRER` du portail est câblé** : le pied annonçait une action
  qui ne faisait rien — le pire défaut possible, une interface qui promet un geste
  inexistant. La boucle du portail active la capture des gestes et sort sur appui.
  Le libellé passe de `ARRETER` à `REDEMARRER` parce que c'est ce qui se passe :
  `webConfigRun()` est terminale (elle ne rend jamais la main), donc sortir ne peut
  pas revenir au menu, contrairement à l'écran nomade.
  Deux détails non triviaux :
  - la tenue du bouton qui **lance** le portail est absorbée avant d'armer la
    capture — sinon le relâchement serait compté comme un appui long et le portail
    se refermerait dans la seconde ;
  - la capture n'est active que pendant le portail (l'ISR de timer consomme du
    courant) et coupée avant le redémarrage.
  - ✅ **validé sur la carte** : l'appui ferme bien le portail et la carte
    redémarre. L'absorption de la tenue fait son office : le portail ne
    se referme pas tout seul à l'ouverture.

### Réglages

- **Le poids d'un sac est réglable** (onglet Réglages), en NVS
  (`silo_bag_kg`). C'était la seule valeur d'installation encore compilée avec
  son poids réel dans le parcours (`12 sacs × 15 kg`) : le poids d'un sac varie
  selon le fournisseur et l'humidité du granulé, donc c'est une donnée du site,
  pas du firmware. `BAG_KG` devient un simple défaut de formulaire, comme
  `TANK_FULL_KG`. Bornes 1..50 kg.

### Écrans

- **Informations : `● COURT AUTRE PAGE` sur les deux pages** (au lieu de
  `PAGE SUIV.` / `PAGE PREC.`) : le court bascule simplement 1 ↔ 2.
- Maquettes `ECRAN04` (mot de passe de l'AP), `ECRAN18` et `ECRAN19`
  (`AUTRE PAGE`) mises à jour, captures régénérées.

### Documentation

- Guide utilisateur corrigé : `error/on-off` (`on` = capteurs muets), publication
  des hausses non déclarées (refill sauvage), abandon du parcours (la note
  « appoint » décrivait un comportement inexistant), saisie du prix (`● COURT` =
  +1, `— LONG` = chiffre suivant), délai de redock, pied de la page 2 des
  informations, portail (mot de passe, test).
- README et SPEC alignés (veille nomade, abandon, portail, redock, tare).
- Commentaires obsolètes de la V2.3.1 retirés (`pins.hpp`, `power.cpp`,
  `display.cpp`).
- `FW_VERSION` passe à `0.10.1` : le poids de sac réglable et `REDEMARRER`
  étaient sortis sous le numéro `0.10.0`.

### À faire

- Revalider `BATTERY_VOLTAGE_RATIO` sur la V2.4 (calibré sur la V2.3.1).
- Poser la pull-down 1 MΩ puis repasser `USE_DOCK_WAKE_DOUT` à 1.

## [0.10.0] - 2026-10-05

### Portail web

- **Une page de réglages au lieu de trois, un seul enregistrement, un seul
  redémarrage.** Les onglets WiFi, MQTT et silo n'ont pas d'existence propre :
  leurs champs partagent un formulaire unique (« Réglages »), et un bouton
  « Enregistrer et redémarrer » suffit. Le redémarrage est le seul chemin de
  sortie du portail, c'est donc le geste le plus cher de l'interface — le faire
  trois fois pour configurer trois choses était absurde. Exception assumée :
  « Tare silo vide » reste une action à part, qui applique sa tare sans
  redémarrer (c'est une mesure, pas un réglage).
- **La calibration est un onglet du portail**, plus une page séparée avec son
  propre `<head>`, son CSS et son lien de retour. Le CSS est désormais commun.
- **Confirmation par une popup du portail** au lieu des `confirm()`/`alert()` du
  navigateur : ces derniers affichent le nom du domaine du navigateur et
  ignorent le style de la page. Elle sert aux actions destructrices
  (enregistrer + redémarrer, tare silo vide) et aux messages de la calibration.
- **Carte « Ce point d'accès » supprimée** : rien n'y était modifiable, donc
  c'était de l'occupation d'écran pour rien.
- **« Charge max (tare + capacité) » : le récap était un `<tr>` orphelin**
  (hors de tout `<table>`), donc foster-parenté par le parseur HTML et le bouton
  venait se coller à la ligne — l'alignement était cassé. Le récap est maintenant
  dans son `<table class=derived>`, avec une marge propre.
- **« Rescanner » est devenu un lien (GET), plus un formulaire** : il était
  imbriqué dans le formulaire principal, ce qui est du HTML invalide — le
  navigateur fermait le formulaire externe au milieu, et les champs situés après
  n'étaient plus envoyés. Le rescan est de toute façon une lecture.

- **Le portail devient une coquille à 4 onglets** (ÉTAT / RÉSEAU WI-FI /
  MQTT·HA / SILO), sur la base des maquettes `docs/UI/WEB01`–`WEB07`. Une page
  unique qui empilait tous les champs était illisible sur téléphone, et chaque
  enregistrement touchait à tout.
  - **ÉTAT** : ce que la carte sait maintenant, lu de la RAM — poids net,
    niveau, seuil, date de la dernière mesure, batterie, dernier envoi MQTT,
    mode, prochain réveil, RAM libre. Une valeur inconnue affiche `--` au lieu
    d'un chiffre inventé, et la date n'est montrée que si l'horloge est
    synchronisée (sinon « horloge non synchronisée », pas un 01/01 de l'époque).
  - **RÉSEAU WI-FI** : le scan passe d'une liste déroulante à un **tableau**
    (RSSI, **canal**, sécurité) avec un bouton « Choisir » qui recopie le SSID,
    plus un **Rescanner** manuel (le scan coupe le canal de l'AP le temps de
    l'opération : le faire à la demande, pas à chaque chargement).
  - **MQTT · HA** : + le **tableau des sujets publiés**, généré depuis les mêmes
    chaînes que `mqtt.cpp` — il ne peut pas mentir sur le nom d'un topic.
  - **SILO** : capacité utile, tare « silo vide » et seuil « niveau bas » (kg),
    les 3 en NVS sous leurs propres clés donc **appliqués sans redémarrage**,
    + l'action **Tare silo vide** (le poids mesuré devient la tare ; refusé si
    les 4 pieds ne répondent pas, et borné par la capacité).
  - **Rafraîchir l'écran** : redessine l'e-paper avec le **dernier poids déjà
    mesuré**, pour vérifier l'affichage sans attendre le cycle de 18 h. Ce n'est
    pas une mesure.
  - **« Choisir » ne remplissait le champ SSID qu'avec les SSID d'un seul
    mot** : le SSID était écrit comme un littéral JavaScript (`pick(Ma Box)`
    → `SyntaxError`). Le SSID passe maintenant par un attribut `data-ssid`, où un
    espace, un accent ou un chiffre initial n'a rien de spécial, et toute la
    ligne est cliquable.
  - **Enregistrer depuis un onglet ne cassait plus rien** : chaque onglet n'envoie
    que SES champs, alors que la lecture du formulaire en attendait tous — valider
    le mot de passe WiFi depuis l'onglet Réseau renvoyait « Port MQTT invalide
    (1-65535) » (port absent -> 0) et aurait vidé le broker ; inversement,
    l'onglet MQTT aurait vidé le SSID. `parseForm()` part maintenant de la config
    **stockée** et n'écrase que les champs **présents** dans la requête. Un champ
    caché `mqtt_form` lève l'ambiguïté de la case à cocher (une case non cochée
    n'est pas envoyée : impossible de la distinguer d'un formulaire muet).
  - Les actions renvoient **l'onglet d'où l'on vient** (`/save?t=`, `/test?t=`) :
    le verdict du test réaffichait les champs sur l'onglet ÉTAT au lieu de l'onglet
    MQTT, alors que la page annonce le contraire.
  - `/cal` reste la page de calibration des pieds (opération de banc, protocole
    avant/après) et gagne un lien « Retour au portail » : depuis la coquille à
    onglets on y entrait plus sans pouvoir en sortir.
  - `htmlEscape()` sur **toute** donnée saisie (SSID, mots de passe, champs de
    formulaire) : un SSID contenant `'` ou `"` cassait l'attribut HTML et
    pouvait injecter du JS dans la page.
  - Écarté volontairement : le **miroir de l'écran e-paper**, le profil
    d'affichage, les seuils côté HA, le CSV et le syslog. Le portail configure et
    consulte ; au-delà de la tare et du rafraîchissement, il n'exécute rien.

### Affichage

- **FIN de l'ancien style : plus aucun écran ne lui appartient.** Les deux
  derniers rendus hors charte sont supprimés, et le firmware n'inclut plus les
  5 polices Adafruit `FreeMono*` (~40 ko de flash libérés).
  - **écran « capteurs KO »** (`SENSOR_KO`) : supprimé. Tant que la résistance
    de tirage de la ligne DOUT n'est pas posée, « 0 capteurs » veut dire « hors
    base » → c'est l'écran du **mode nomade** (charte) qui s'affiche. La
    distinction panne / dédock reviendra avec le vrai dédock (TODO(dedock) :
    ligne DOUT + résistance). `enterErrorState()` ne demande donc plus la
    confirmation de dédock, et `DisplayScreen::SENSOR_KO` disparaît.
  - **écran texte « TEST »** (`TEST`, FreeMono 9 pt, 10 car./ligne) : supprimé.
    Pendant « Tester WiFi + MQTT » (~15-20 s), le verdict est renvoyé dans la
    **page web** — que l'utilisateur est en train de lire ; l'e-paper n'affiche
    rien (un full refresh de moins). `DisplayScreen::TEST` disparaît aussi.
  - Code mort supprimé : silo ÖkoFEN endormi, « Zzz », jauge à granulés, corps
    de veille, ancienne batterie verticale, `printCentered` / `centeredX`,
    `displayDrawBatteryIcon`.
- **`● COURT RECHERCHER` retiré de l'écran nomade** : le pied ne montre plus que
  `— LONG OPTIONS`. Le re-test manuel du dock était redondant — le redock réveille
  déjà la carte par la ligne DOUT, et le poll complet de 15 min rattrape sinon. Un
  appui court en veille est donc **iner** et **non annoncé**.
- **La date de l'en-tête est récupérée même en veille nomade** (elle restait
  `--/--/--`). Le RTC interne est perdu à chaque coupure d'alimentation et dérive de
  plusieurs % ; or `timeInit()` n'était appelé que par `publishBegin()`, c'est-à-dire
  **uniquement sur un chemin qui publie**. Le chemin dédock ouvrait le réseau pour
  publier l'« offline » mais **sans** synchro NTP → date invalide, et les polls de
  1 min ne la récupéraient pas non plus. `appSyncClockIfStale()` ouvre désormais
  UNE session sur tous ces chemins, **seulement** si l'heure est invalide ou
  vieille de plus de 24 h (`g_ntp_last_sync` en RAM RTC) ; côté veille nomade, le
  poll léger réessaie et **redessine** l'écran quand il récupère l'heure (la date
  ne change qu'au changement d'écran). Vérifié sur la carte après un reset à
  froid : `Clock: syncing (invalid or older than 24h)` puis `NTP synced: …`.
- **Le menu ne s'ouvre plus sur une ligne inactive** : hors base, la sélection
  initiale est `PORTAIL RÉGLAGES` (`menuFirstEnabledRow()`) — avant, le curseur
  démarrait sur `REMPLISSAGE` qui n'est pas sélectionnable hors base : aucune barre
  de sélection à l'écran, et deux appuis pour atteindre la première entrée
  possible. Sur la base posée, `REMPLISSAGE` reste bien la ligne par défaut.
- **`INFORMATIONS` : `● COURT` fait osciller les deux pages** (autant de fois que
  voulu, c'est une consultation) et `— LONG` rend la main au menu — les deux pages
  annoncent désormais les mêmes gestes. Sans geste pendant 1 min, retour au menu.
- **`REMPLISSAGE` hors base : inactif plutôt qu'absent.** Le menu garde ses
  **4 lignes** (l'espacement ne change pas d'un écran à l'autre) ; la ligne est
  dessinée **contour 1 px + tramé 25 %** — le tramage EST le gris sur une dalle
  1 bit — et le **curseur la saute**, pour que « choisir » n'agisse jamais pour
  rien. Un tramé plein rendait les majuscules illisibles : c'est le rendu hors
  matériel (`tools/preview_charte.py`) qui l'a montré.
- **Veille nomade : surveillance de la charge toutes les minutes.** La carte se
  réveillait toutes les **15 minutes** pour un cycle complet (4 HX711 = 2,1 s,
  publications). Elle alterne désormais deux polls : **léger** (1 min, la CHARGE
  seule : ADC + partial de la zone d'en-tête si le % ou l'USB a changé) et
  **complet** (15 min, inchangé). Un réveil qui doit mesurer — redock par la ligne
  DOUT, démarrage, appui sur le bouton — n'est jamais traité comme un poll léger
  (`appRunScheduledCycle(force_full)`), et le drapeau `dedock_light_poll` est
  remis à zéro dès que le mode n'est plus `DEDOCKED`.
  ⚠️ `STATE_MAGIC` passe à `0x53544157` (layout 4, nouveau drapeau en RAM RTC) :
  **au prochain démarrage l'état RTC est réinitialisé une fois** (le poids publié
  n'est plus mémorisé — le cycle suivant le republie, le journal de remplissage et
  l'OTA ne sont pas concernés).
- **Le menu `OPTIONS` est accessible depuis le MODE NOMADE** : `— LONG` sur
  l'écran de veille ouvre le menu, comme sur l'écran principal (avant : les
  2 pages d'informations). Le geste long veut dire la même chose partout.
  - Hors base, `REMPLISSAGE` **disparaît** du menu : l'étape 1 du parcours commence
    par une mesure, donc l'entrée serait une promesse impossible. Le menu passe à
    **3 entrées** (`PORTAIL RÉGLAGES`, `INFORMATIONS`, `FERMER`), lignes à
    104 / 136 / 176 — `FERMER` garde sa ligne. Maquette `docs/UI/ECRAN22/`.
  - `FERMER` rend l'écran du **mode courant** : écran principal avec le dernier
    poids connu si le boîtier est posé, **écran nomade** sinon (afficher une jauge
    de silo et « CONNECTÉ » hors base serait un mensonge).
  - Le pied du mode nomade passe de `— LONG INFORMATIONS` à `— LONG OPTIONS`
    (maquette `ECRAN17` re-rendue).
- **Maquette de la variante « en charge »** : `docs/UI/ECRAN21/` (écran
  principal + éclair dans l'en-tête), avec le rendu pixel dans
  `tools/preview/main_charge.png`.
- **La CHARGE est de nouveau visible — dans l'en-tête, donc partout.** Le
  passage à la charte avait perdu l'éclair : `drawHeader()` ignorait le flag
  `charging`, qui n'était plus que l'état mémorisé en RAM RTC. L'éclair est
  dessiné à `x = 84`, à gauche du bloc batterie, par `drawHeader()`.
- **Le partial de batterie de l'écran nomade peignait l'ancien style par-dessus
  l'en-tête.** `displayShowNomadeBattery()` rafraîchissait une fenêtre 24 × 40
  où il **redessinait l'ancienne batterie verticale** : le séparateur d'en-tête
  et le bloc 3 segments étaient effacés, et l'écran retombait en FreeMono /
  icône verticale dès que le % de batterie changeait (toutes les 15 min en
  veille nomade). Il passe maintenant par la **zone d'en-tête** de la charte
  (`drawHeaderBatteryZone()`, 32 × 19), **partagée** avec le partial de
  `MAIN` — même fenêtre, même dessin, un seul helper.
- **Les 2 écrans de fin du parcours de remplissage** (maquettes `docs/UI/ECRAN14`
  et `ECRAN15`, ajoutées au banc `-D UI_TEST_DASHBOARD`) :
  - `ECRAN14` **« TERMINER ? »** (bandeau `VÉRIFIER`) : ce qui va être
    enregistré — poids **réellement** ajouté (légende `Ajout réel` + héros
    `185 KG`), `15 sacs × 15 kg`, `Coût : 103,50 €` — puis une **barre de
    maintien** en zone secondaire. Il faut **tenir 2,5 s** pour sauver ; relâché
    avant la fin → retour à la saisie du prix, **rien n'est publié**. Pied
    **réduit à une ligne** `— LONG SAUVER` (nouveau helper
    `drawFooterLongOnly()`) : un `● COURT` y serait un geste inexistant.
  - `ECRAN15` **« ENREGISTRÉ »** (bandeau `REMPLISSAGE SAUVÉ`) : le récap sur
    **2 lignes** de zone secondaire (`15 sacs · 103,50 €` puis
    `0,56 €/kg · 462 kg`), affiché **1 minute**, puis retour à l'écran principal
    **sans remesure**. Seul `● COURT PRINCIPAL` est annoncé (l'appui long en est
    un alias).
  - `drawHoldProgress(écran, pct)` : le partial de la barre de maintien est
    désormais **mutualisé** avec la confirmation du portail (même dessin,
    même fenêtre 104 × 22) ; `kHoldConfirmMs` (2,5 s) est partagé par les deux
    écrans à tenue.
  - `enum DisplayScreen` : `REFILLING`/`PRICE`/`CONFIRM`/`RESULT` deviennent
    `REFILL_LIVE`/`REFILL_BAGS`/`REFILL_PRICE`/`REFILL_CONFIRM`/`REFILL_SAVED`
    (un écran = un identifiant).
  - Placement au pixel près de la légende `Ajout réel` : en `JbmXb5` le jambage
    du « j » touchait l'encre du héros (qui commence à y = 105, la pointe du
    bandeau finissant à 92) → **`JbmXb4` à y = 101** (encre 95..103, 2 px
    dessous et 1 px dessus). Le récap d'`ECRAN15` est en `JbmXb4` pour la même
    raison : en `JbmXb5` les crochets de la zone secondaire sortaient des
    marges (2..120 au lieu de 10..112).
- **Convention des pieds : plus de deux-points.** Le nom du bouton reste à
  gauche (`● COURT` / `— LONG`, ancré sur `kMarginL`), l'action est alignée **à
  droite** sur `kMarginR` — c'est cet alignement qui fait la colonne, pas un
  séparateur. Les 10 appels de pied sont repassés en mots nus, et 2 helpers
  one-line completed the set : `drawFooterOne()` (action courte seule),
  `drawFooterLongOnly()` (action longue seule). Effet de bord bienfaisant :
  **4-5 px de budget en plus** par action (`INFORMATIONS`, la plus longue,
  70 → 66 px pour 77 px utiles).
- **Menu `OPTIONS` : 4 entrées, dont `FERMER`.** Le menu a désormais une **issue
  explicite** — sans elle, on n'en sortait qu'en choisissant une action.
  `FERMER` est **séparé** de 8 px des trois autres lignes (`menuRowY()`), ce n'est
  pas une 4ᵉ fonctionnalité, c'est la sortie. Géométrie inchangée par ailleurs
  (base 96, pas 24) et partial de déplacement de la sélection adapté.
- **`VEILLE` retirée du menu** : l'entrée n'était pas définie ; `FERMER` la rend
  sans objet (dormir = écran principal + deep sleep).
- **Anciens rendus du parcours supprimés** (plus de code mort) : écran
  « versement » (silo + granulés + compteur `xN`), saisie de prix en `FreeMono`,
  récap `+X kg / N sacs / X,XX EUR`, écran résultat `Envoye !` / `Annule !`,
  aide-bouton `court`/`long` en 9 pt (`drawHints`) et leurs zones de partial.

- **Signe `€` dans les 5 polices de la charte** : le glyphset couvrait Latin-1
  (`0x20–0xFF`), le signe euro (`U+20AC`) était donc impossible à afficher. Le
  glyphe a été **ajouté sans toucher aux glyphes existants** (retrouvée la taille
  pixel exacte de chaque police en re-rendant un glyphe de référence et en
  comparant bit à bit : 8 / 10 / 12 px pour JetBrains Mono, 20 / 59 px pour
  Oswald wght=700) puis rangé dans le **slot `0x100`**, juste au-dessus de
  Latin-1 ; `utf8Next()` replie `U+20AC` sur ce slot. Un `last = 0x20AC` aurait
  coûté 8237 entrées de glyphe (49 ko de flash) pour un seul caractère. Vérifié :
  les 224 glyphes d'origine sont bit-identiques, et le € a été relu au rendu
  hors matériel dans les 5 polices.
- **Remplissage — ÉTAPE 3/3 « PRIX PAR SAC » : saisie par digits** (ancien
  parcours de l'écran de prix) + **HARMONISATION des 3 écrans**
  (maquettes `ECRAN11`/`12`/`13` régénérées, banc `-D UI_TEST_DASHBOARD`) :
  - les 3 étapes partagent **un seul squelette** (`drawRefillStepBody`) : titre
    `REMPLISSAGE`, bandeau + pointe, héros, contexte sous le héros, barre
    d'avancement en zone secondaire, pied. **Ni sous-titre `ÉTAPE n / 3` ni
    étiquette** au-dessus du héros (`AJOUTÉ`, `SACS`, `PRIX DU SAC` retirés) : le
    bandeau nomme l'étape et la barre d'avancement — identique sur les 3 écrans,
    10 cases et compteur `n/3` — est le seul indicateur d'étape ;
  - étape 3 : le prix est saisi **par digits**, une **case entoure le digit en
    cours** (les trois cases ne tiennent pas à la taille du héros : 122 px, la
    largeur de la dalle) ; étiquette `PRIX DU SAC`, coût total en contexte
    (`Total : 103,50 €`), barre pleine + `3/3`, pied `● COURT PLUS` /
    `— LONG SUIVANT` (`VALIDER` sur le dernier digit). Partial zoné à chaque
    changement de digit.
  - `drawProgressBar(step)` : barre unique (10 cases) et compteur `n/3` dans le
    cadre de la zone secondaire ; `formatDec2()` pour la virgule française.

- **Remplissage — ÉTAPE 2/3 « NOMBRE DE SACS »** (maquette `docs/UI/ECRAN12`,
  ajoutée au banc) : en-tête d'étape commun (`REMPLISSAGE` + `ÉTAPE 2 / 3` sous
  le titre), bandeau `NOMBRE DE SACS`, le **nombre de sacs en héros**, puis
  `Théorie : N kg` (nb × `BAG_KG` — le repère qui sera comparé au poids réellement
  versé), et dans la zone secondaire la **barre d'avancement** (10 cases) avec le
  compteur `2/3`. Pied `● COURT + 1 SAC` / `— LONG VALIDER`.
  - `displayShowRefillBagsUpdate()` : `+ 1 sac` en partial zoné (même fenêtre que
    l'étape 1) — nombre, théorie et barre avancent d'un coup.
  - Nouveau `drawRefillStepHeader(step, steps)` (titre + sous-titre) et
    `drawProgressBar(step, steps)` ; l'étape 1 perd sa barre de 3 cases au profit
    du sous-titre, la barre d'avancement vivant désormais en zone secondaire.
- **Remplissage — ÉTAPE 1/3 « EN COURS »** (maquette `docs/UI/ECRAN11`, ajouté
  au banc `-D UI_TEST_DASHBOARD`) : le parcours de remplissage passe à **3
  écrans**, avec une **barre d'étapes** (3 cases pleine largeur) qui se remplit
  d'une case par écran, `● COURT SUIVANT` / `— LONG TERMINER`.
  - Rendu : titre `REMPLISSAGE`, bandeau `EN COURS` (pointe vers le bas), étiquette
    `AJOUTÉ`, **poids ajouté en héros** (OswaldBold30 + unité, même format que
    l'écran principal), barre d'étapes, zone secondaire **alignée à gauche** sur
    2 lignes (`Total : 462 kg` / `Niveau : 92 %`).
  - **Suivi en direct** : `displayShowRefillLiveUpdate()` rafraîchit en **partial
    zoné** (120 × 122 px, y 94 → 215) le bloc qui bouge — le poids revient en
    vingtaines de kilos, un full par lecture (~1,3 s) serait inutilisable. Sans
    effet si l'écran affiché n'est pas `REFILLING`.
  - Nouveau composant `drawStepBar(step, steps)` et variante de zone secondaire
    `drawSecondaryBoxLeft2(l1, l2)` (cadre pleine largeur, texte à gauche).
  - ⚠️ Le `+` du brief est porté par le libellé `AJOUTÉ` : `+185` fait 110 px en
    `OswaldBold30` pour 110 px utiles, l'unité ne tiendrait plus à côté, alors que
    `185 KG` (109 px) reste dans les marges et garde le format commun.
  - ⚠️ **Parcours pas encore câblé** (l'ancien écran « versement » reste celui
    utilisé par la FSM), et
    l'ancien écran « versement » (silo + granules + `xN sacs`) reste celui
    utilisé par la FSM — il sera supprimé quand les 3 écrans seront là.

- **Nouvel écran de CONFIRMATION de démarrage du portail** (maquette
  `docs/UI/ECRAN07`, ajouté au banc `-D UI_TEST_DASHBOARD`) : l'AP du portail
  étant **ouvert**, le lancement doit être un geste délibéré.
  - Rendu : titre `PORTAIL WIFI`, bandeau inversé `RÉGLAGES LOCAUX` (en
    `JbmXb5` : 105 px en `JbmXb6` pour 110 px utiles), la question centrée sur
    4 lignes (`Démarrer le` / `portail Wi-Fi` / `de réglage` / `local ?`), le
    mot `MAINTENIR`, puis la **barre de maintien** dans la zone secondaire.
  - Barre de maintien : 10 cases entre crochets (`drawHoldBar`), remplies d'une
    case toutes les 10 % en **partial zoné** (~856 ms sans flash) via
    `displayShowPortalHoldProgress()` — repli sur le full si la base n'est pas
    valide. Cases vides en contour 1 px, sinon elles disparaissent sur la dalle.
  - Gestes (`appPortalConfirm()`, `app.cpp`) : **appui court = quitter** (aucun
    changement d'écran, l'appelant redessine), **tenue de 2,5 s = lancement** →
    `webConfigRun()` (la page suivante est bien le portail), relâché avant la fin
    ou **30 s** sans appui = abandon. Durées `kPortalHoldMs` /
    `kPortalConfirmTimeoutMs` regroupées à côté du texte affiché.
  - `DisplayScreen::PORTAL_CONFIRM` ajouté (layout de `ScaleState` inchangé).
  - ⚠️ La page n'est **atteignable que par le banc** pour l'instant : le câblage
    réel se fait depuis `OPTIONS` → « PORTAIL RÉGLAGES », qui attend l'arbitrage
    de l'appui long sur l'écran principal.
  - Le pied ne pouvait pas porter `: MAINTENIR` (55 px en `JbmXb4` → 123 px pour
    116 px utiles) : l'instruction est donc portée par le mot `MAINTENIR` au
    centre, le pied gardant `: LANCER`.
- **Nouvel écran `INFORMATIONS` sur 2 pages** (maquettes `docs/UI/ECRAN14` /
  `ECRAN15`, ajoutées au banc `-D UI_TEST_DASHBOARD`) : charte reprise des autres
  écrans (en-tête date + batterie, titre centré, zone secondaire réservée,
  pied `● COURT / — LONG`), contenu en **tableau à deux colonnes** — libellé
  flush gauche, « : » en colonne fixe, **valeur alignée à droite** (c'est
  l'alignement qui fait la colonne) :
  - **page 1 « INFORMATIONS »** : `Batt.` / `Wi-Fi` / `MQTT` / `Signal` /
    `Mesure` / `Capteurs`, **sans bandeau**, zone secondaire `PAGE 1 / 2`, pied
    `● COURT PAGE SUIV.` / `— LONG RETOUR` ;
  - **page 2 « CAPTEURS »** : même structure que la page 1 — titre (sans
    pagination), tableau à deux colonnes, **pagination en zone secondaire**
    (`PAGE 2 / 2`), pied **réduit à une ligne** `● COURT RETOUR` (dernière
    page : plus de « page suivante »). Les quatre pieds `AVG` / `AVD` / `ARG` /
    `ARD` (pied non valide affiché `--`) sont étalés sur la zone de contenu et le
    **total tient sur une ligne, comme ligne du tableau**. Le bandeau
    `RÉPARTITION` a été retiré (le titre dit déjà la même chose) et avec lui le
    verdict `équilibré`/`déséquilibré` — le calcul est supprimé, pas de code
    mort.
  - `DisplayScreen::INFORMATIONS` ajouté à l'enum (layout de `ScaleState`
    inchangé, `STATE_MAGIC` non bumpé). Les valeurs sont **passées en
    paramètres** (`displayShowInfosGeneral` / `displayShowInfosSensors`) : le
    rendu ignore le Wi-Fi, un relevé réseau réel coûtera une session, à faire
    sur demande uniquement.
  - ⚠️ Titre en `JbmXb6` et non `OswaldBold10` : « INFORMATIONS » fait 121 px en
    Oswald pour 122 px de dalle (il toucherait les deux bords). Un titre long sur
    cet écran demandera une **coupe condensée d'Oswald** à générer.
  - ⚠️ **Gestes non câblés** : aucun chemin n'atteint encore l'écran (ni
    `OPTIONS`, ni l'appui long du nomade).
- **Partial refresh sur l'écran principal et le menu OPTIONS** (banc
  `-D UI_TEST_DASHBOARD`, pour comparer le coût d'un FULL ~1,3 s / flash à un
  PARTIAL ~856 ms / sans flash) :
  - `displayShowMainGauge()` — **jauge de capacité** seule (120 × 31 px,
    y 162 → 192), zone effacée puis redessinée ;
  - `displayShowMainBattery()` — **icône batterie** de l'en-tête seule
    (32 × 19 px, la fenêtre s'arrête avant le séparateur y = 20) ;
  - `displayShowOptionsSelection(from, to)` — **déplacement de la barre de
    sélection** du menu (fenêtre de 2 lignes, 120 px de large) : l'ancienne
    ligne perd sa barre et la nouvelle la gagne dans le même refresh.
  - Dessin **factorisé** (`levelPct`, `drawLevelGauge`, `drawMenuRow`,
    `kMenuItems`) pour que le full et le partial produisent exactement la même
    zone ; chaque helper retombe sur le full de son écran si `canPartial()` est
    faux. Zones alignées sur 8 px en x (adressage SSD1680). Le banc fait
    descendre la jauge et la batterie sur l'écran principal, puis parcourt les
    4 sélections du menu.
  - ⚠️ Ces zones partielles ne servent **qu'au banc** : en production le poids ne
    change qu'à la mesure (donc FULL de l'écran), et le menu n'est pas encore
    câblé.
- **Pointe vers le bas sur les bandeaux inversés** : les bandeaux ne sont plus de
  simples rectangles — un **triangle plein centré** (24 px de large, 8 px de
  profond) prolonge chaque bandeau vers le bas, vers le contenu qu'il désigne (le
  poids, le libellé « DERNIER POIDS CONNU », les infos réseau). Un seul helper
  `drawInvertedBanner(top, h, font, texte, text_y)` sert désormais **les deux**
  positions de bandeau de la charte : l'alerte sous l'état (`NIVEAU BAS`, pointe
  **56 → 63**) et le bandeau sous titre (`NON CONNECTÉ`, `WIFI DE RÉGLAGES`).
  Le bandeau de titre est remonté de 2 px (66 → 84, pointe **84 → 92**) pour
  laisser 2 px blancs avant le texte suivant sur l'écran le plus serré (mode
  nomade). Géométrie vérifiée hors matériel avant l'édition (rendu 1× avec les
  vraies polices), puis compilée.
- **Mode nomade : « DERNIER POIDS CONNU » passe SOUS le poids** (`kNomadeLabelY`
  = 172, au lieu de 100 au-dessus) : le libellé devient la contre-note du nombre
  plutôt qu'un message d'état, et la zone haute se libère. La pointe du bandeau
  « NON CONNECTÉ » pointe désormais directement sur le poids.
- **Portail : libellés `RÉSEAU` / `ADRESSE` agrandis** (`JbmXb4` → `JbmXb5`) :
  à 7 px de haut ils se lisaient trop clairs sur la dalle 1 bit. Les valeurs
  restant en `JbmXb5` (l'URL ne tient pas en `JbmXb6`), la hiérarchie se joue
  désormais sur la casse (libellés en capitales) et non sur la taille.
- **Maquettes `docs/UI/` regénérées** (`code.html` + `screen.png`, capture
  headless au viewport d'origine) : pointe sur les bandeaux `NIVEAU BAS`
  (ECRAN02), `NON CONNECTÉ` (ECRAN17) et `WIFI DE RÉGLAGES` (ECRAN04) ; libellé
  du mode nomade sous le poids ; libellés du portail agrandis. Les `▲` qui
  encadraient `NIVEAU BAS` sur ECRAN02 (absents du firmware) sont retirés au
  profit de la pointe centrée.
- **Nouvelle charte UI e-paper** (polices dédiées + grille commune), déployée
  écran par écran :
  - polices bitmap générées depuis les TTF de la charte (`include/fonts/`) :
    **JetBrains Mono ExtraBold** (`JbmXb4/5/6`) pour le texte technique,
    **Oswald Bold** (`OswaldBold10/30`) pour les titres et la valeur principale —
    plage `0x20–0xFF`, **accents rendus** (fini l'ASCII seul) ;
  - grille commune dans `src/display.cpp` : en-tête **date + batterie 3 segments**,
    zones fixes, zone secondaire réservée `[ … ]`, pied `● COURT` / `— LONG` ;
  - maquettes de référence dans `docs/UI/ECRANnn/` (`DESIGN.md` + `code.html` +
    `screen.png`) ;
  - écrans déjà migrés : **principal** (dashboard) et **OPTIONS** ; les écrans de
    remplissage/veille utilisent encore l'ancien style (migration en cours).
- **Écran du portail : « PORTAIL ACTIF »** (`displayShowConfigPortal`, maquette
  `docs/UI/ECRAN04`) — remplace l'ancien « MODE CONFIG » (logo WiFi) : en-tête
  date + batterie, titre, bandeau inversé **`WIFI DE RÉGLAGES`** (texte en JbmXb5 :
  la chaîne ferait 112 px en JbmXb6, plus large que le bandeau de 110 px), infos
  groupées alignées à gauche (réseau AP ouvert + adresse **`http://192.168.4.1`**,
  en JbmXb5 car 126 px en JbmXb6), arrêt automatique et pied `● COURT ARRETER`
  (une seule ligne). L'AP étant **ouvert**, aucun mot de passe n'est affiché.
- **Timeout du portail porté de 5 à 10 min** (`PORTAL_TIMEOUT_MIN`, `config.hpp`),
  valeur partagée avec l'écran (« ARRÊT AUTO : 10 MIN ») pour rester exact.
- **Écran « MODE NOMADE »** (boîtier retiré du dock, **remplace** l'ancien
  « Boitier retire ») : `displayShowDedock` → `displayShowNomade`, maquette
  `docs/UI/ECRAN17`. Boîtier hors base (0/4), aucune mesure possible : l'écran
  affiche le **dernier poids connu** sous un bandeau inversé **`NON CONNECTÉ`**
  et le libellé **`DERNIER POIDS CONNU`** (jamais une valeur « actuelle »), avec
  l'heure de la mesure (`MESURÉ À 18:12`) et son ancienneté (`IL Y A 2 H 34`)
  dans la zone secondaire sur **deux lignes**. Pied : **`rechercher`** (appui
  court, **câblé** — re-test immédiat du dock) / **`informations`** (appui long,
  hint dessiné — action à câbler).
- **État RTC étendu** : `last_measure_kg` / `last_measure_at` /
  `has_last_measure` mémorisent la dernière mesure valide (4/4), posée à chaque
  mesure (`recordMeasurement`, cycle planifié + FSM refill). L'horodatage n'est
  posé que si l'heure RTC est valide (`timeIsValid`). `STATE_MAGIC` → layout 3.
- Écran ajouté au banc de validation `-D UI_TEST_DASHBOARD` (boucle
  E01/E02/OPTIONS/`PORTAIL`/`NOMADE`).

### Écrans

- **Revenir des informations ramène AU MENU**, comme l'annonce l'écran. Le
  `return` sortait d'`appOptionsMenu()` et la carte allait dormir : le menu
  disparaissait, alors que le pied affichait `LONG RETOUR`.
- **Page 2 des informations : les deux gestes sont annoncés.** Elle n'affichait
  qu'un `COURT RETOUR`, alors que le court bascule les pages et que le long
  ramène au menu — le geste qui fonctionne n'était pas décrit, et le retour au
  menu n'était pas annoncé. Le libellé devient `PAGE PREC.` (d'ici, le court
  ramène à la page 1, pas à une page 3).
- **Maquette `ECRAN19` réparée** : son `<footer>` était un flex `row` au lieu de
  `flex-col`, si bien que les deux lignes de geste se plaçaient côte à côte et se
  chevauchaient (`PAGE SUIV.` par-dessus `LONG RETOUR`).

### Réglages

- **L'heure d'aspiration est réglable** (onglet Réglages, section 4), en NVS
  (`aspiration_min`, minutes depuis minuit). Les deux réveils ne sont plus des
  heures en dur mais les instants qui **encadrent** l'aspiration de **±30 min**.
  Le défaut 18h30 redonne exactement les réveils historiques de 18h00 et 19h00 :
  une carte déjà en service se comporte donc comme avant.
- Le passage de minuit est géré (aspiration 00h15 → réveils à 23h45 et 00h45), et
  les deux créneaux restent toujours distincts.
- L'heure est affichée dans l'onglet **ÉTAT** (aspiration, heures de mesure,
  prochain réveil) et dans la fiche « écran e-paper » — plus aucun « 18 h / 19 h »
  figé dans l'interface.
- Horaire invalide (`25:00`, `abc`) refusé à l'enregistrement, comme les autres
  champs.

### Comportement

- **Le menu `OPTIONS` est câblé et devient la porte d'entrée du produit.**
  L'arbitrage est tranché : **`— LONG` sur l'écran principal ouvre `OPTIONS`**,
  et le remplissage ne part plus que de l'entrée `REMPLISSAGE` du menu.
  - Raison : le pied de `MAIN` annonçait déjà `— LONG OPTIONS` (l'écart était une
    anomalie, pas un choix), et le parcours est désormais 5 écrans + un maintien
    de 2,5 s — un appui long unique ne doit plus enchaîner une saisie de prix puis
    un enregistrement. Conséquence assumée : le remplissage demande **deux
    gestes** au lieu d'un.
  - `appOptionsMenu()` : `● COURT` = ligne suivante (partial zoné, une ligne par
    clic), `— LONG` = valider l'entrée. Les 4 entrées sont câblées :
    `REMPLISSAGE`, `PORTAIL RÉGLAGES` (→ confirmation → portail),
    `INFORMATIONS` (→ les 2 pages), `FERMER`.
  - Filet de sécurité : 1 min sans geste → même effet que `FERMER` (non annoncé au
    pied : le pied annonce les gestes, pas l'absence d'attention).
- **Règles de réveil de l'écran principal** (elles étaient implicites) :
  `MAIN` **part toujours en deep sleep** (ce n'est pas une session interactive) ;
  au réveil, **appui court = mesure à la demande**, **appui long = menu**. Et
  `FERMER` / le timeout du menu reviennent à `MAIN` **sans remesure** — avec le
  dernier poids connu — puis deep sleep.
- **Parcours de remplissage réécrit** : le prix se saisit désormais **APRÈS** le
  versement (`poids → sacs → prix → validation`), pas avant. L'ancien ordre
  (`prix → versement`) remontait le prix d'un sac avant d'avoir versé, et
  obligait à garder le prix en mémoire pendant tout le versement.
  - Étape 1/3 « EN COURS » : le poids **sonde** le capteur toutes les 3 s et ne
    rafraîchit qu'au-delà de **0,5 kg** — le poids n'a aucun geste pour se
    rafraîchir (`● COURT` avance, le long est inerte), donc sans sondage l'écran
    « en direct » ne bougerait pas ; à l'inverse un partial par lecture
    (~856 ms) serait du gaspillage.
  - `● COURT SUIVANT` est désormais la **seule** action annoncée de l'étape 1, et
    son pied est réduit à une ligne : le long y est inerte, l'annoncer serait un
    mensonge.
  - Reprises après dédock redirigées : `BEFORE_MEASURE` → re-mesure « avant »
    puis étape 1 ; `AFTER_MEASURE` → re-mesure « après » puis `ECRAN14` (plus
    l'ancien écran de confirmation). Timeouts 2 h / 1 h inchangés.
- **`scale/refill/state` : nouveau vocabulaire** `pouring` → `pricing` →
  **`saved`**, et l'ancien `docked` **supprimé**. Il décrivait la phase du
  parcours alors que le silo est **hors de sa base** pendant tout le remplissage :
  annoncer « docked » était faux. L'état physique reste porté par
  `scale/quality.mode` (`docked` / `dedocked` / `pouring` / `pricing`) et reprend
  sa valeur réelle au cycle suivant.
- `ScaleMode::REFILL_ARMED` → **`REFILL_POURING`** (ordinal identique, donc
  `STATE_MAGIC` et le layout de `ScaleState` intacts) ; `stateModeName()` renvoie
  `"pouring"` — **⚠️ le champ `quality.mode` passe de `armed` à `pouring`**
  (visible côté HA).
- **`INFORMATIONS` câblé** : entrée du menu **et** appui long sur l'écran nomade.
  Les valeurs affichées sont réelles (session réseau ouverte pour le WiFi / le
  broker / le signal, une lecture par pied pour la répartition) — un « OK »
  inventé serait un mensonge. `wifiRSSI()` ajouté à l'API réseau.
- **Le portail de configuration n'a plus que DEUX entrées** :
  1. **au démarrage**, si le **réseau ou le broker MQTT** n'est pas enregistré en
     NVS. `settingsHasStored()` exige désormais **les deux** clés
     (`wifi_ssid` **et** `mqtt_server`) : tous les autres réglages — calibration
     des pieds, base des topics, identifiants — ont des **valeurs par défaut** et
     leur absence ne déclenche plus le portail. Une carte calibrée pour rien mais
     connectée est donc opérationnelle.
  2. **sur demande**, depuis `OPTIONS` → « PORTAIL RÉGLAGES », après la page de
     confirmation. Ce chemin est de nouveau **atteignable** : le menu est câblé
     (il ne l'était que sur le banc de test).
- **Suppression de l'accès « bouton maintenu au cold boot »** qui ouvrait le
  portail : c'était une troisième entrée, non annoncée à l'écran, qui levait un
  point d'accès **ouvert** sans le dire.

### Documentation

- **Nouveau guide utilisateur** `docs/GUIDE-UTILISATEUR.md` : ce qu'on voit sur
  l'écran, ce qu'on fait, ce qui se passe ensuite. Explication des deux gestes
  (court / long, et le maintien de 2,5 s), parcours de remplissage étape par
  étape, menu, informations, mode nomade, portail, ce que reçoit Home Assistant,
  et une section « cas rencontrés » (date fausse, poids inchangé, pieds
  déséquilibrés, tare à refaire). Le README ne décrivait les gestes qu'au milieu
  d'une section technique.
- **Revue de l'interface Home Assistant** après les changements :
  - le vocabulaire de `scale/refill/state` était faux dans les commentaires
    (`"docked"|"armed"|"pricing"` — `armed` n'a jamais existé) : c'est
    `pouring`/`pricing`/`saved` ;
  - `scale/error/on-off` ne distingue pas dédock et panne : c'est dit, et la
    cause est renvoyée vers `scale/quality` ;
  - `scale/value` est désormais documenté comme **net** (tare soustraite), avec la
    conséquence : une tare saisie dans le portail décale l'historique déjà cumulé ;
  - le seuil « niveau bas » (kg, écran, portail) et le seuil HA (jours) sont
    explicitement distingués — deux réglages qui ne se déclenchent pas l'un
    l'autre ;
  - l'heure d'aspiration n'étant pas publiée, la doc dit comment caler une
    aspiration pilotée par HA, et ce que la balance interprète sinon
    (conommation ou appoint).
  Aucun changement de comportement HA : uniquement de la documentation, plus
  `scale_poids` ajouté au message de l'alerte silo faible.

- **`docs/ecrans-transitions.md` → `docs/SPEC-ecrans.md`**, réécrit en
  **spécification normative** (DOIT / DEVRAIT / PEUT) : carte des transitions,
  entrées et sorties, garde-fous de la FSM de remplissage, portail et sa page de
  confirmation, politique de rafraîchissement full/partial, effets de bord
  (MQTT + RAM RTC) par transition, transitions sans redessin, table des pieds
  annoncés vs gestes câblés, récapitulatif écran → déclencheur, menu `OPTIONS`,
  reste à faire. Mise à jour pour le parcours à 5 écrans, les règles de réveil,
  le menu à 4 entrées et le vocabulaire MQTT.
- **`docs/UI/BASE-DESIGN.md`** : règle de la **légende de héros** (entre la pointe
  du bandeau et l'encre du héros, `JbmXb4` baseline 101) et rappel que le héros
  reste sans `+` ; distinction **barre d'avancement / barre de maintien** ;
  `drawFooterLongOnly()` ; budget de l'action du pied (77 px) ; pas de
  sous-titre d'étape.
- **`tools/preview_charte.py`** (nouveau) : rendu **hors matériel à l'échelle
  1:1** de chaque écran de la charte, en rejouant la géométrie de
  `src/display.cpp` (grille, composants, polices de `include/fonts/`) avec les
  primitives de `render_screens.py`. C'est l'outil qui a permis de valider, sans
  flasher, la légende `Ajout réel` (le jambage du « j » touchait le héros), le
  placement de `FERMER` dans le menu et les crochets du récap d'`ECRAN15` qui
  sortaient des marges.
- **Code mort restant éliminé** : les deux partials de l'écran principal
  (`displayShowMainGauge` / `displayShowMainBattery`) n'ont aucun appelant en
  production — le cycle fait toujours un full, et la veille nomade a son propre
  partial d'en-tête. Ils sont désormais sous `#ifdef UI_TEST_DASHBOARD`, donc
  absents du firmware livré (avec leurs constantes de zone). Également : une
  variable d'horloge morte dans `sensors.cpp`, et un message d'erreur du portail
  **tronqué** (74 caractères dans un buffer de 64 → le lien « Retour » était
  coupé ; buffer porté à 128). `src/` ne compile plus avec un seul avertissement.
- **Rendus obsolètes supprimés** : `tools/render_screens.py` ne génère plus les
  4 écrans de l'ancien parcours (`refilling`, `price`, `confirm`, `result`) —
  les captures correspondantes (`docs/screens/*.png`) sont supprimées ; le
  README pointe désormais vers les maquettes et `preview_charte.py`.
- **Maquettes** : les 12 ont été régénérées après la convention des pieds ;
  `ECRAN14`/`ECRAN15` (nouvelles, fin de parcours) et l'ancienne paire
  `ECRAN14`/`ECRAN15` (informations) devient **`ECRAN18`/`ECRAN19`** ; `ECRAN03`
  passe à 4 entrées ; `ECRAN11` à un pied d'une ligne ; le compteur `n/3` de
  `ECRAN11`/`12`/`13` était collé à la dernière case (réglé).

### À faire

- **Abandonné — vérifier l'échelle d'après les refills** (`sacs × 15 kg`) : les
  capteurs sont déjà calibrés, une calibration refaite sur banc suffit. L'ancien
  raisonnement reste juste en théorie (une erreur d'échelle touche chaque delta,
  contrairement au zéro qui s'annule) mais il ne justifie plus une vérification
  périodique ici.
- Aligner le topic MQTT `scale/quality` : `dedock` est publié pour une panne
  capteur, alors que seul l'écran distingue les deux cas.
- **Réveil au redock** : la ligne `DOUT` n'est pas encore câblée sur la balance
  de dev. Tant que ce n'est pas fait, une balance reposée sur sa base ne se
  réveille pas avant l'heure de mesure suivante (2 fois par jour).
- **Titres longs** : `INFORMATIONS` fait 121 px en `OswaldBold10` pour 122 px de
  dalle ; une coupe condensée d'Oswald est à générer.

## [0.9.2] - 2026-10-02

### Firmware

- **Réveil immédiat dedock/redock par la ligne DOUT d'un pied (sans
  microswitch)** — remplace le contact de présence jamais câblé
  (`USE_DOCK_SENSOR` / `DOCK_SENSE` GPIO 13 supprimés ; `USE_DOCK_WAKE_DOUT`
  ajouté) :
  - **Principe** : le DOUT du pied 1 (GPIO 25) est chargé par une **pull-down
    externe ~1 MΩ côté ESP**. Un HX711 alimenté et en power-down (SCK tenu haut)
    le pilote à HIGH (boîtier posé) ; pogo ouvert → ligne flottante → LOW
    (boîtier retiré).
  - **Réveil `ext0`** (LOW en DOCKED = dédock, HIGH en DEDOCKED = redock),
    **combiné** à `ext1` (bouton, GPIO 39) et au timer de secours. Correction
    d'un commentaire erroné : ext0 et ext1 sont **combinables** (doc ESP-IDF).
  - Au réveil, un **cycle de mesure re-classe l'état** (0/4 → DEDOCKED, 4/4 →
    DOCKED) et publie s'il y a changement ; le redock revient en DOCKED puis
    dort jusqu'au prochain créneau (18h/19h).
  - **Écran dédié « Boitier retire »** (`displayShowDedock`) quand le dédock est
    confirmé (ligne DOUT basse) ; l'écran « Capteurs KO »
    (`displayShowSensorsKo`) reste pour un 0/4 **sans** signal de dédock (panne
    capteur / câblage).
  - ⚠️ **Câblage requis** (pull-down 1 MΩ côté ESP) et **conso à mesurer au
    PPK2** (`ext0` garde le domaine RTC_PERIPH alimenté) ; à valider sur banc.

## [0.9.1] - 2026-10-02

### Boîtier

- **Boîtier v1 : vertical + base (dock)** dans `case/v1/` (projet PrusaSlicer
  `PelletScale.3mf` + un 3mf par pièce), remplace `case/prusa.3mf`. Base,
  connexion pogo, fixation du connecteur et ailettes : faits. Reste le
  contacteur de présence.

### Affichage

- **Écrans harmonisés + défauts corrigés** (portrait 122×250) :
  - **aides bouton identiques** sur les 3 écrans interactifs (prix, versement,
    confirmation) : deux lignes `court` / `long` en police fine, **colonnes
    alignées** (libellé à gauche, action à colonne fixe) — fini le mélange
    « clic: » / « court: » et les 2 vs 4 lignes selon l'écran ;
  - **virgule décimale** partout : la confirmation affichait `12.15 EUR` (point)
    alors que la saisie du prix affichait `4,05` (virgule) ;
  - **montant de la saisie centré** sur la largeur réelle du bloc (il partait
    ~6 px à gauche, alors que le « EUR » dessous était centré) ;
  - **marges rétablies** : les textes qui frôlaient les bords (`Prix du sac`,
    `clic:+1 sac`, `deconnectee` = 119 px sur 122) sont écourtés (« Prix sac » /
    « boitier hors base »), et l'écran texte du portail coupe à 10 caractères au
    lieu de 11 ;
  - détails : `CONFIG.` → `CONFIG`, `Envoye !` / `Annule !` symétriques.
  - **en-tête du principal allégé** : heure `HH:MM` + date `jj/mm` (année
    retirée) en **police fine** au lieu de gras, barre ramenée à 38 px.
  - **écran de configuration sur une ligne** : nom d'AP et adresse IP ne sont
    plus coupés. Le nom d'AP passe de `ESP-Scale-XXXX` (14 car., 151 px) à
    **`Scale-XXXX`** (10 car., 108 px) — `webconfig.cpp`, docs et écran alignés.
  - **batterie verticale vectorielle** : les 5 bitmaps horizontaux 32×28
    (`include/image.hpp`) sont remplacés par un dessin vectoriel (corps 17×32,
    **niveau continu** au lieu de 5 paliers, borne `+`, éclair en charge) ;
    `image.hpp` est supprimé. La zone de partial du dedock suit
    (`kDedockBattery*` : 96,0 / 24×40).
  ⚠️ Les **accents ne sont pas rendus** : les polices Adafruit embarquées ne
  couvrent que l'ASCII (`0x20–0x7E`, vérifié) — « Envoye ! » / « Annule ! »
  restent sans accent (il faudrait générer une police Latin-1 sur mesure).
  Aperçus régénérés (`docs/screens/*.png`) et `tools/render_screens.py` aligné
  sur `src/display.cpp`.

### Firmware

- **Affichage passé en portrait (122×250)** : rotation 0, tous les écrans
  re-mis en page (principal, dedock, remplissage, prix, confirmation, résultat,
  configuration, test), zones de partial recalées, `tools/render_screens.py`
  aligné. Textes raccourcis pour tenir dans 122 px (11 caractères en 9pt).
  ⚠️ **Non vérifié sur la dalle** : orientation (rotation 0 ou 2), débordements
  (textes de 11 caractères collés aux bords), partials — à vérifier et affiner.

- **T5 V2.4 mise en service — coupure d'alimentation écran activée**
  (`USE_EPD_PWR_CUTOFF = 1`, `FW_VERSION` → **0.9.1**). La V2.4 expose
  nativement **GPIO 12 = EPD_PWR_EN** (coupure de la LDO écran), absent de la
  V2.3.1 où l'idée avait été écartée (soudure sous l'écran collé).
  - **Polarité validée sur banc** : GPIO 12 **LOW = écran coupé**, **HIGH =
    écran alimenté** (~1 mA au PPK).
  - **Deep sleep mesuré : ~190 µA** — identique écran branché ou non, GPIO 12
    LOW ou laissé libre, avec l'exemple officiel comme avec un sketch minimal
    (aucun périphérique) : ce n'est **ni l'écran, ni le GPIO 12, ni le
    firmware**, c'est le **plancher de la carte**. Le « ~30 µA » du README
    LilyGO n'est pas reproductible sur cette révision (issue #66 : carte nue
    ~130 µA ; 30 µA seulement après modif matérielle de l'EN du LDO U6 et
    déplacement des pull-ups R4/R46/IO39).
  - `pins::EPD_PWR_EN` (`pins.hpp`) + `epdPowerCut()`/`epdPowerRestore()`
    (`power.cpp`/`power.hpp`) : coupe l'alimentation écran pendant le deep
    sleep (maintenue via le domaine RTC, même mécanisme que les PD_SCK HX711)
    et la restaure avant tout accès SPI.
  - Contrepartie assumée : la RAM de trame du SSD1680 ne survit plus au
    sommeil → `canPartial()` (`display.cpp`) force un FULL refresh au premier
    draw de chaque réveil quand le flag est actif, à la place du hibernate() +
    pull-ups 100 kΩ CS/RST (qui restent le mécanisme de veille sur V2.3.1).
- **Hostname réseau fixé à `pellet-scale`** (`WIFI_HOSTNAME`, `config.hpp`) :
  `WiFi.setHostname()` est appelé avant `mode(WIFI_STA)` dans `wifiConnect()` et
  avant `mode(WIFI_AP_STA)` dans le portail, sinon le core arduino-esp32 annonce
  son défaut `esp32-<3 derniers octets MAC>` au DHCP. L'identité est donc la même
  en cycle nominal et pendant le portail.
- **Horloge décalée (constaté : +45 min) — la synchro NTP n'était jamais
  effective** : `timeInit()` sortait immédiatement si l'heure RTC était
  « valide », or le RTC **survit au deep sleep** → le test était vrai à vie
  après la première synchro et plus rien ne se resynchronisait. L'attente
  reposait en plus sur `getLocalTime()`, qui rend vrai dès que la date est
  plausible (donc grâce au RTC) et ne prouve **pas** qu'une réponse NTP est
  arrivée — le log « NTP synced » s'affichait sans aucune synchro. `timeInit()`
  attend désormais `SNTP_SYNC_STATUS_COMPLETED` via `sntp_get_sync_status()`
  (mode `SNTP_SYNC_MODE_IMMED`), et il est appelé **AVANT l'affichage** de
  l'écran principal (qui porte l'horloge) : le cycle planifié et l'écran dégradé
  ouvrent la session réseau via `publishBegin()` (WiFi + NTP) avant le rendu,
  puis publient via `publishSend()` — le MQTT reste APRÈS l'affichage. Cause de
  fond de la dérive : `RTC_SLOW_CLK` = oscillateur **RC interne** (le module n'a
  pas de quartz 32,768 kHz), que le `kRtcDriftCompensationSec = 15` (pansement
  fixe) ne pouvait pas compenser. Détaillé dans le README
  (« Horloge décalée à l'écran »).

### Décisions

- **Pas de reprise d'un `refill/event` en échec** ni de trace d'annulation : si
  la publication échoue (ou si l'utilisateur annule), le cycle suivant voit la
  hausse ≥ 14 kg et émet un **refill sauvage** (`bag_count: 0`) — la compta reste
  juste, valorisée au prix moyen. Pas de retry dédié, pas de `state = cancelled`.
- **Pas de sauvegarde/buffer des envois** : une publication manquée est
  simplement republiée au cycle suivant (poids/batterie via `last_send_ok`),
  sans persistance supplémentaire.
- **Pas de compensation en température : décision RETIRÉE (analyse à refaire)** —
  le premier chiffrage était faux (raisonné sur 4 cellules au lieu de 16). Avec
  4 cellules de 50 kg **par pied** et 4 pieds, la dérive de zéro vaut
  ~0,05-0,4 kg/°C, soit **~0,5-2 kg pour 10 °C** : au niveau du seuil de
  publication de 1 kg. Dans un **atelier non isolé, avec la chaudière**, les
  amplitudes sont réelles. À mesurer avant de trancher.
- **Montage réel : silo fixe, jamais vide** — le silo ne quitte jamais sa base
  (remplissage par soufflerie) et n'est jamais vide (remplissage avant la fin) :
  les cellules restent **chargées en permanence** et le poids du silo fait partie
  du **zéro**, posé une fois pour toutes (aucune référence d'étalonnage
  atteignable). Le **« dedock » = retirer le boîtier de sa base** (pogo séparé,
  ex. recharge USB) → 0/4 HX711 → `DEDOCKED`. C'est un geste **réel et
  récurrent** ; comportement cible et contact de présence décrits dans le README.
- **Le silo est taré ENTIER** : le zéro est posé sur la somme des 4 pieds, avec
  le silo en place. Il n'y a donc **pas** de suivi par pied à exposer, ni de
  support multi-réservoirs : ces pistes sont écartées (le poids qui compte est la
  charge totale du silo, telle qu'elle est publiée).

### À faire

- **Capteurs — mesurer le plancher de bruit vs température** (décide du reste) :
  relever poids + température ambiante sur plusieurs jours (dont un cycle de
  chaudière). Si la dérive descendante franchit 1 kg → chaque excursion basse
  compte une (petite) conso fantôme ; le cumul est traité par le cliquet, mais le
  seuil reste à arbitrer.
- **Capteurs — vérifier l'échelle aux refills** : la hausse mesurée doit valoir
  `sacs × 15 kg`. C'est la seule référence d'étalonnage disponible (le zéro, lui,
  ne l'est pas) ; corriger `C` si biais constant (l'erreur d'échelle
  touche **chaque** delta, contrairement au zéro qui s'annule dans les deltas).
- **Réveil matériel immédiat au redock** : `ext0` sur le DOUT d'un pied (GPIO
  RTC 25/33/26) + pull-down externe ~1 MΩ — HIGH docké, LOW dédocké. À câbler
  et valider sur banc (sans lui, redock vu au poll suivant, ≤ 15 min).
  Alternative en réflexion : aimant + capteur magnétique.
- Réglages supplémentaires dans le portail (seuils batterie, horaires).

## [0.9.0] - 2026-09-14

### Firmware

- **Consommation par phase — mesures PPK2** (alimentation 4,0 V) : capteurs
  **1,152 s à 59,2 mA** (68,2 mC), **cycle complet** (réveil + WiFi/MQTT)
  **4,281 s à 71,1 mA** (304,5 mC), **cycle sans changement** (aucune
  publication, donc pas de WiFi) **2,549 s à 55,4 mA** (141,2 mC), deep sleep
  **231,4 µA** (5,196 s, max 251,5 µA). Les phases manquantes se **déduisent** du
  couple de cycles : **affichage ~1,40 s / ~52 mA / ~73 mC** et **WiFi/MQTT
  1,732 s / ~94 mA / 163,2 mC**. L'affichage déduit retrouve la mesure directe
  antérieure (1,190 s / 71,4 mC) — les trois phases sont donc cohérentes.
  → **Autonomie ≈ 5,7 mAh/jour, soit ~10 mois** sur batterie 2000 mAh (~1800 mAh
  utiles, arrêt à 3,3 V), à 2 réveils/jour (1 cycle publiant + 1 muet).
  ✅ La veille **avec les HX711 branchés** est retombée au plancher
  (**231 µA**, contre ~7-10 mA) — voir le point suivant.
- **Maintien du niveau haut de PD_SCK pendant le deep sleep** — correctif écrit
  pour la veille élevée **avec les HX711 branchés** (~7-10 mA, contre ~250 µA
  débranchés : le delta vient du chemin HX711). C'est le niveau haut de SCK qui
  garde un HX711 en power-down ; le domaine numérique s'éteignant au sommeil, il
  faut **tenir** le pad. Le simple verrou ne suffit **pas** (mesuré au
  multimètre : SCK 14 oscillant 2,2-3,3 V, DOUT 22 oscillant, HX711 rallumés) :
  `rtc_gpio_hold_en()` fige un état RTC qui ne reflète pas la sortie numérique.
  Les 3 SCK **RTC** (32/14/27) sont donc désormais **basculés sous le domaine
  RTC** (`rtc_gpio_init` + sortie haute + drive max) — le domaine RTC reste
  alimenté au sommeil, c'est lui qui pilote la ligne. Le seul SCK **numérique**
  (21) garde `gpio_hold_en()` + `gpio_deep_sleep_hold_en()`.
  `powerReleaseSensorHold()` (au début de `sensorsInit()` et dans
  `sensorsPowerOn()`) libère le maintien **et** rend les pads au chemin numérique
  avant de piloter SCK — sinon `power_up()` est un no-op silencieux (HX711
  éteints → faux dedock).
  ✅ **VALIDÉ sur banc** : les 4 SCK à **3,3 V franc** au sommeil (contrôlé hors
  dock, sans HX711 pour tirer la ligne) et veille **231,4 µA** **base branchée**
  — plancher retrouvé, **aucune résistance de pull-up nécessaire**. ✅ Cycle
  réveillé validé : écran principal **4/4** (et non le dedock) — le
  `rtc_gpio_deinit()` rend bien les pads au chemin numérique.
  → `docs/courant-veille-hx711-a-creuser.md`.

## [0.5.0-pre.1] - 2026-09-11

### Firmware

- **Calibration des pieds : tare des 4 pieds d'un coup, repère avant/après,
  total.** La page « Calibration » est adaptée au montage réel (silo **fixe**
  reposant sur les 4 pieds) :
  - le bouton **Tare** porte désormais sur les **4 pieds simultanément** (silo en
    place, rien d'ajouté) — on ne peut pas les tarer un par un ;
  - le calcul de `C` se fait sur une **différence avant/après** (bouton
    **Repère**), parce que le poids de test posé sur un pied influe légèrement sur
    les autres : `C = Δraw / poids` sur le pied concerné seulement ;
  - **le champ demande le poids réellement posé** (défaut **1,96 kg**, le poids
    de référence disponible ; **recommandé ~10 kg**, ex. un bidon de 10 L d'eau —
    l'erreur sur `C` diminue quand le poids augmente) ;
  - **le tableau compare avant/après sur `raw` ET `kg`** : chaque cellule montre
    la valeur **figée au repère** (gris) puis la valeur **actuelle** (gras), avec
    une colonne `Δ raw` et une ligne **TOTAL** traitée pareil. La ligne du pied le
    plus sollicité s'allume (on voit l'influence croisée) et l'état du repère est
    affiché (heure de prise, ou « non pris ») avec de quoi l'effacer ;
  - **bug corrigé** : cliquer « Repère » **avant** le premier relevé figeait des
    valeurs `NaN` et le Δ restait `-` définitivement ; `mark()` prend désormais une
    mesure fraîche avant de figer, et prévient si aucun pied n'est disponible ;
  - relevé serveur passé à 2 échantillons par pied (le Δ sautillait), sondage à 2 s ;
  - présentation retravaillée (cartes, tableau lisible sur mobile), et le lien vers
    la calibration est une vraie carte cliquable sur la page de configuration.

## [0.4.0] - 2026-09-11

### Firmware

- **Calibration des pieds dans le portail web (Z/C), sans recompiler.** Une page
  « Calibration » affiche `raw` + `kg` des 4 pieds (rafraîchis en continu : on
  appuie sur un pied, on voit l'avant/après), avec un bouton **Tare**
  (`Z := raw` courant) et un bouton **Calculer C** depuis un poids connu
  (`C = (raw − Z) / poids`). L'enregistrement va en **NVS** (clés propres,
  distinctes du WiFi/MQTT — enregistrer l'un ne touche pas l'autre) et s'applique
  **immédiatement**, sans redémarrage. La route de sauvegarde ne teste pas le
  WiFi : une calibration de banc doit marcher sans routeur. Les constantes
  compilées (`Z_FACTOR_x` / `C_FACTOR_x`) deviennent les **valeurs par défaut**.
  ⚠️ Modifier `Z` décale le poids publié (le cliquet compte les baisses comme de
  la conso) : opération de mise en service — l'avertissement est affiché sur la
  page.
- **Suppression du mode test matériel et du menu de démarrage.** Bouton GPIO 39
  maintenu au reset → **portail directement** (le menu n'aurait plus qu'une
  option). Le diagnostic CHRG embarqué disparaît avec lui ; l'état de charge
  reste affiché sur l'écran principal (icône batterie + éclair).
- **Filtre de plausibilité des capteurs resserré sur la capacité physique** :
  il acceptait par pied `[-TANK_FULL_KG, TANK_FULL_KG × 1.5]` = **[-670, +1005]
  kg** alors qu'un pied **sature à 200 kg** (4 cellules de 50 kg). Un pied
  surchargé plafonnait donc à une valeur qui franchissait les deux contrôles et
  était publiée comme une hausse légitime — donc un **faux « refill sauvage »**
  (≥ 14 kg) valorisé au prix moyen côté HA. Désormais borné par
  `FOOT_CAPACITY_KG` (200 kg/pied) et `TANK_CAPACITY_KG` (800 kg au total,
  somme des 4 pieds). Une lecture impossible est **rejetée** : le pied devient
  invalide, la mesure 4/4 échoue et **rien n'est publié** (une absence vaut mieux
  qu'une valeur fausse, qui créerait une fausse conso). Les deux voies de lecture
  sont alignées (`sensorsReadTotalWeight` et `sensorsReadFoot`, cette dernière
  servant aussi à la calibration dans le portail).

## [0.3.0] - 2026-09-11

### Firmware

- **Cliquet de publication « gel au mini »** : le palier publié (RAM RTC) ne
  remonte **jamais** sur une hausse < 1 sac (14 kg) — cette hausse n'est **pas
  publiée** et le palier reste gelé à son minimum ; heartbeat, batterie et retry
  republient le palier **inchangé** (et non le poids courant). Une dérive
  réversible du zéro (température, fluage) ne s'accumule donc plus en fausse
  conso : HA ne voit que des **baisses** (conso) et des **refills**. Une hausse
  ≥ 14 kg (refill sauvage) reste le seul cas de remontée du palier.
- **Refill déclaré : le poids du silo est republié** (`scale/value`, retain) en
  même temps que `refill/event`, et le palier RTC est relevé. Avant, seul
  l'event partait : le cycle suivant revoyait la hausse ≥ 14 kg, la publiait et
  émettait un **second** event (`bag_count: 0`) → valeur € comptée **deux fois**
  côté HA. Le stock kg est désormais à jour dès la confirmation.
- **Écran DEDOCKED reformulé** : « Capteurs KO / base deconnectee / ou panne
  capteur ». L'écran est **sur le boîtier** : l'ancien « En veille / en attente
  du reservoir » laissait croire à un silo mobile, et « hors ligne » était faux
  (le 0/4 = base déconnectée ou panne capteur, pas une perte de réseau).

### Affichage : partial refresh et un seul full refresh par rendu

- **`display.init(..., initial=false, ...)`** : l'init ne déclenche plus le
  `clearScreen()` interne de GxEPD2. Avec `initial=true`, chaque affichage
  enchaînait **deux** full refresh — le clearScreen (blanc) puis le rendu du
  contenu. Le rendu écrit la totalité de la RAM de trame avant de rafraîchir,
  donc l'écran reste entièrement défini et le temps d'affichage est divisé par
  ~2 (2,7 s → 1,36 s mesurés).
- **`EpdPanel` (`include/epd_panel.hpp`) : mise à jour partielle.**
  Le driver `GxEPD2_213_GDEY0213B74` (full refresh rapide) n'implémente pas de
  LUT partielle → son « partial » exécutait le waveform OTP plein écran (flash
  global). `EpdPanel` en dérive et n'emprunte au `GxEPD2_213_BN` (driver de la
  dalle DEPG0213BN, même contrôleur SSD1680) que la séquence partielle : LUT
  `0x32` + `_PowerOn` + `0x22 = 0xcc`. Mesuré sur la carte : partiel **~856 ms**
  (vs ~1,36 s en full), **sans flash**. Rien n'est patché dans `.pio/libdeps`
  (non versionné).
- **Fantôme dès la 2e mise à jour — corrigé** : le driver GDEY n'écrit que le
  buffer *current* (`0x24`) dans `writeImageAgain`/`writeImagePartAgain`, alors
  que la mise à jour SSD1680 est **différentielle** (current vs *previous*
  `0x26`) → le *previous* restait l'image d'avant et le différentiel était faux.
  `EpdPanel` surcharge ces deux méthodes pour écrire les **deux** buffers, comme
  le `213_BN`. (C'est aussi ce qui faisait flasher le partiel natif du GDEY.)
- **Partial refresh intégré à l'UI** (cycle de vie de la dalle
  `displayPanelWake/Off/DeepSleep`, `hibernate()` appelé une seule fois dans
  `goToSleep` pour préserver la RAM de trame, cache d'affichage en RAM RTC,
  anti-ghosting `kFullRefreshEveryN`, repli automatique en full si l'écran a
  changé) :
  - **écran principal** : **full** (affichage de fond net et prévisible) ;
  - **dedock** : seule l'**icône batterie** est rafraîchie (partial zoné) quand
    le % ou la charge change ;
  - **remplissage** : **partial zoné** à chaque geste (montant du prix, compteur
    de sacs), **full** au changement de digit et **tous les 10 sacs**.
- **Aucun clic perdu pendant les refresh** : les appuis du bouton sont captés
  par une **ISR de timer matériel (1 kHz)** — et non par la boucle principale,
  qui est bloquée pendant le BUSY de la dalle (~856 ms), les connexions
  WiFi/MQTT et les mesures. Les clics d'une rafale sont rejoués un par un (un
  refresh chacun), l'écran « court après » sans en perdre aucun.
- **Dedock : poll batterie toutes les 15 min + partial zoné.** Le dedock dort
  désormais **15 min** au lieu de 24 h (`kDedockPollSec`, le boîtier est alors
  sur USB pour recharge) et, à chaque réveil, relit batterie + état de charge et
  ne rafraîchit que l'**icône batterie** (partial zoné) si l'état a changé —
  sans WiFi. L'erreur n'est annoncée qu'une fois (mode RTC `announced_error`),
  car le mode est remis à `DOCKED` en début de cycle pour re-tester les capteurs.

## [0.2.0] - 2026-09-11

### Portail de configuration web (WiFi + MQTT)

- **Configuration sans recompiler** : SSID/mot de passe WiFi et serveur/port/base
  des topics MQTT se saisissent dans un **portail captif** embarqué
  (AP `ESP-Scale-XXXX` + `WebServer` + `DNSServer`, aucune lib externe), stocké en
  **NVS** (`settings.hpp`). La connexion WiFi est **testée avant écriture** : une
  config invalide n'est pas enregistrée (pas de verrouillage dehors).
- **Liste des réseaux WiFi détectés** : le portail scanne à son démarrage et
  propose les SSID dans une liste déroulante (avec niveau de signal et « ouvert ») —
  le nom du réseau n'est plus à retaper, seul le mot de passe reste à saisir.
- **Authentification MQTT optionnelle** : case à cocher qui révèle *utilisateur* /
  *mot de passe* (stockés en NVS comme le reste). Décochée, ou utilisateur vide →
  broker **sans authentification** (défaut) : rien n'est envoyé. Côté firmware,
  `mqttConnect()` n'utilise `connect(id, user, pass)` que si un utilisateur est
  configuré.
- **Bouton « Tester WiFi + MQTT »** : teste les valeurs **saisies** (pas encore
  enregistrées) — WiFi puis MQTT — et réaffiche le formulaire prérempli avec le
  verdict (WiFi OK/échec, MQTT connecté/échec, IP obtenue), pour corriger sans
  devoir enregistrer puis attendre un cycle. **Indication visuelle pendant le
  test** : l'e-paper affiche l'étape en cours (`TEST EN COURS` + `WiFi`/`MQTT`,
  détail tronqué à la largeur utile de la police) puis revient à l'écran du
  portail, et le bouton du navigateur passe à « Test en cours... ».
- **Serveur MQTT : champ tolérant au copier-coller d'URL** — un serveur saisi
  sous forme d'URL (`http://192.168.1.2`, `mqtt://broker:1883`) était passé tel
  quel à PubSubClient, qui tentait alors de **résoudre « http://192.168.1.2 » en
  DNS** → connexion MQTT impossible. `settingsNormalize()` retire désormais le
  schéma et le chemin, et récupère le port s'il est collé au serveur. Appliqué au
  **chargement** (les valeurs déjà enregistrées sont réparées sans ressaisie), à
  l'**enregistrement**, et par le portail (bouton de test).
- **Aucune configuration réseau compilée** : `include/secrets.hpp` (et son
  template) supprimés, ainsi que `MQTT_SERVER`, `MQTT_TOPIC_BASE` et
  `WIFI_SSID`/`WIFI_PASSWORD`. Le firmware se compile **sans aucun fichier de
  credentials**. Deux **défauts de formulaire** restent, non propres au site et
  modifiables dans le portail : `MQTT_PORT = 1883` (port standard du protocole)
  et `MQTT_TOPIC_BASE_DEFAULT = "scale"` (base des topics). Les topics MQTT sont
  construits **à l'exécution** (`<base>/value`, …) au lieu de macros concaténées.
- **Démarrage** : sans configuration enregistrée, la carte entre **directement
  dans le portail** (elle n'aurait aucun réseau où publier) ; sinon cycle de
  mesure normal. Dans tous les cas, **bouton GPIO 39 maintenu au reset** → menu
  sur l'e-paper (appui court = test matériel, appui long = portail).
- **Écran du mode configuration** : logo WiFi vectoriel (3 arcs concentriques +
  point, tracés arc par arc faute de primitive dans GxEPD2), **nom du réseau AP**
  en dessous et adresse de la page. Aperçu généré (`docs/screens/config.png`).
- Le portail **coupe après 5 min** d'inactivité (il garde l'ESP éveillé en AP) ;
  sans configuration enregistrée, il redémarre en portail, l'AP reste donc
  disponible jusqu'à la saisie.

## [0.1.0] - 2026-09-10

Première version taguée, version publiée sur MQTT (`scale/version`).

### Firmware

- **Base** : registre GPIO unique (`pins.hpp`), état RTC typé (`state.hpp`),
  ordonnanceur de réveils (`scheduler.hpp`), dispatch par cause de réveil
  (`app.cpp`).
- **Capteurs HX711** : lecture des 4 pieds, **strict 4/4** (aucune extrapolation —
  un poids faux est pire qu'une absence), distinction dedock (0/4) / dégradé
  (1-3/4), publication de la qualité de mesure.
- **Cliquet descendant de publication** : le poids publié ne fait que descendre
  entre deux refills. Baisse ≥ 1 kg → publiée (consommation). Hausse < 14 kg
  (~1 sac) → **non publiée** (bruit présumé, le palier RTC reste gelé → le stock
  HA n'est jamais artificiellement gonflé). Hausse ≥ 14 kg hors FSM → **refill
  sauvage** : poids publié + event `scale/refill/event` (`bag_count: 0`).
- **Mode remplissage au bouton GPIO 39** : FSM **prix d'abord** (saisie x,xx € du
  sac) → **versement** (1 clic = +1 sac, compteur xN ; appui long = finir) →
  mesure « avant/après » → **confirmation** (court = publier, long = annuler).
  Coût total = nombre de sacs × prix du sac ; le poids mesuré alimente le stock.
- **Appui court sur l'écran principal** : mesure à la demande (cycle complet,
  publication MQTT seulement si changement).
- **Garde-fous FSM** : sommeil « bouton seul » pendant un refill (pas de timer
  qui écraserait la FSM), reprise d'un refill interrompu par un dedock
  (`refill_pending`), timeouts d'abandon, fenêtre d'inactivité de 10 min
  (`kRefillSessionTimeoutMs`) — plus de clic fantôme perdu entre deux gestes.
- **5 écrans e-paper vectoriels** (silo ÖkoFEN stylisé) : principal (silo-jauge +
  % centré dans la cuve + poids + date/batterie), remplissage, saisie du prix,
  confirmation puis résultat, dedock (silo endormi). Textes ASCII uniquement.
- **Indicateur de charge** : batterie vide + éclair vectoriel quand `isCharging()`
  (fil CHRG TP4054 → GPIO 19).
- **Mode test matériel** : au démarrage (reset / power-on), bouton GPIO 39
  **maintenu** → diagnostic autonome au bouton + e-paper (CHRG, 4 pieds au repos
  puis sous appui, résumé), sans PC ni console.
- **Cadence de mesure 18h/19h** : la mesure de 18h (juste avant l'aspiration de
  18h30) isole les mouvements de la journée (remplissages) du creux nocturne et
  sert de filet de sécurité contre le masquage d'une conso ; 19h capture la conso
  de la nuit.
- **Protection batterie basse tension** : cycle sauté sous le seuil d'arrêt,
  sommeil prolongé en mode urgence (le T5 n'a pas de déconnexion matérielle).
- **Version** : `FW_VERSION` publiée sur le topic retain `scale/version` à chaque
  connexion MQTT (le broker reflète toujours la version flashée).

### Modifs matérielles

- **Pull-ups 100 kΩ CS/RST → 3V3** (pins 10 et 12 du FPC) : maintiennent le
  SSD1680 en hibernation pendant le deep sleep (GPIO 5/16 non-RTC flottants sinon).
  **Deep sleep mesuré : 750 µA → 250 µA.**
- **Fil CHRG (TP4054, U11 pin 1) → GPIO 19** : détection de charge USB fiable.

### Home Assistant

- Packages `ha/` : capteurs MQTT, architecture **« poids = référence »** (le poids
  publié EST le stock — pas de stock comptable qui dérive), automatisations
  conso/refill/alerte, prix moyen pondéré, compteurs daily/monthly/yearly (kg et €),
  journal des remplissages, dashboard « Granulés » (vue sections), script `sync.sh`
  de déploiement vers l'instance HA (backup + `check_config` + restart).

### Docs & outillage

- `README` : structure, configuration, protocole MQTT, câblage, écrans, matériel
  (contexte + modifs appliquées), comportement dedock cible, calibration.
- `tools/render_screens.py` : rendu des écrans hors matériel (parse les polices
  Adafruit + `image.hpp`, rejoue les primitives GxEPD2) → `docs/screens/*.png`,
  embarqués dans le README. Régénérable après toute modif de `display.cpp`.

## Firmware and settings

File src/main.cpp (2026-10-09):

#include <Arduino.h>

#include "app.hpp"
#include "state.hpp"
#include "time.hpp"
#include "power.hpp"
#include "settings.hpp"

// =============================================================================
// SETUP
// =============================================================================

void setup() {
    Serial.begin(115200);
    Serial.println("\n=== ESP Scale Wakeup ===");

    // Initialise l'état persistant (reset si 1er boot / layout changé).
    stateInit();

    // Charge la configuration (NVS) AVANT tout usage réseau : WiFi et MQTT
    // lisent settingsGet().
    settingsLoad();

    // Configure le fuseau horaire AVANT tout affichage : sans ça, l'heure RTC
    // s'affiche en UTC quand le WiFi n'est pas activé ce cycle.
    timeConfigureTimezone();

    // PAS de displayInit() ici : l'écran garde sa dernière image hors tension.
    // displayShowMain() l'initialise avec reset à chaque cycle (une seule fois).

    // Route selon la cause de réveil (timer / bouton / redock / cold boot).
    appRun();
}

// =============================================================================
// LOOP (ne devrait jamais être atteint : appRun() finit toujours en deep sleep)
// =============================================================================

void loop() {
    Serial.println("ERROR: Loop should never be reached!");
    delay(1000);

    // Si on arrive ici, le deep sleep a échoué : on réessaie.
    ESP.restart();
}

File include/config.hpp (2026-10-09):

#pragma once

#include <cstdint>

// =============================================================================
// CONFIGURATION GENERALE
// =============================================================================

// Version du firmware — publiée sur le topic "<base>/version" (retain) pour
// tracer quelle version tourne sur la carte.
#define FW_VERSION "1.0.1"

// -----------------------------------------------------------------------------
// Réseau et broker — valeurs compilées : seulement des DÉFAUTS de formulaire
// -----------------------------------------------------------------------------
// Le WiFi (SSID/mot de passe) et le serveur MQTT ne sont PAS définis dans le
// code : ils vivent uniquement en NVS, saisis via le portail de configuration
// (voir settings.hpp et webconfig.hpp). Une carte sans configuration enregistrée
// démarre donc directement dans le portail.
//
// Deux constantes restent, comme valeurs initiales du formulaire (elles ne sont
// pas propres au site et restent modifiables dans le portail) :
//   - MQTT_PORT : port standard du protocole ;
//   - MQTT_TOPIC_BASE_DEFAULT : base des topics par défaut ("scale").
//
// Les topics sont construits à l'exécution : "<base>/value", "<base>/battery",
// "<base>/version", "<base>/error/on-off", "<base>/quality",
// "<base>/refill/state", "<base>/refill/event".
constexpr uint16_t MQTT_PORT = 1883;
#define MQTT_TOPIC_BASE_DEFAULT "scale"
#define MQTT_TIMEOUT_SEC 5

// Hostname réseau de la carte, annoncé en DHCP. Sans lui, le core arduino-esp32
// envoie son défaut "esp32-<3 derniers octets MAC>". Ce n'est pas un réglage de
// site : c'est l'identité fixe de l'appareil.
#define WIFI_HOSTNAME "pellet-scale"

// --- Dédoublonnage des publications ---
// La dernière valeur envoyée est mémorisée en RAM RTC (survit au deep sleep).
// On ne se réveille pas sur le réseau tant que rien n'a changé.
// Re-publication si |Δpoids| >= ce seuil (kg)
#define MQTT_SEND_DELTA_KG 1.0f
// ... ou si |Δbatterie| >= ce seuil (%)
#define MQTT_BATTERY_DELTA_PCT 5
// ... ou tous les N cycles sans envoi (heartbeat, retain rafraîchi après
// redémarrage du broker). 2 réveils/jour → 8 cycles ≈ 4 jours.
#define MQTT_HEARTBEAT_CYCLES 8

// =============================================================================
// CONFIGURATION MATERIELLE
// =============================================================================

// --- Broches ---
// Le registre des GPIO utilisés vit dans pins.hpp (source de vérité unique).
// Le sweep deep sleep et le code applicatif le consultent.

// Réveil immédiat dedock/redock via la ligne DOUT d'un pied (ext0) + pull-down
// externe ~1 MΩ côté ESP (voir pins.hpp::DOCK_WAKE_DOUT). Un HX711 alimenté en
// power-down pilote DOUT HIGH (docké), la ligne ouverte tombe LOW (dédocké).
// ⚠ Requiert la pull-down : sans elle, une ligne flottante en DEDOCKED peut
// provoquer une boucle de réveil. Tant que 0 : dédock vu au réveil timer et
// redock au poll complet de la veille nomade (≤ 15 min).
// Résistance posée (V2.4) : activé.
#define USE_DOCK_WAKE_DOUT 1

// Réveil sur changement de CHRG (début / fin de charge) en veille nomade : le
// coprocesseur ULP lit la broche toutes les 200 ms pendant le deep sleep et
// réveille la carte quand elle a changé depuis 1 s (voir armNomadeUlpWakeup()).
// L'IDF refuse ULP + ext0 : en nomade, c'est donc AUSSI l'ULP qui surveille la
// ligne DOUT (redock) à la place d'ext0. Exige CHRG sur une broche RTC
// (pins.hpp : GPIO 34, pull-up externe 10 kΩ).
// Surchargeable à la compilation (mesure de conso comparative, sans ULP) :
//   PLATFORMIO_BUILD_FLAGS="-DUSE_CHRG_ULP=0" pio run
#ifndef USE_CHRG_ULP
#define USE_CHRG_ULP 1
#endif

// Coupure matérielle de l'alimentation de l'écran (T5 V2.4 uniquement :
// GPIO 12 = EPD_PWR_EN, absent sur la V2.3.1). Remplace le hibernate()
// logiciel + pull-ups 100 kΩ CS/RST de la V2.3.1 par une coupure totale de
// la LDO écran pendant le deep sleep. Contrepartie : la RAM de trame du
// SSD1680 NE SURVIT PLUS au sommeil -> un FULL refresh est forcé au premier
// draw de chaque réveil (voir canPartial(), display.cpp).
// Polarité VALIDÉE sur banc (V2.4) : LOW = écran coupé, HIGH = écran alimenté
// (~1 mA au PPK). NB : la coupure supprime la fuite de la dalle mais PAS le
// plancher de la carte -> deep sleep mesuré 192 µA à vide (écran branché ou non,
// cf. issue LilyGO #66 : « 30 µA » seulement avec une modif matérielle de
// l'EN du LDO U6).
#define USE_EPD_PWR_CUTOFF 1

// Ratio du pont diviseur batterie intégré au TTGO T5
// Appliqué à la tension de la broche en mV calibrée (analogReadMilliVolts).
// Valeur de départ (2 × 100 kΩ) à recaler sur la V2.4 au PPK2 : voir
// docs/CONSOMMATION.md#lecture-de-la-batterie.
#define BATTERY_VOLTAGE_RATIO 2.0f
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

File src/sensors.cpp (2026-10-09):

#include "sensors.hpp"
#include "pins.hpp"
#include "power.hpp"     // powerReleaseSensorHold() (pads SCK tenues en sleep)
#include "settings.hpp" // calibration persistée (settingsGetCal)

// =============================================================================
// CAPTEURS GLOBAUX
// =============================================================================

static HX711 scale_1;
static HX711 scale_2;
static HX711 scale_3;
static HX711 scale_4;

static HX711* scales[4] = {&scale_1, &scale_2, &scale_3, &scale_4};

// Capteurs valides au dernier sensorsReadTotalWeight() (0-4)
static uint8_t g_valid_sensors = 0;
// Masque des capteurs prêts au dernier sensorsInit() (bit i = capteur i)
static uint8_t g_ready_mask = 0;

uint8_t sensorsGetValidCount() {
    return g_valid_sensors;
}

// Configuration des broches pour chaque capteur (registre unique pins.hpp)
static const gpio_num_t dout_pins[4] = {
    pins::LC1_DOUT,
    pins::LC2_DOUT,
    pins::LC3_DOUT,
    pins::LC4_DOUT
};

static const gpio_num_t sck_pins[4] = {
    pins::LC1_SCK,
    pins::LC2_SCK,
    pins::LC3_SCK,
    pins::LC4_SCK
};

// =============================================================================
// IMPLEMENTATION
// =============================================================================

// Applique la calibration courante (NVS, défauts compilés si absente) aux objets
// HX711. Appelée à l'init ET à chaud par le portail après un enregistrement.
void sensorsApplyCalibration() {
    const Calibration& cal = settingsGetCal();
    for (uint8_t i = 0; i < 4; i++) {
        scales[i]->set_scale(cal.c[i]);
        scales[i]->set_offset(cal.z[i]);
    }
}

void sensorsInit() {
    Serial.println("Initializing HX711 sensors...");

    // Au réveil d'un deep sleep, les SCK sont tenues hautes par le domaine RTC
    // (voir prepareDeepSleep). On rend les pads au chemin numérique AVANT
    // begin() : tant qu'elles appartiennent au RTC, pinMode()/digitalWrite()
    // n'ont pas prise dessus (l'HX711 resterait éteint / muet).
    powerReleaseSensorHold();

    uint32_t t0 = millis();

    // Configure les broches de chaque capteur et applique la calibration
    for (uint8_t i = 0; i < 4; i++) {
        scales[i]->begin((uint8_t)dout_pins[i], (uint8_t)sck_pins[i]);
    }
    sensorsApplyCalibration();
    Serial.printf("  begin: %lums\n", (unsigned long)(millis() - t0));

    // Sort les HX711 de leur power-down (maintenu pendant le deep sleep)
    sensorsPowerOn();
    Serial.printf("  poweron: %lums\n", (unsigned long)(millis() - t0));

    // Pull-up sur les DOUT PENDANT la lecture : un DOUT non branché (capteur
    // absent) est tiré HIGH → is_ready() reste false (il attend LOW). Sans ça,
    // le pin flotte et is_ready() renvoie true aléatoirement → faux "0kg".
    // Les pull-ups sont recoupés en deep sleep (voir prepareDeepSleep).
    for (uint8_t i = 0; i < 4; i++) {
        gpio_pullup_en(dout_pins[i]);
    }

    // Attend que TOUS les capteurs soient prêts sous une deadline globale
    // (un HX711 à 10Hz produit une conversion toutes les ~100ms, donc en
    // pratique tous sont prêts en ~200ms ; le timeout ne sert qu'au cas où
    // un capteur est débranché). Bien plus rapide que d'attendre chaque
    // capteur séquentiellement.
    const uint32_t start_ms = millis();
    uint8_t ready_mask = 0;

    while (ready_mask != 0x0F && (millis() - start_ms) < SENSOR_READY_TIMEOUT_MS) {
        for (uint8_t i = 0; i < 4; i++) {
            if (!(ready_mask & (1u << i)) && scales[i]->is_ready()) {
                ready_mask |= (1u << i);
                Serial.printf("Scale %d ready (%lums)\n", i + 1,
                             (unsigned long)(millis() - start_ms));
            }
        }
        delay(5);
    }
    g_ready_mask = ready_mask;
    Serial.printf("  ready wait: %lums (mask=%u)\n",
                  (unsigned long)(millis() - t0), ready_mask);

    // Rapporte les capteurs qui n'ont jamais répondu
    for (uint8_t i = 0; i < 4; i++) {
        if (!(ready_mask & (1u << i))) {
            Serial.printf("Error: Scale %d not ready!\n", i + 1);
        }
    }
}

float sensorsReadTotalWeight(uint8_t attempts) {
    float total_weight = 0.0f;
    uint8_t valid_sensors = 0;
    float weights[4] = {0.0f, 0.0f, 0.0f, 0.0f};
    uint8_t valid_reads[4] = {0, 0, 0, 0}; // lectures valides par capteur

    // ATTENTION : get_units() → read() → wait_ready() est une boucle INFINIE
    // sur un capteur absent (DOUT qui reste HIGH). On ne lit QUE les capteurs
    // confirmés prêts à l'init (g_ready_mask) — sinon on sort immédiatement
    // (dedock) sans jamais risquer le blocage.
    if (g_ready_mask == 0) {
        g_valid_sensors = 0;
        Serial.println("No sensor ready at init, skipping reads (dedock)");
        return -1.0f;
    }

    for (uint8_t attempt = 0; attempt < attempts; attempt++) {
        for (uint8_t i = 0; i < 4; i++) {
            if (!(g_ready_mask & (1u << i))) continue; // jamais prêt à l'init
            HX711* scale = scales[i];
            // Anti-blocage : wait_ready() seul boucle INDÉFINIMENT si le DOUT
            // reste HIGH (capteur débranché / mort en cours de cycle). On borne
            // l'attente : wait_ready_timeout(ms, délai) → false si absent.
            // 500 ms par lecture est largement suffisant (conversion à 10 Hz).
            if (scale->wait_ready_timeout(500, 1)) {
                float reading = scale->get_units(1);
                // Filtre de plausibilité : borne PHYSIQUE du pied (4 cellules de
                // 50 kg = 200 kg). Au-delà, le pied sature : la valeur est
                // impossible et doit être rejetée (le pied devient invalide, donc
                // la mesure 4/4 échoue → aucune publication) plutôt que d'être
                // publiée comme une hausse légitime (faux refill sauvage).
                if (reading >= -FOOT_CAPACITY_KG && reading <= FOOT_CAPACITY_KG) {
                    weights[i] += reading;
                    valid_reads[i]++;
                }
            }
        }
        if (attempt + 1 < attempts) delay(SENSOR_READ_DELAY_MS);
    }
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

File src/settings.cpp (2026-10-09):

#include "settings.hpp"

#include "config.hpp"

#include <Preferences.h>
#include <cstring>

// =============================================================================
// IMPLEMENTATION
// =============================================================================

static const char* kNvsNamespace = "scale";

static Settings g_settings;
static SiloConfig g_silo;
static Calibration g_cal;
static bool g_loaded = false;
static bool g_stored = false; // une config a-t-elle été enregistrée en NVS ?

// Calibration par défaut = constantes compilées (config.hpp). Utilisées tant
// qu'aucune calibration n'a été enregistrée via le portail.
static void applyCalDefaults(Calibration& cal) {
    cal.z[0] = Z_FACTOR_1; cal.c[0] = C_FACTOR_1;
    cal.z[1] = Z_FACTOR_2; cal.c[1] = C_FACTOR_2;
    cal.z[2] = Z_FACTOR_3; cal.c[2] = C_FACTOR_3;
    cal.z[3] = Z_FACTOR_4; cal.c[3] = C_FACTOR_4;
}

// Défauts du silo = constantes compilées. Le seuil « niveau bas » est défini en
// POURCENTAGE dans config.hpp (SILO_LOW_ALERT_PCT) et stocké en kg : sa valeur
// par défaut est donc recalculée à partir de la capacité pour que le comportement
// d'aujourd'hui soit reproduit à l'identique.
static void applySiloDefaults(SiloConfig& silo) {
    silo.capacity_kg = TANK_FULL_KG;
    silo.low_kg      = TANK_FULL_KG * (float)SILO_LOW_ALERT_PCT / 100.0f;
    silo.bag_kg      = BAG_KG;
}

// Heure d'aspiration par défaut : 18h30, l'horaire pour lequel ce firmware a été
// écrit (réveils à 18h00 et 19h00, soit ±30 min). Une carte sans réglage est donc
// une carte qui se comporte EXACTEMENT comme avant.
constexpr uint16_t kDefaultAspirationMin = 18 * 60 + 30;

// Un réglage du silo hors bornes rendrait l'affichage faux (taux > 100 %,
// seuil au-dessus de la capacité) : on borne au chargement comme à l'écriture.
static bool siloIsSane(const SiloConfig& s) {
    return s.capacity_kg > 0.0f && s.capacity_kg <= 5000.0f &&
           s.low_kg >= 0.0f && s.low_kg <= s.capacity_kg &&
           s.bag_kg >= 1.0f && s.bag_kg <= 50.0f;
}

// Copie une chaîne en bornant la longueur (garde toujours le NUL final).
static void copyStr(char* dst, size_t len, const char* src) {
    if (len == 0) return;
    strncpy(dst, src ? src : "", len - 1);
    dst[len - 1] = '\0';
}

void settingsNormalize(Settings& s) {
    // Hors 0..1439, l'ordonnanceur calculerait des créneaux aberrants (un
    // réveil à 25h) : on ramène dans la journée.
    if (s.aspiration_min >= 1440) s.aspiration_min = kDefaultAspirationMin;

    // Schéma éventuel ("http://", "mqtt://"…) : PubSubClient attend un hôte seul.
    static const char* const kSchemes[] = {
        "http://", "https://", "mqtt://", "mqtts://", "tcp://", "ssl://"
    };
    for (const char* sc : kSchemes) {
        const size_t n = strlen(sc);
        if (strncmp(s.mqtt_server, sc, n) == 0) {
            memmove(s.mqtt_server, s.mqtt_server + n,
                    strlen(s.mqtt_server + n) + 1);
            break;
        }
    }
    // Chemin éventuel ("hote/valeur").
    if (char* slash = strchr(s.mqtt_server, '/')) *slash = '\0';
    // Port collé au serveur ("hote:1883") → champ port.
    if (char* colon = strchr(s.mqtt_server, ':')) {
        long p = atol(colon + 1);
        if (p >= 1 && p <= 65535) {
            *colon = '\0';
            s.mqtt_port = (uint16_t)p;
        }
    }
}

// Aucune valeur propre au site n'est compilée : WiFi et serveur MQTT viennent
// uniquement de la NVS (portail). Seuls deux DÉFAUTS de formulaire sont posés
// ici, car ils ne dépendent pas du site et restent modifiables dans le portail :
// le port MQTT (port standard du protocole) et la base des topics ("scale").
static void applyDefaults(Settings& s) {
    s.wifi_ssid[0]   = '\0';
    s.wifi_pass[0]   = '\0';
    s.mqtt_server[0] = '\0';
    s.mqtt_user[0]   = '\0';
    s.mqtt_pass[0]   = '\0';
    s.mqtt_port      = MQTT_PORT;
    s.aspiration_min = kDefaultAspirationMin;
    copyStr(s.mqtt_base, sizeof(s.mqtt_base), MQTT_TOPIC_BASE_DEFAULT);
}
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
